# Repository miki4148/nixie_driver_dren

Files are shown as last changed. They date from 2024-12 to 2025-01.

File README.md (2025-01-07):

# Modular nixie tube clock system
Project overview

A versatile and customizable driver for Nixie tube clocks. This project focuses on developing hardware and firmware to drive Nixie tubes, allowing you to create various retro-style displays with ease.

---

## Features

- **Modular design**: Interchangeable pieces with efficient management of high voltages required by nixie tubes.
- **Customizable Firmware**: Adjust timing  of various displayed things at will.
- **Support for Various Tubes**: Compatible with [IN-12A](https://www.tube-tester.com/sites/nixie/dat_arch/IN-12A_IN-12B_03.pdf), [IN-12B](https://www.tube-tester.com/sites/nixie/dat_arch/IN-12A_IN-12B_03.pdf) and more.
- **Easy Assembly**: Simple PCB design with detailed instructions.
- **Real-Time Clock Integration**: In the future, RTC modules may be integrated into the project.

---

## Hardware

### Components

1. Nixie Tubes (e.g. [IN-12A](https://www.tube-tester.com/sites/nixie/dat_arch/IN-12A_IN-12B_03.pdf) or [IN-12B](https://www.tube-tester.com/sites/nixie/dat_arch/IN-12A_IN-12B_03.pdf))
2. Regulated Power Supply (12V DC output)
3. Microcontroller (e.g. STM32 family)
4. Maybe RTC Module? (e.g. DS3231)
5. Darlington Arrays (e.g. SN75468)
6. Demultiplexers (e.g. CD4028B)
7. Boost controller ([UCC380x](https://www.ti.com/lit/ds/symlink/ucc3800.pdf) family)
8. Resistors, Capacitors, Connectors etc.
9. PCB (Custom-designed for this project)

## Driver + PSU

The circuit consists of a boost converter which steps up the supply voltage to 170VDC. Such voltage is sufficient for ionization of the low-pressure gas mixture inside the tube at room temperature (without the need of white-hot cathode).

After long battle against procrastination, layout for the driver board emerged (see [driver schematic](/files/NixieDriverEvenSmallerNoDot/NixieDriverEvenSmallerNoDot.pdf)). Detailed description will follow in subsequent sections.

<p align="center">
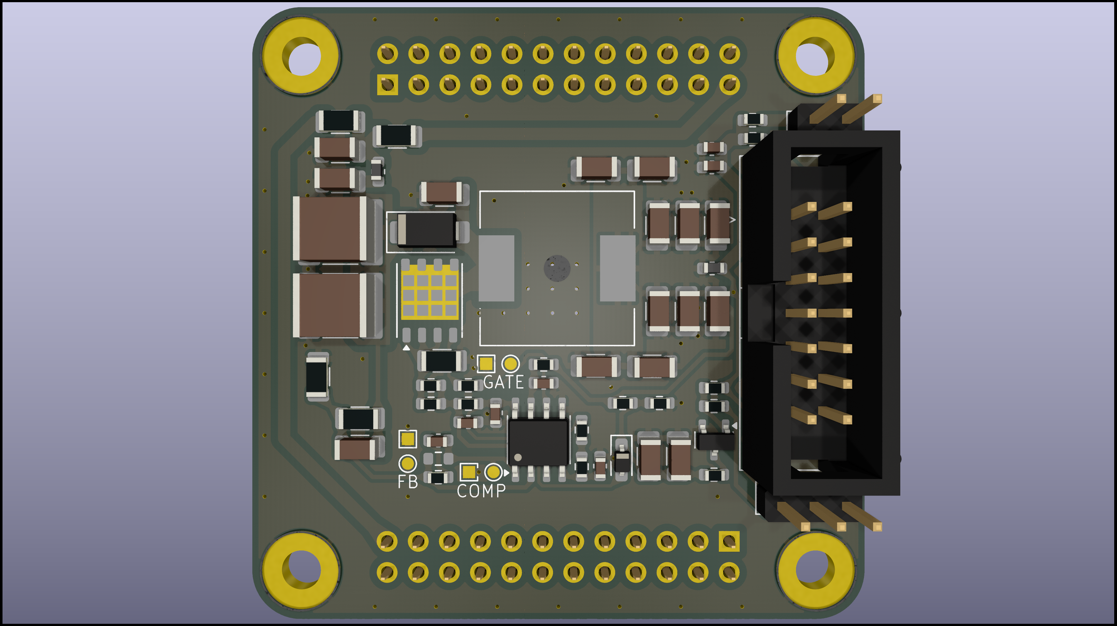
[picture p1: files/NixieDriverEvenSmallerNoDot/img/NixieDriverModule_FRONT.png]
  
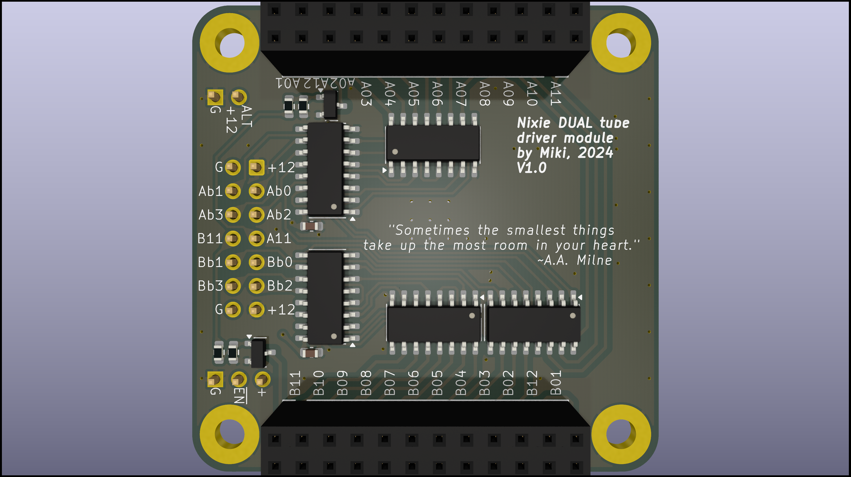
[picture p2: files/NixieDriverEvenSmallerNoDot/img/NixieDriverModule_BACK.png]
  
</p>

<p align="center">
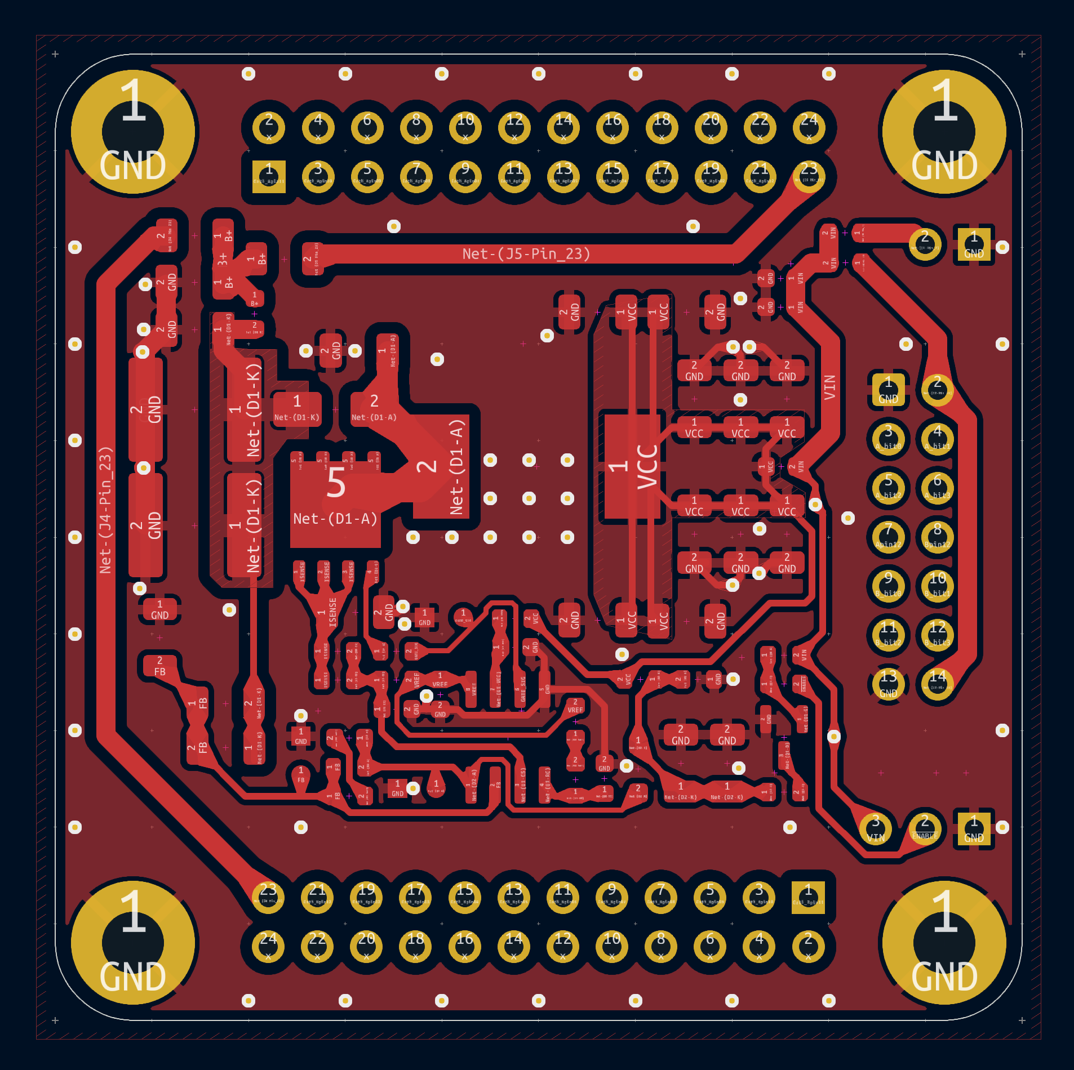
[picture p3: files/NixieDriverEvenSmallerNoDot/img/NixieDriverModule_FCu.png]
FCu
  
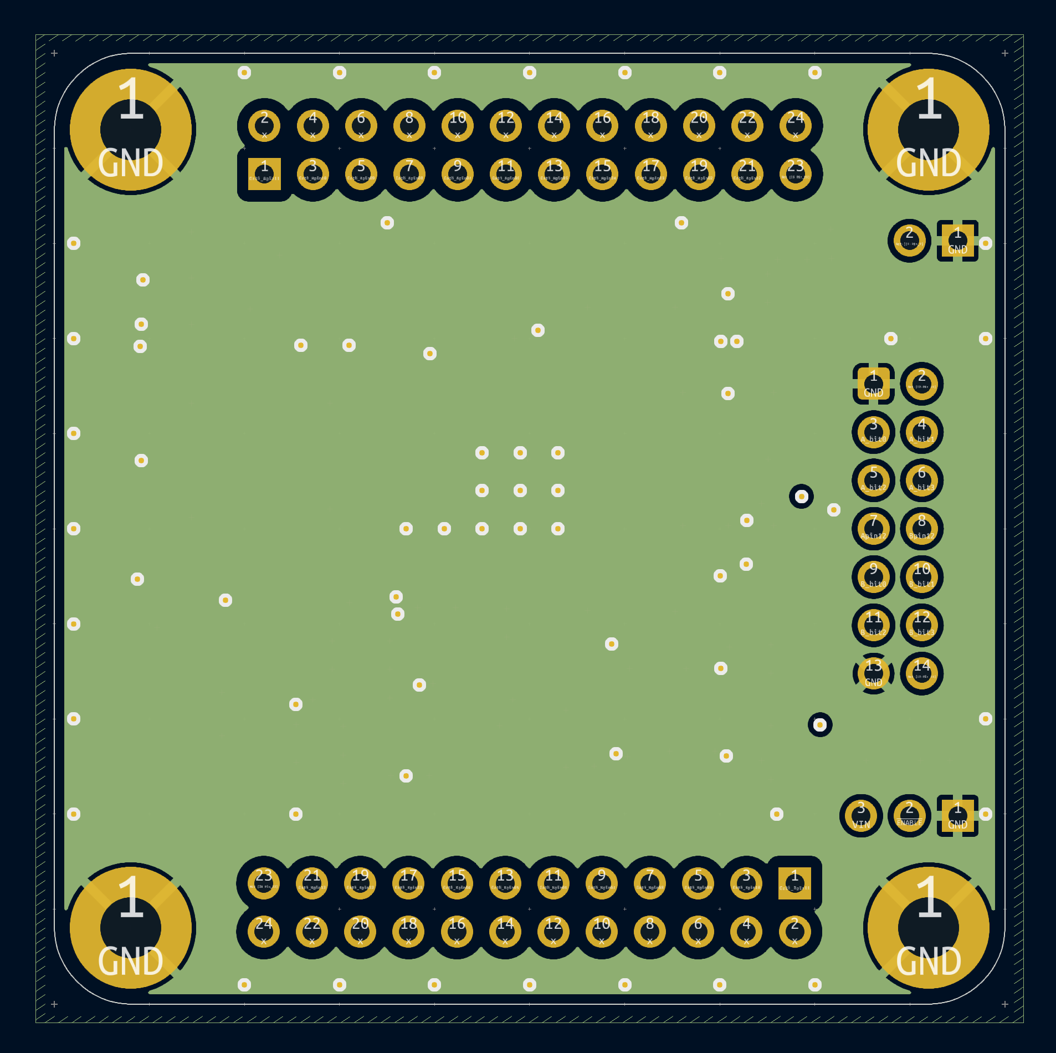
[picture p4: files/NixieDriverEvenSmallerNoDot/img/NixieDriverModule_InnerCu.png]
InnerCu
  
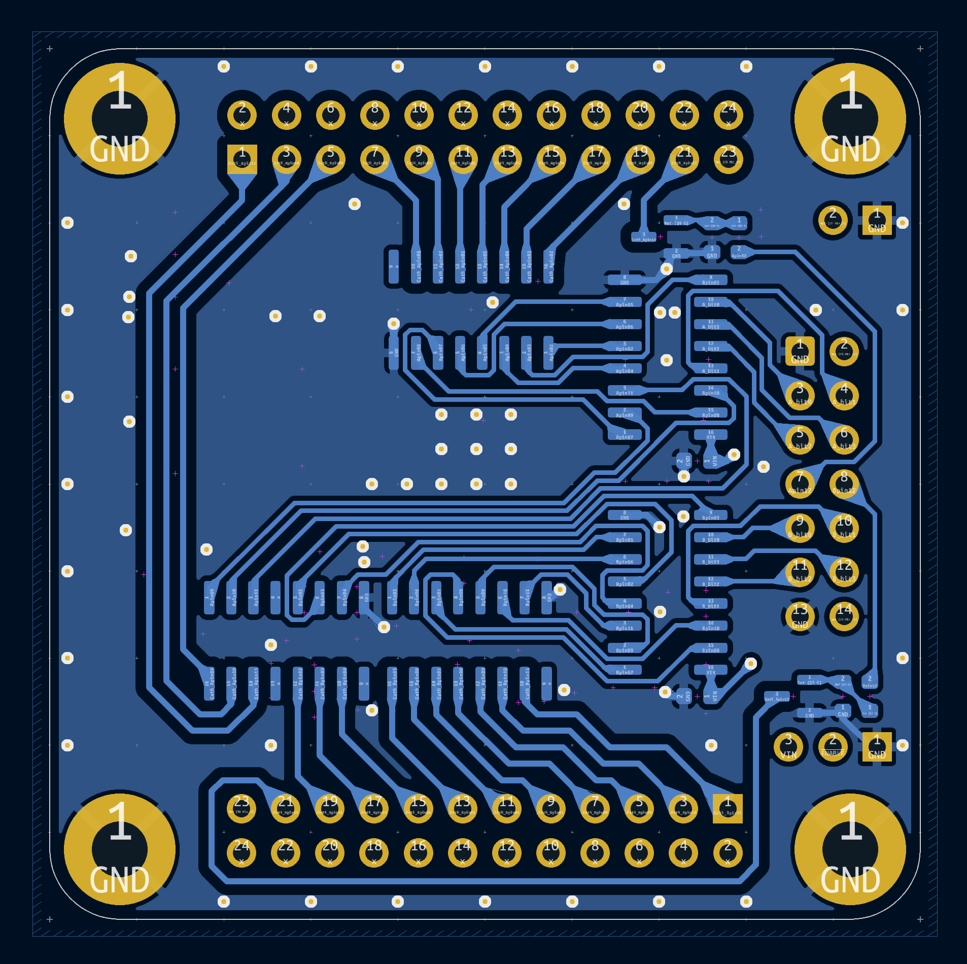
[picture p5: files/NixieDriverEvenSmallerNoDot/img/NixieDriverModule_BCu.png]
BCu
  
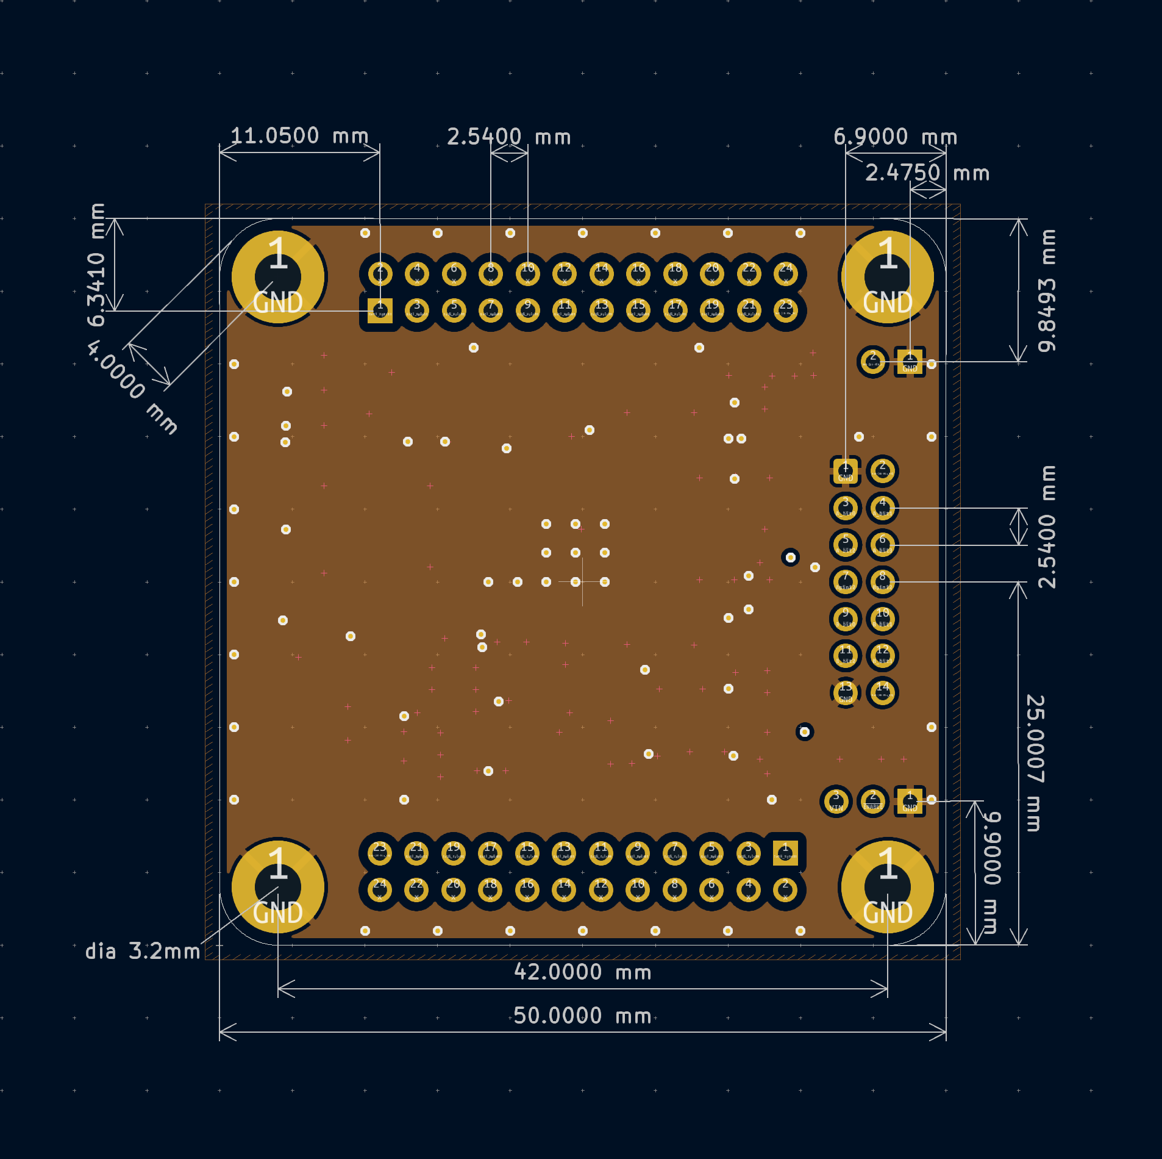
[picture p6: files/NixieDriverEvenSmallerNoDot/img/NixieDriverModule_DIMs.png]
Dimensions
  
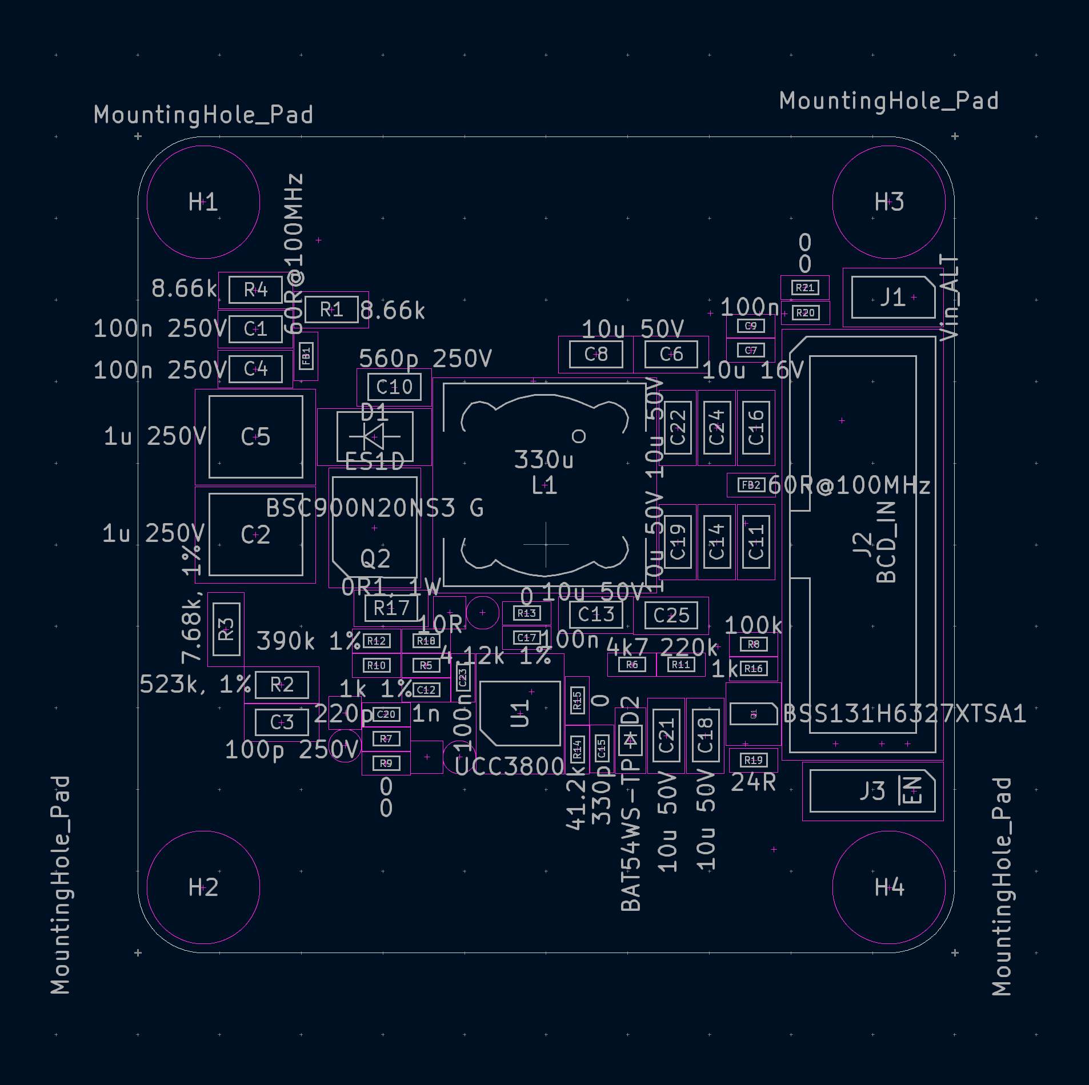
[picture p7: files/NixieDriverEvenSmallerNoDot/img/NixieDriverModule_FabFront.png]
FFab
  
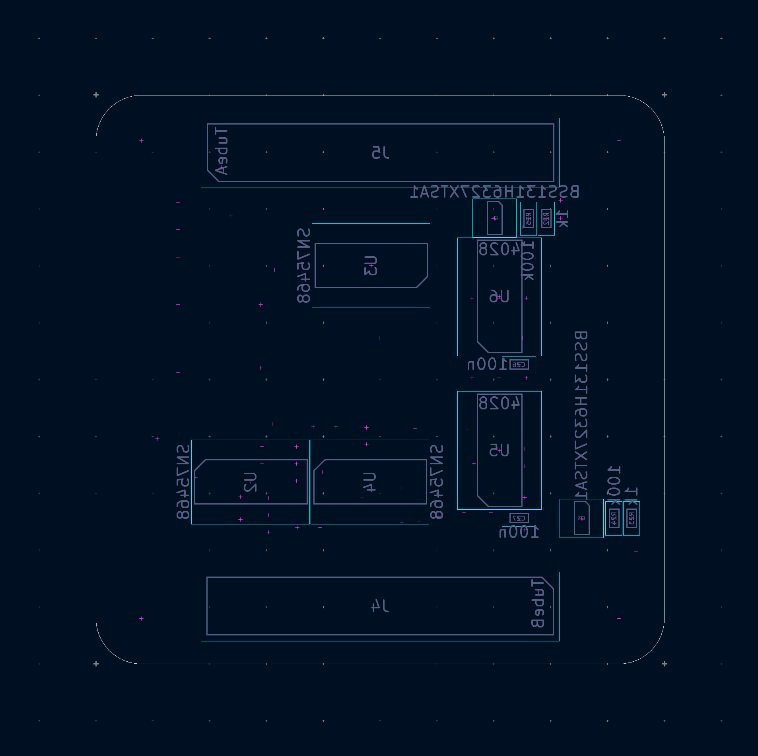
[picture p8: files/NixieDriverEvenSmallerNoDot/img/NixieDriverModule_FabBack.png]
BFab
  
</p>

Insulation Displacement Cable connector was chosen as the main medium of communication w/ the micro. This was a direct result of author's recent traumatic experiances and many hours of fruitless work trying to wire previous device using old solid-copper wires which were nearly unsolderable and brittle beyond comprehension. So ribbon cable it is.
Alternative and secondary I/Os were banished to ordinary pin headers for simplicity.

The other half of the circuit is basically massive demultiplexing and buffering array. The good news is that not every cathode needs to be operated idependently but rather only one (two maybe) digit per tube lights up at one time. This points to BCD (binary-coded decimal) converters (4028 IC used) and a simple buffering for commas as they may have to be used independently.

Note author's love for hardcore poetry insertion.

## Dual tube adapter

Someone must hold the tubes in place so here it is: (see [adapter schematic](/files/NixieDriverTwoTubesSockets/NixieDriverTwoTubesSockets_Schematic.pdf))

<p align="center">
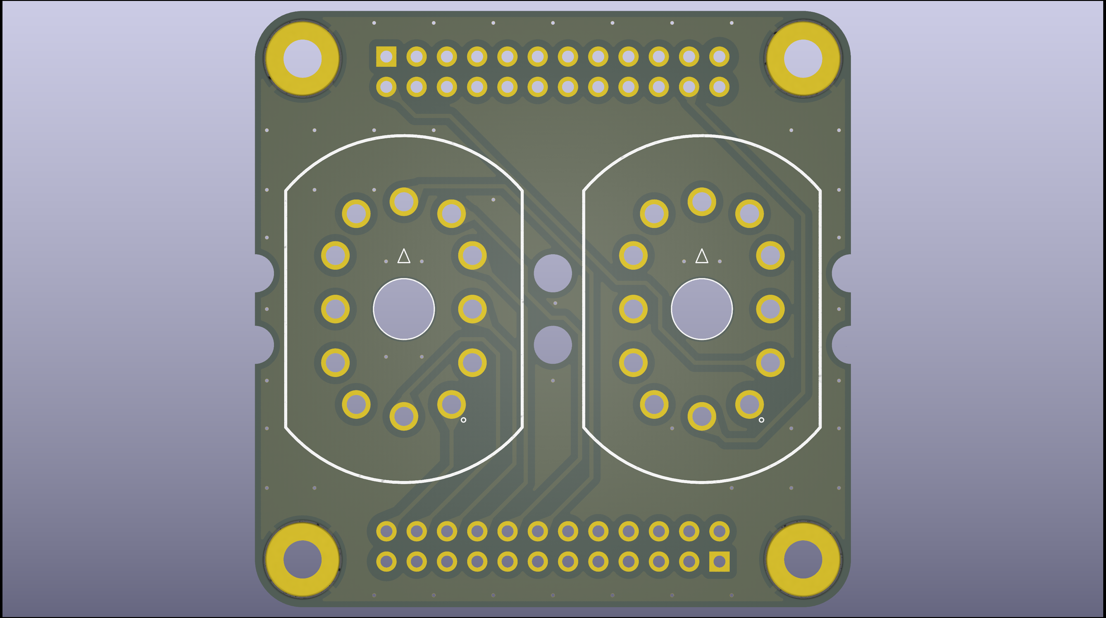
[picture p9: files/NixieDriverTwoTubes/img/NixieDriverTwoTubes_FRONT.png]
Tube holder front
  
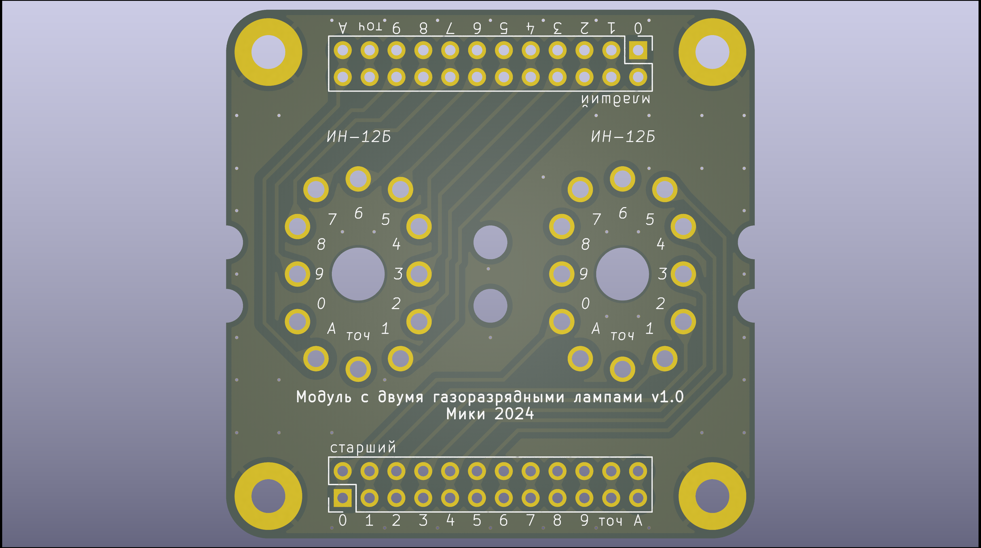
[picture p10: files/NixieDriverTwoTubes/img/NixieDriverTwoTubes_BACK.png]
Tube holder back
  
</p>
Holes in pcb in the middle of the tubes' footprints are an answer to the glass short feature at the base, a remainder after sealing process.
Other holes increase versatility in case someone wished to insert leds in them to achieve obligatory flashing in the space between glowing numerals.
Note the attempt to match writing on the pcb to native Muttersprache of the late glassblowers responsible for birthing of IN-12s.

### Dual tube adapter w/ sockets

Socket adaptation requires different footprint and much denser layout.

<p align="center">
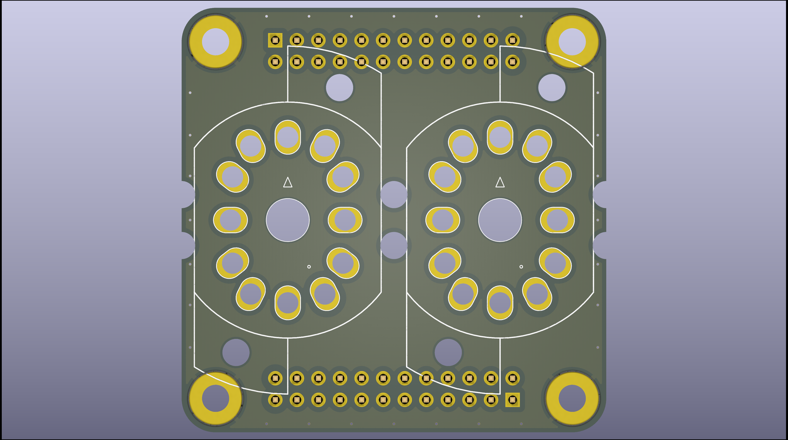
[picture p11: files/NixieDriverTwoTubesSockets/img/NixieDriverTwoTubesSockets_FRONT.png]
NixieDriverTwoTubesSockets_FRONT
  
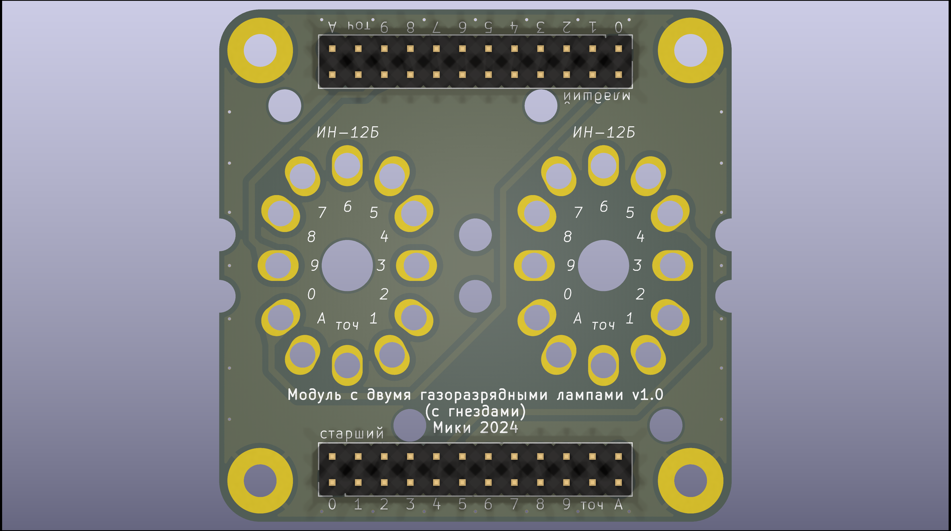
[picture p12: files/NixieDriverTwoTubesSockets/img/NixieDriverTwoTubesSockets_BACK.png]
NixieDriverTwoTubesSockets_BACK
  
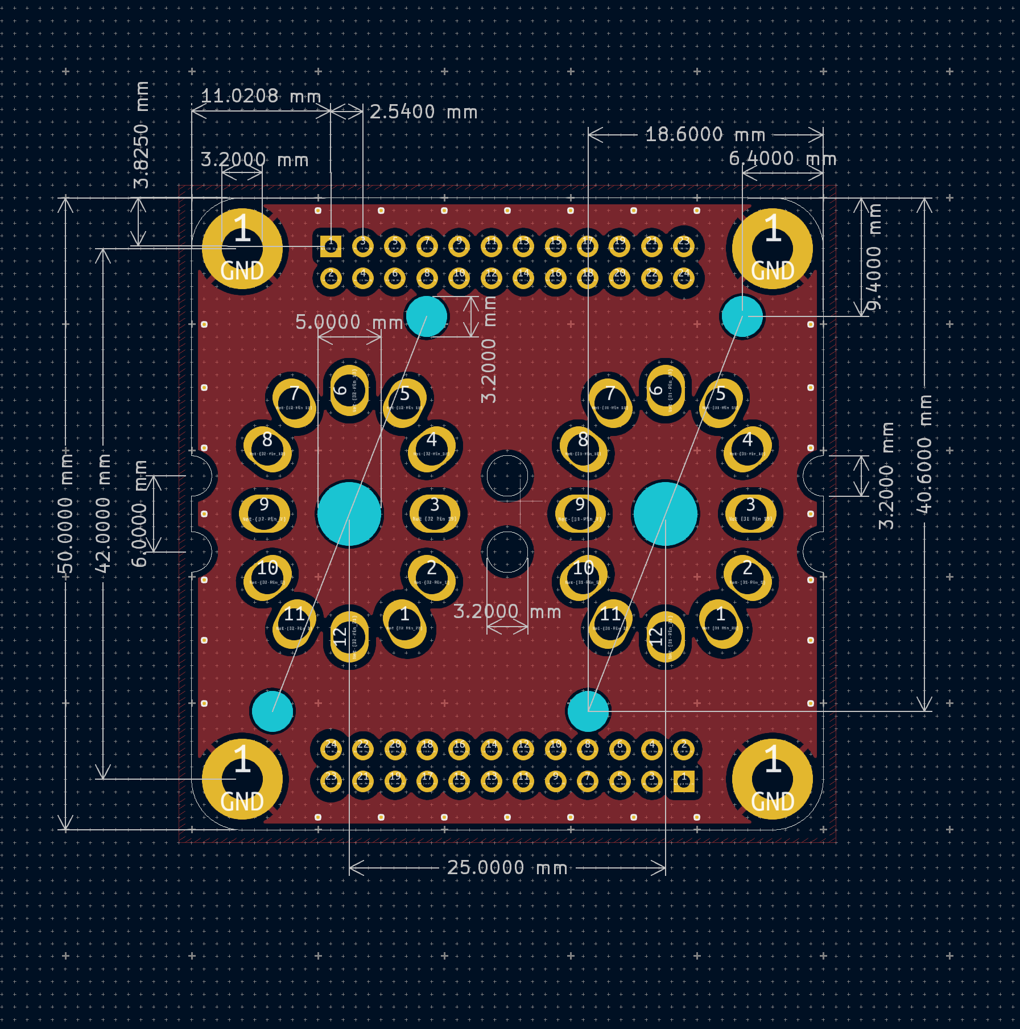
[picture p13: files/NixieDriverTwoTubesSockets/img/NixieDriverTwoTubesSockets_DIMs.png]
NixieDriverTwoTubesSockets_DIMs
  
</p>
6 layers, yes:
<p align="center">
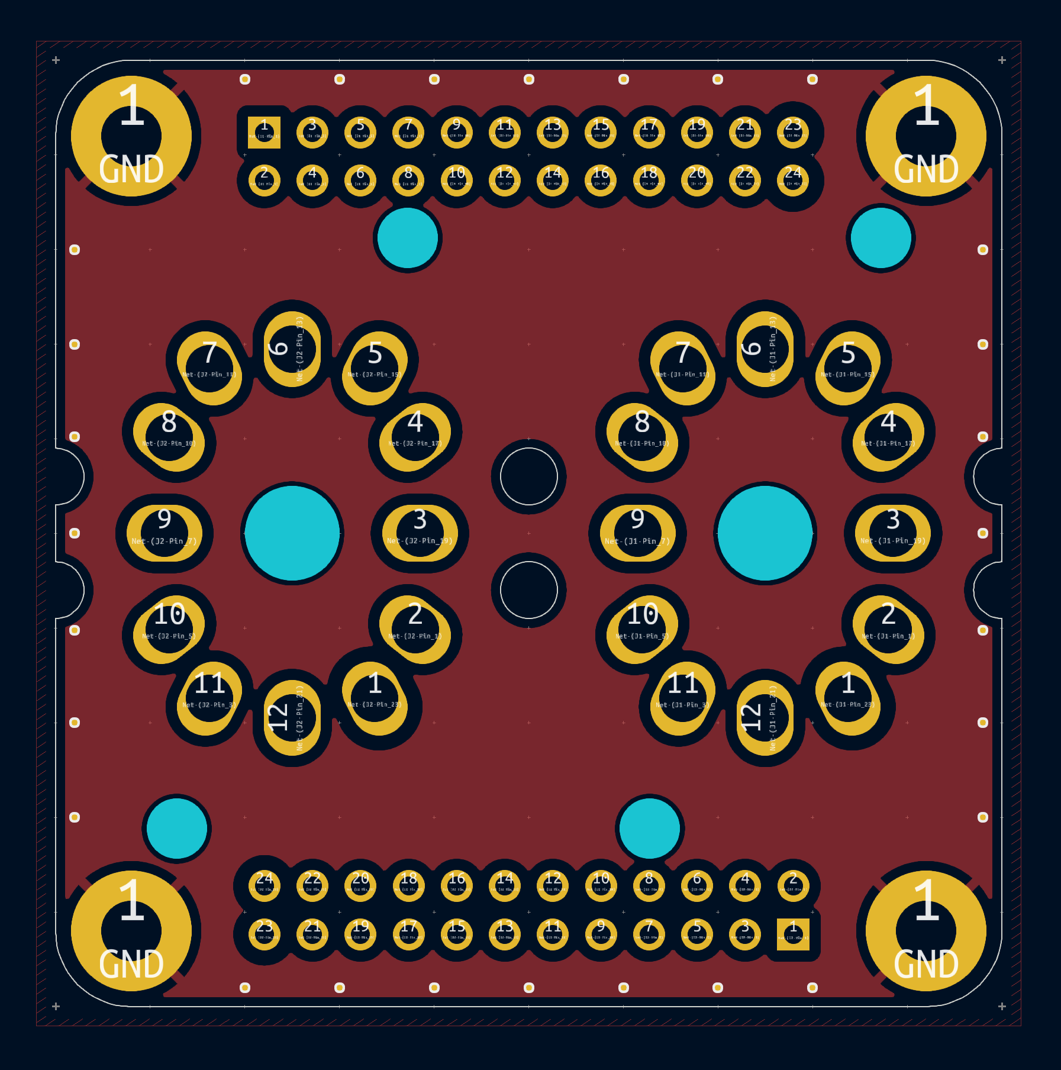
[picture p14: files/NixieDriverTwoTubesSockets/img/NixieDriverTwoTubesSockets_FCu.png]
  
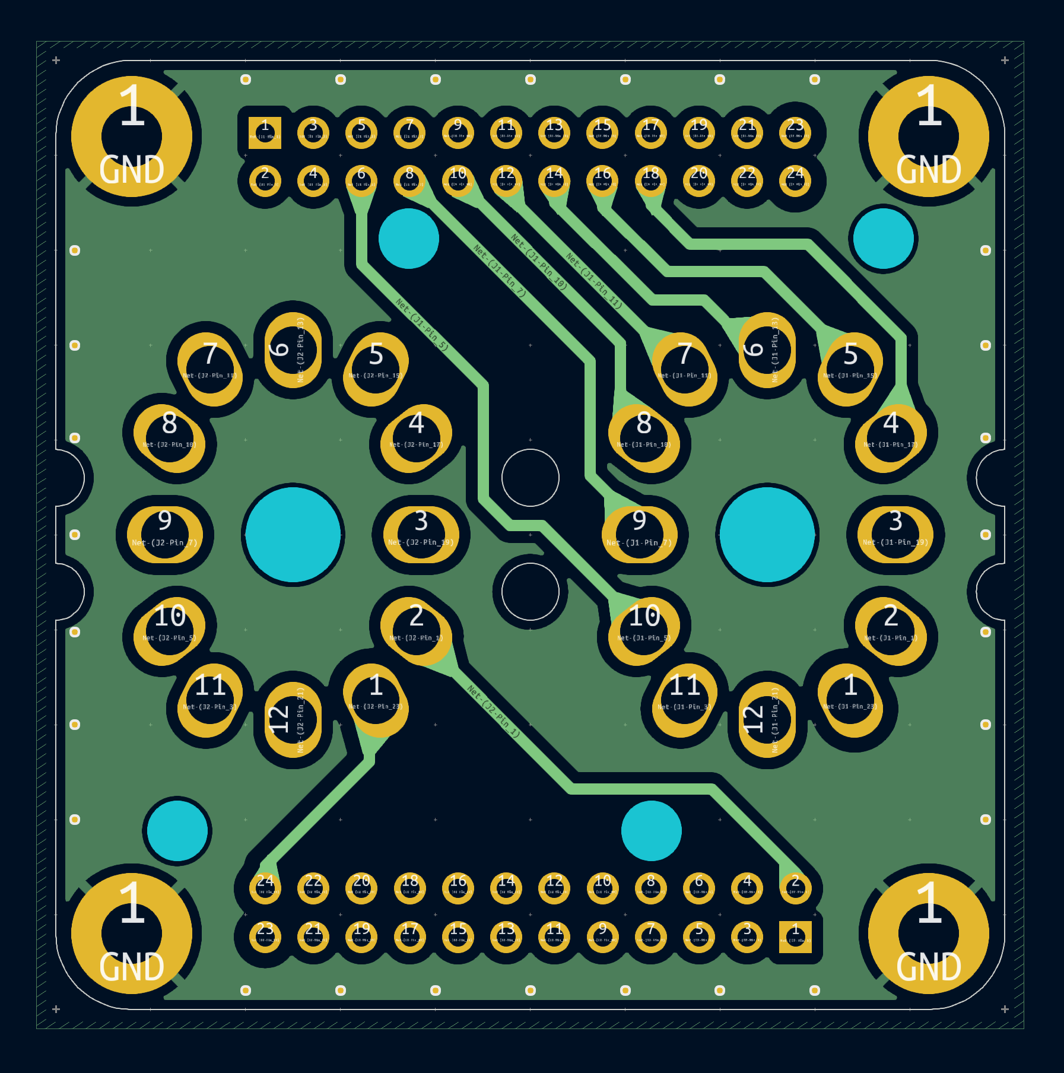
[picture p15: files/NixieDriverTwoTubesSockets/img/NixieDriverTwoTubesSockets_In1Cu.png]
  
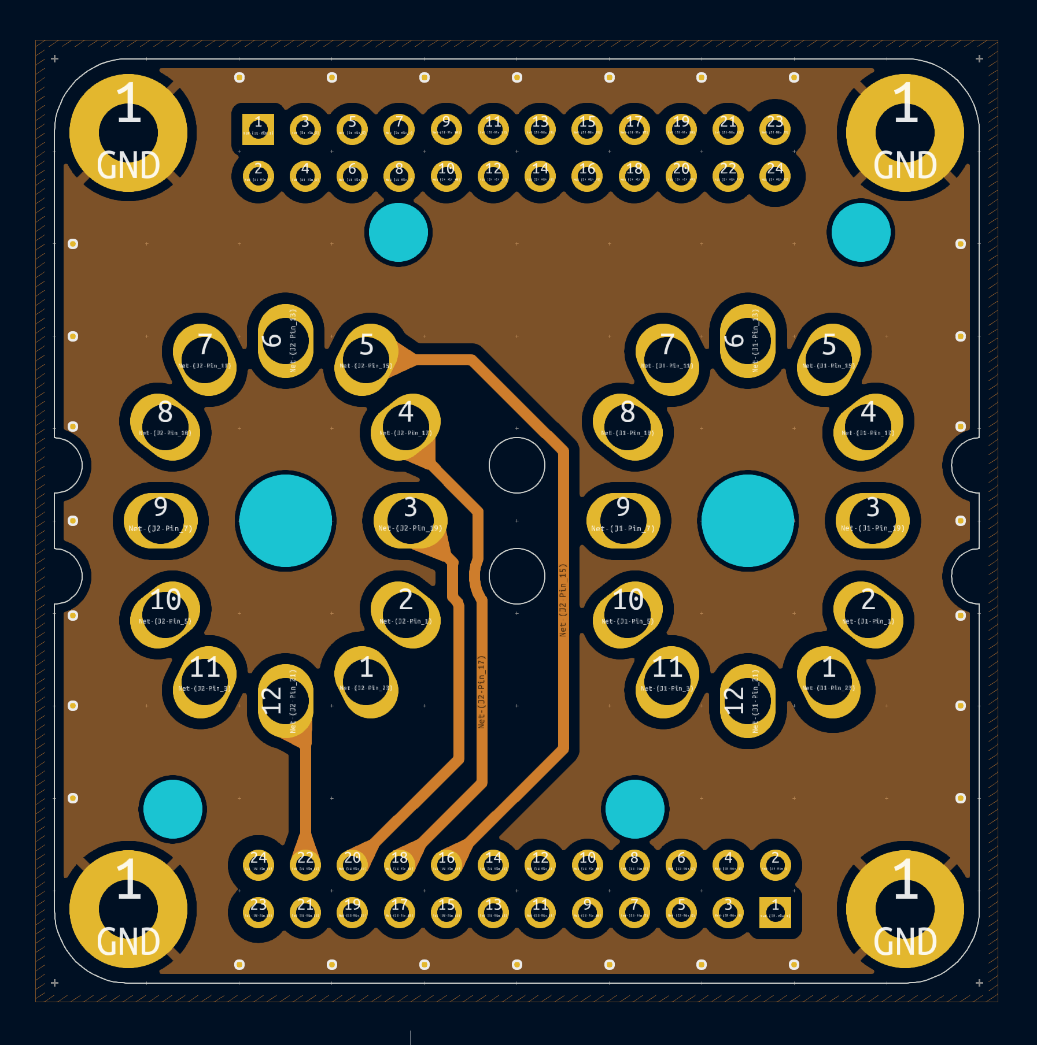
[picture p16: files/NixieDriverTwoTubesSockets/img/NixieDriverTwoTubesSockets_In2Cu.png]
  
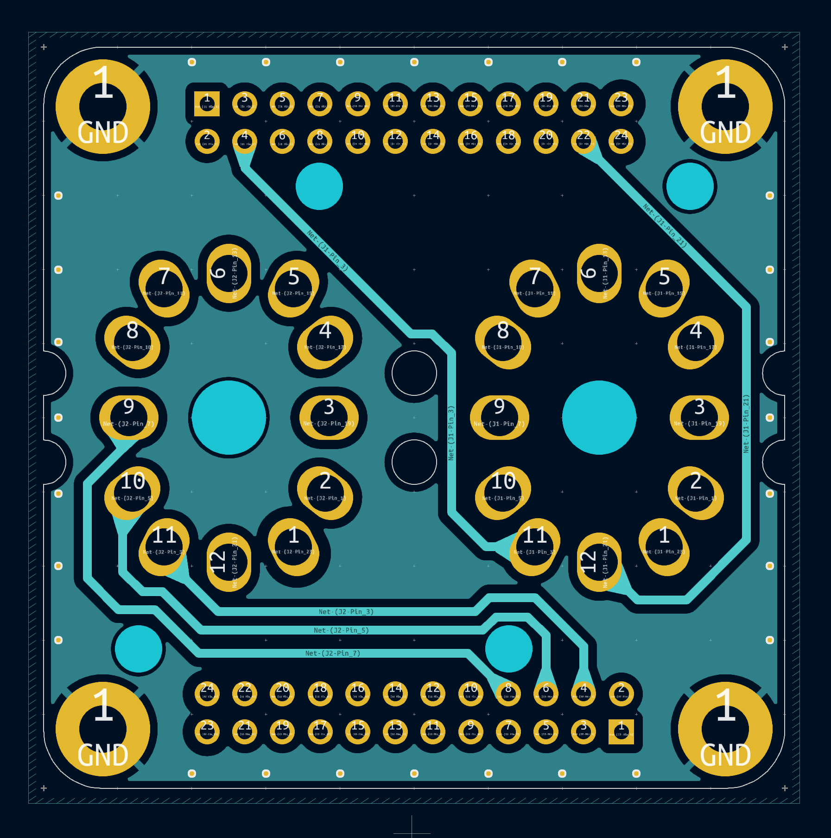
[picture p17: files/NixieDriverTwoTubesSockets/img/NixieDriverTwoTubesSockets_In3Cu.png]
  
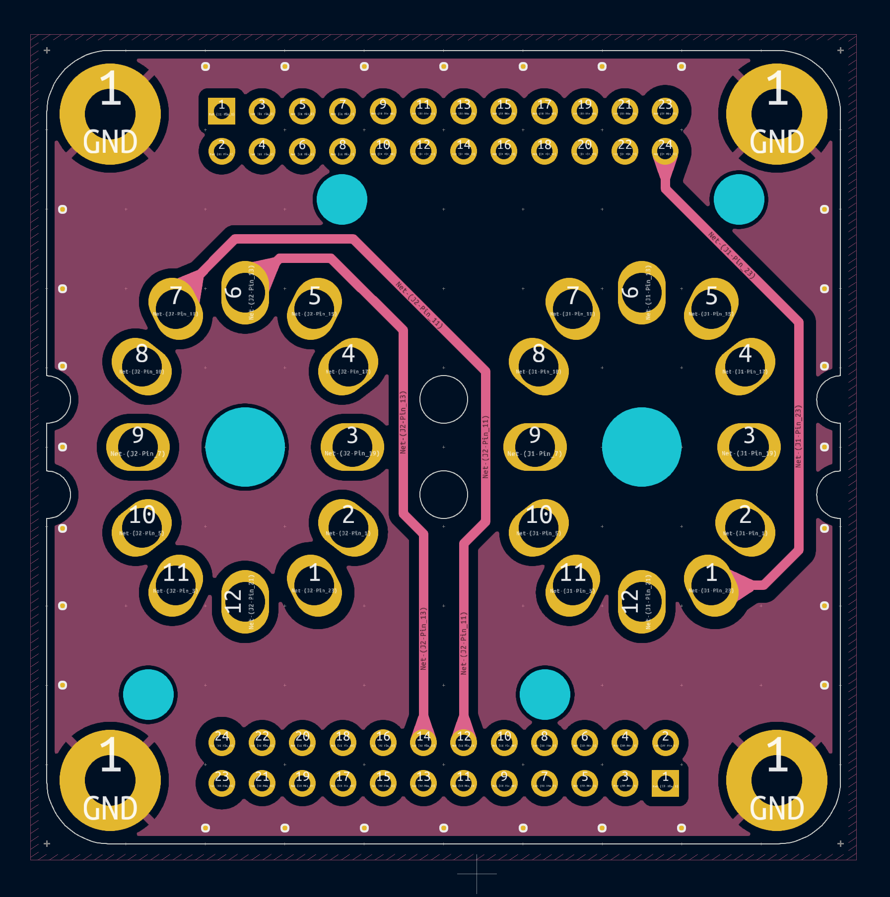
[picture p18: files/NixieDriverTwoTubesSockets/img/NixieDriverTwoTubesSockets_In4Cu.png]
  
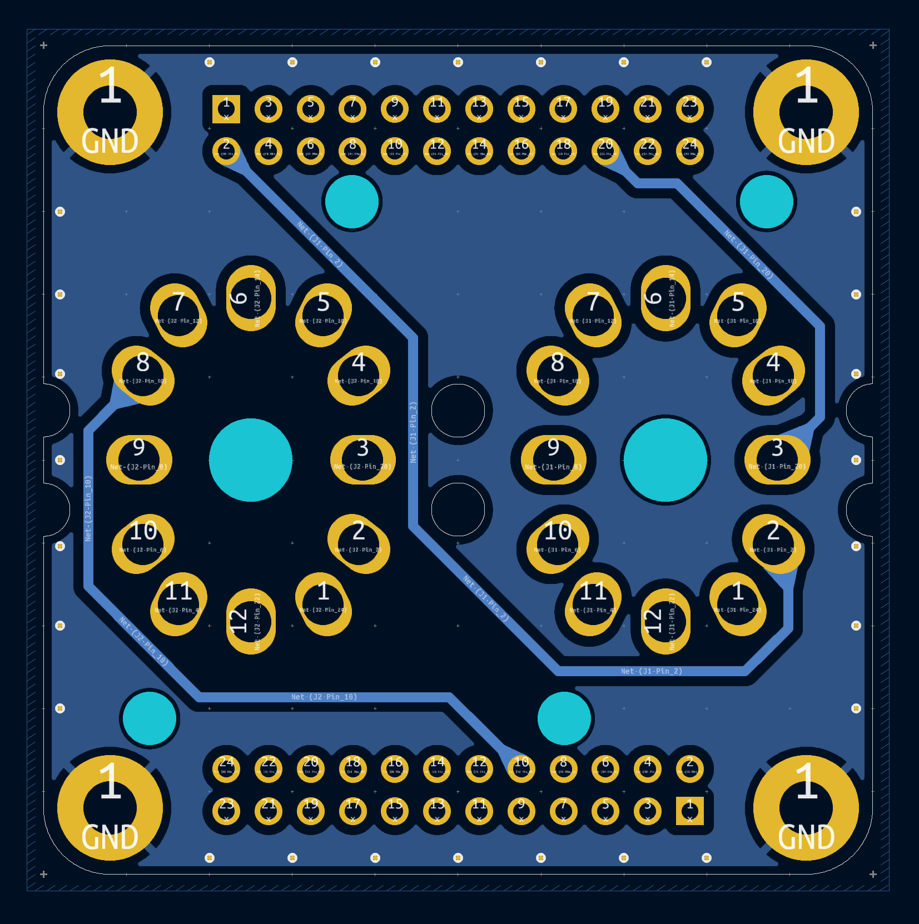
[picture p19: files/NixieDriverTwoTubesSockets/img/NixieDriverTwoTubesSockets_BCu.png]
  
</p>

---
<!-- 
## Software Setup

### Prerequisites
- TBA

## Usage
Assemble the hardware as per the provided schematics.
Power the circuit using the recommended voltage specifications.

At vero eos et accusamus et iusto odio dignissimos ducimus qui blanditiis praesentium voluptatum deleniti atque corrupti quos dolores et quas molestias excepturi sint occaecati cupiditate non provident, similique sunt in culpa qui officia deserunt mollitia animi, id est laborum et dolorum fuga. Et harum quidem rerum facilis est et expedita distinctio. Nam libero tempore, cum soluta nobis est eligendi optio cumque nihil impedit quo minus id quod maxime placeat facere possimus, omnis voluptas assumenda est, omnis dolor repellendus. Temporibus autem quibusdam et aut officiis debitis aut rerum necessitatibus saepe eveniet ut et voluptates repudiandae sint et molestiae non recusandae. Itaque earum rerum hic tenetur a sapiente delectus, ut aut reiciendis voluptatibus maiores alias consequatur aut perferendis doloribus asperiores repellat. 

---
-->

## Design process

Initially, the goal was to power and control 6-8 tubes (up to 88 cathodes) which very quickly became a routing nightmare. Also the lebensraum cost accumulated very quickly so small pcbs became a necessity. 
But first things first.

## Assumptions

For dual tube version

1. step-up converter from regulated **12VDC** in to **170VDC** out;
2. Switching frequency: sth like **110kHz**
3. Output regulation method: **PWM**
4. Power delivered to the load: **2.04mW** (4 symbols, up to 3mA per cathode at 170V);
5. Small size: 50mm x 50mm boards (cheap, easy to throw away)
6. 22 cathodes, 2 out of which will stay on and **2 commas w/ independent control**

## First try

Ok. so let's try single phase boost topology in Constant Current Mode. 

In that case helpful can be ic dedicated to boost converter control such as [UCC380x](https://www.ti.com/lit/ds/symlink/ucc3800.pdf) family from TI:

<p align="center">
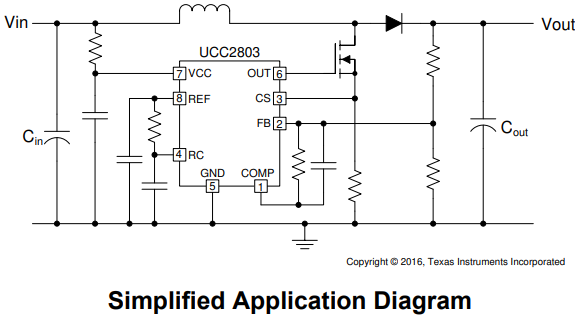
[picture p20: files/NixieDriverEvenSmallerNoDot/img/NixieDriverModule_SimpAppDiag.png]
UCC380X Simplified Application Diagram
  
</p>

<p align="center">
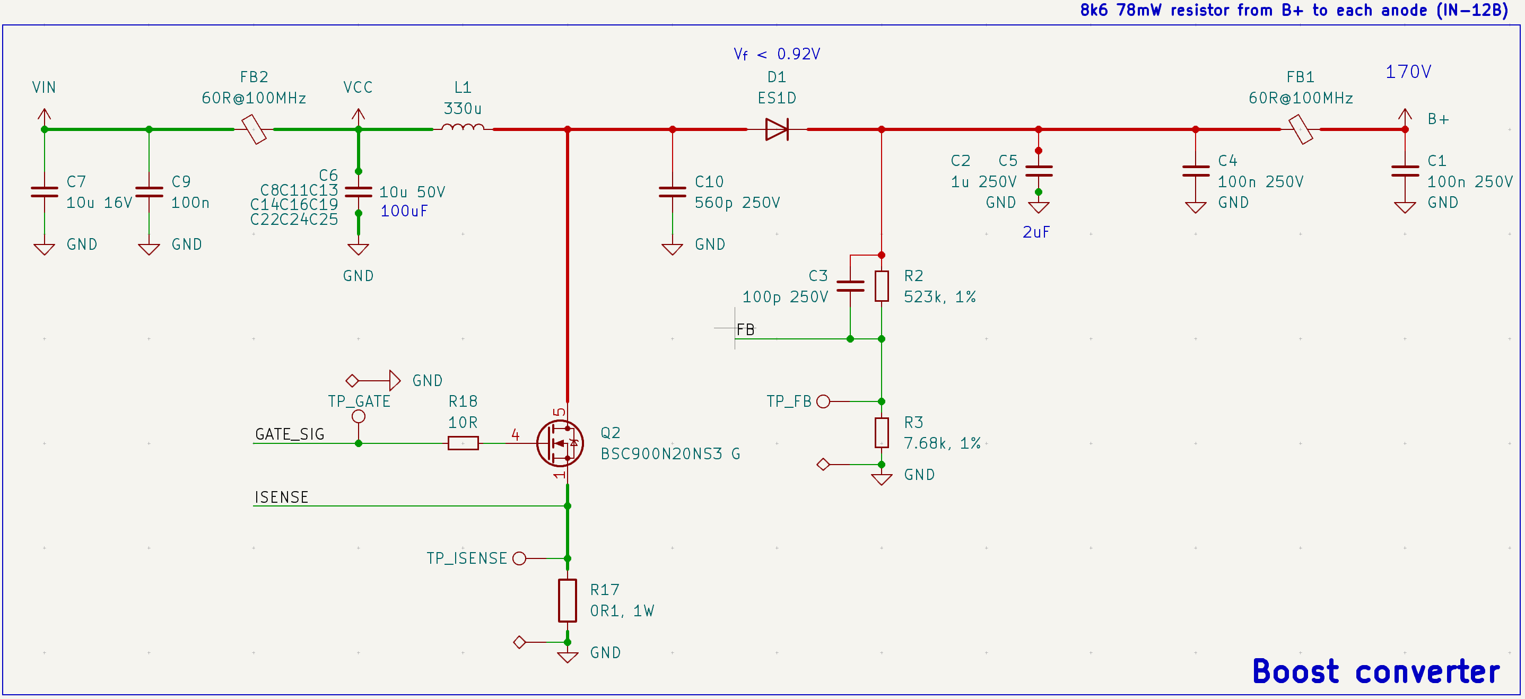
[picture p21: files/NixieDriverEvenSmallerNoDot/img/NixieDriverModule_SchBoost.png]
Boost converter schematic
  
</p>

<p align="center">
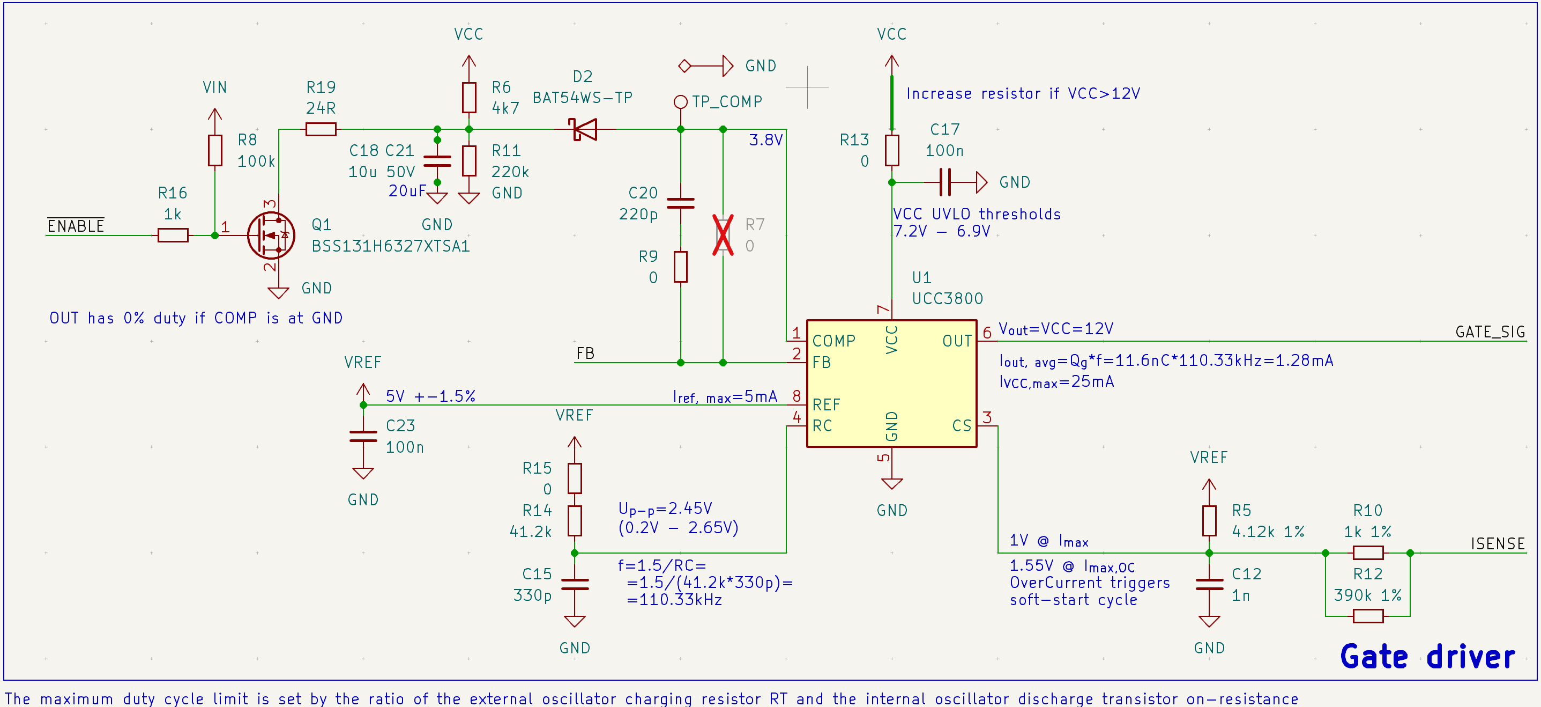
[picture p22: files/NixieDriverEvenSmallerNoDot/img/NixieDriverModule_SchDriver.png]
Driver schematic
  
</p>

---

### Duty cycle and PWM Controller

Assuming 80% efficiency, DC needed is given by 

```math
U_{out} = \frac{U_{in} \cdot \eta}{1-D}  \implies  D = 1 - \frac{12V \cdot 0.8}{170V} \approx \mathbf{0.944}
```

so half of the [UCC380x](https://www.ti.com/lit/ds/symlink/ucc3800.pdf) family is already out.

Let's see:
<!-- <img src="NixieDriverModule_UCC38xxComp.png" alt="UCC38xx family comparison" > -->
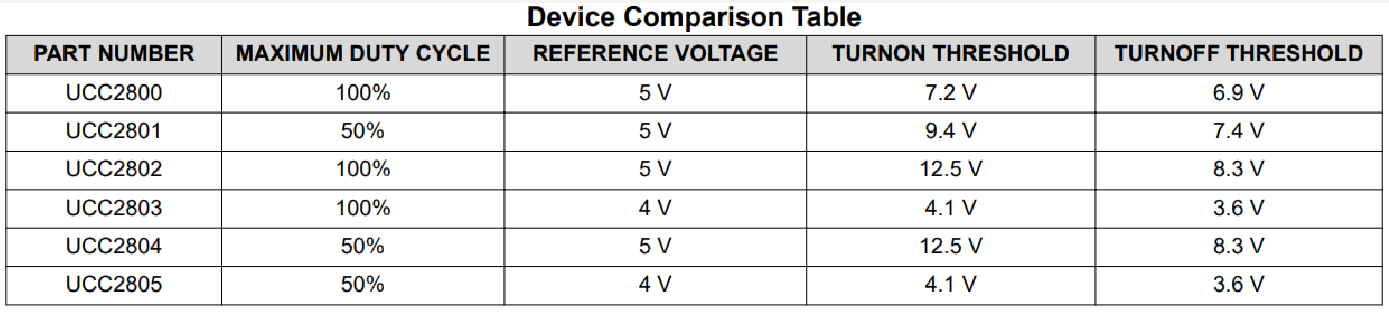
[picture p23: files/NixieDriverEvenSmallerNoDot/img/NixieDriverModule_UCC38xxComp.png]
UCC380X family

After DC calculation, only '0, '2 and '3 are left. As input voltage is 12V, let's look at histeretic UnderVoltage LockOut thresholds. '2 version will never even turn on and '3's UVLO range is far too low to provide any protection.

> That leaves [UCC3800](https://www.ti.com/lit/ds/symlink/ucc3800.pdf) as the last chip standing.

---

### Oscillator

As described in [UCC3800](https://www.ti.com/lit/ds/symlink/ucc3800.pdf)'s datasheet, the frequency of operation is set by RC constant, so to achieve 110kHz we need

```math
f = \frac{1.5}{RC} = \frac{1.5}{\mathbf{41.2k \Omega} \cdot \mathbf{330pF}} \approx 110.33kHz
```

> C15 = **330 pF** C0G
> R14 = **41.2 kΩ** ±1%
> R15 = 0 Ω

---

### Inductor

Mean output current:

```math
I_{out} = \frac{1}{T} \int_{0}^{T} i_{out} \, dt = \frac{1}{T} (\frac{1}{2} \Delta i_{out} (1-D)T + i_{min}T) = \frac{1}{2} \Delta i_{out} (1-D) + i_{min}
```

As voltage across the inductor $` U_{L} = L \cdot \frac{\Delta i_{L}}{t_{on}} `$ and duty cycle $` D = \frac{t_{on}}{T} = t_{on} \cdot f `$, ripple current through the inductor is:

```math
\Delta i_{L} = \frac{U_{L} D}{f \cdot L}
```

so the mean output current:

```math
I_{out} = \frac{U_{in} D (1-D)}{2 f L}  + i_{min}
```

For continuous inductor current, **minimum current must be positive** ( $`i_{min} > 0`$ ). The lower bound on inductance is then given by:

```math
L \gt \frac{D \cdot U_{in} \cdot (1-D) }{ 2 \cdot f \cdot I_{out}} \approx 239.6 \mu H \implies \mathbf{L = 330 \mu H}
```

Inductor's ripple current:

```math
\Delta i_{L} = \frac{U_{L} D}{f \cdot L} = \frac{12V \cdot 0.944}{110.33kHz \cdot 330 \mu H} \approx 311.1 mA
```

Maximum current through the inductor:

```math
\mathbf{i_{L, max}} = i_{min} + \Delta i_{L} = I_{out} - \frac{1}{2} \Delta i_{L}(1 - D) + \Delta i_{L} \approx \mathbf{314.39 mA}
```
is also the maximum current through the switch.

> [DE1207-330](https://www.tme.eu/Document/d1f8b47d020ebf11f3b92c6891638dfa/de.pdf) shielded inductor from FERROCORE's "SMD Power Coil" family was chosen
- **330 μH**
- **471 mΩ** DC resistance
- 1207 package (12mm x 12mm x 8mm)

---

### Diode

> [ES1D](https://www.onsemi.com/pdf/datasheet/es1d-d.pdf) (SMA) was chosen as a cheap yet fast and powerful diode for its

- **200 V** Maximum Repetitive Reverse Voltage and
- **1 A** Average Rectified Forward Current with
- **30 A** pulse capability.

Note the **0.92 V** Forward Voltage @ 1 A

`This is the moment to point out the annoyingly circular character of such design methods. 
To choose the diode, it is necessary to know the max current it will have to handle but the value of its forward voltage drop is needed much earlier in duty cycle calculation. Expect further complaining about this in the upcoming sections.`

---

### Switch

> [BSC900N20NS3 G](https://www.infineon.com/dgdl/Infineon-BSC900N20NS3-DS-v02_02-en.pdf?fileId=db3a30432ad629a6012b144f6b0619db) (PG-TDSON-8) was deemed worthy:

- **200 V** $`V_{DS}`$
- **90 mΩ** max $`R_{DS(on)}`$
- **15.2 A** $`I_{D}`$
- 2.2 Ω typ $`R_{G}`$
- **11.6 nC** max $`Q_{g}`$

---

### Output capacitor

To filter the output signal, let's use capacitance of:

```math
\Delta U_{out} = \frac{I_{out}}{C_{out} \cdot f} \implies \mathbf{C_{out}} \gt \frac{12 mA}{0.1 V \cdot 110.33 kHz} \approx \mathbf{1.09 \mu F}
```

> [C5750X7R2E105K230KA](https://www.tme.eu/Document/3927045cdc4027c1c18ebf074683adec/c-series.pdf) (2220) from TDK's "C series"
- **2 μF** ± 10%
- **250 V** rated DC voltage
- **X7R** dielectric material

Note the ±15% temperature coefficient (capacitance change) over the whole temp. range ( –55 to +125 °C )

In the design, two 2220 footprints were used to accomodate various capacitor configurations.

---

### Current sensing network

<p align="center">
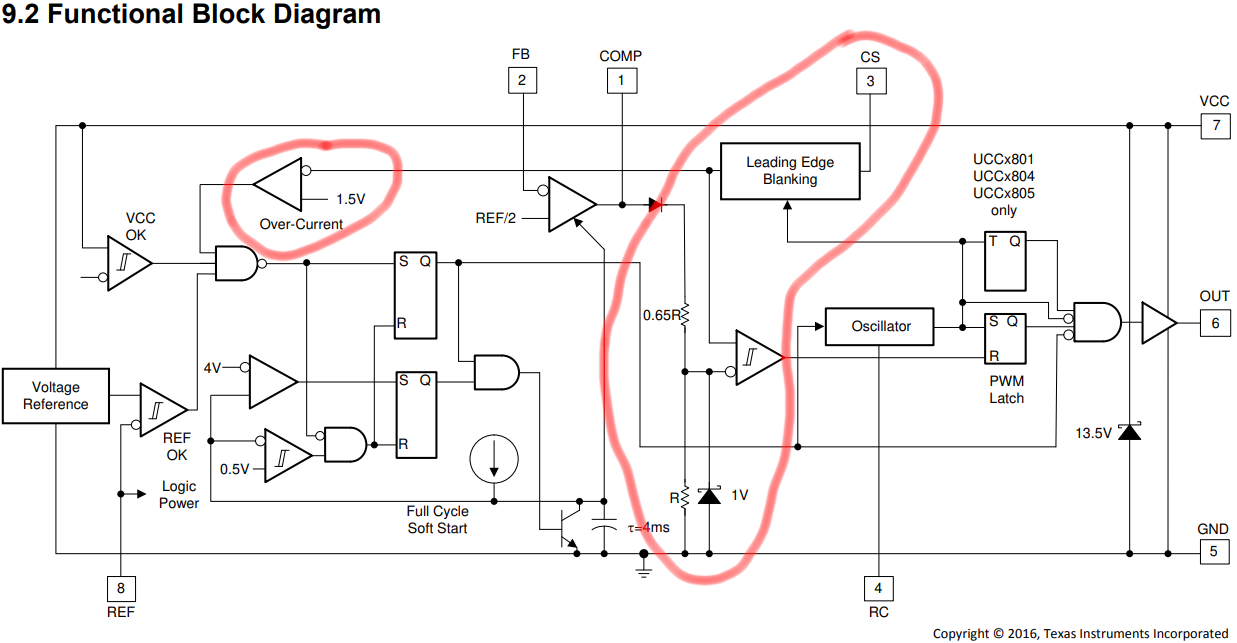
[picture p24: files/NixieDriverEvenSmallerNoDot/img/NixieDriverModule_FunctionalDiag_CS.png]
Current Sensing
  
</p>

A 1-V (typical) cycle-by-cycle current limit threshold is incorporated into the [UCC380x](https://www.ti.com/lit/ds/symlink/ucc3800.pdf) family. Resistors R9
and R11 bias the actual current sense resistor voltage up, allowing a small current sense amplitude to be used.

> [ERJ-8BWFR100V](https://industrial.panasonic.com/cdbs/www-data/pdf/RDN0000/AOA0000C313.pdf) (1206) thick film chip resistor from PANASONIC

- **0.1 Ω** ±1%
- 100ppm/°C

max 314.39 mA over 0.1R is 31.439mV so 968.561 mV offset is needed

```math
U_{offset} = \frac{R9}{R11 + R9} \cdot U_{ref} \implies \mathbf{\frac{R11}{R9}} = \frac{5 V}{0.968561 V} - 1 = 4.1623
```

> R5 = **4.12 kΩ** ±1%
> R10 = **1 kΩ** ±1%
> R12 = **390 kΩ** ±1%

TODO:

---

### Voltage feedback loop

<p align="center">
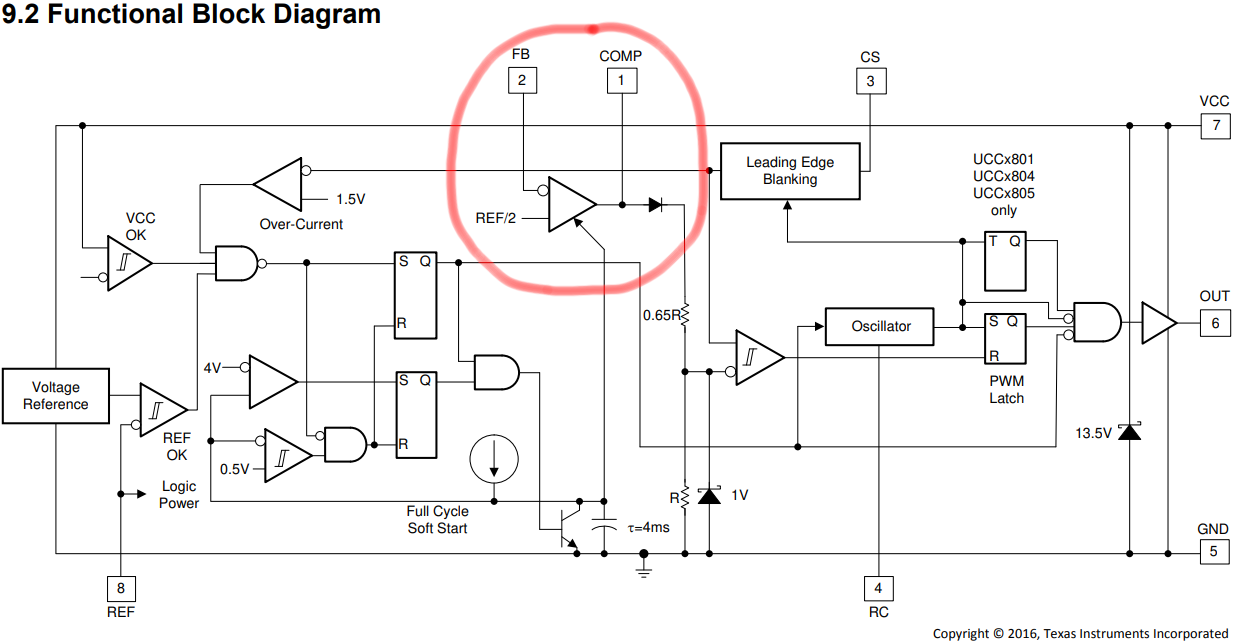
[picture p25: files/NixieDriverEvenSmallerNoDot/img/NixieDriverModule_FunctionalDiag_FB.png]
Voltage FeedBack
  
</p>

Voltage at FB pin is compared to **reference halved** so a voltage divider of:

```math
\frac{U_{ref}}{2} = \frac{U_{out} \cdot R3}{R3 + R2} \implies \mathbf{\frac{R2}{R3}} = \frac{170 V}{2.5 V} - 1 = 67 = \mathbf{\frac{514.56 k\Omega}{7.68 k\Omega}}
```

is needed. In practice, choosing from ±1% E96 series:

> **R2 = 523 kΩ** ±1%
> **R3 = 7.68 kΩ** ±1%

This tolerance implies output voltage range of [169.3 V; 176.2 V] and about 300-μA leakage current.

---

## Simulation

Quick and idealized circuit, using values calculated above, was simulated in [PLECS](https://www.plexim.com/products/plecs) - simulation platform for power electronic systems. 

After some time, our system reached steady state which is demonstrated below:

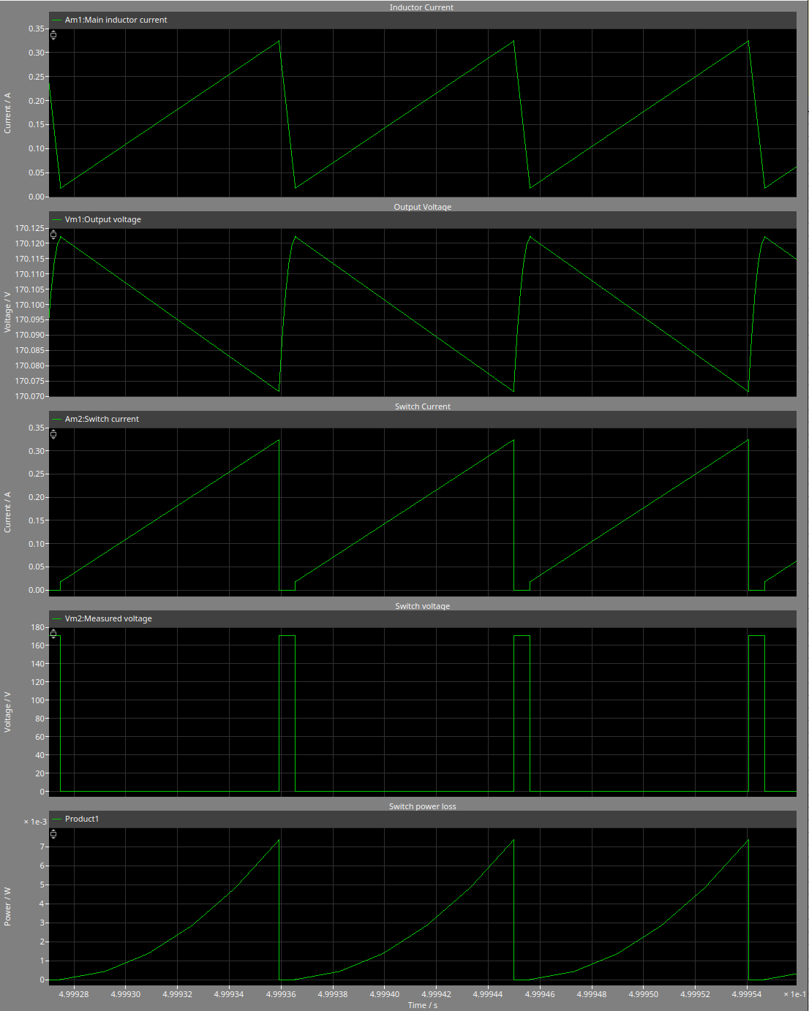
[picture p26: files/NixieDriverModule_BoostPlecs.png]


As we can see, all noise from FET turning on/off was omitted as well as parasitic capacitances all across the system. This simulation is only a means of reassurance that calculations weren't too far off and so the project can advance into 'spending money' stage.

---

## Miscellaneous

TODO:  y LaTeX does not work in md on mobile?!

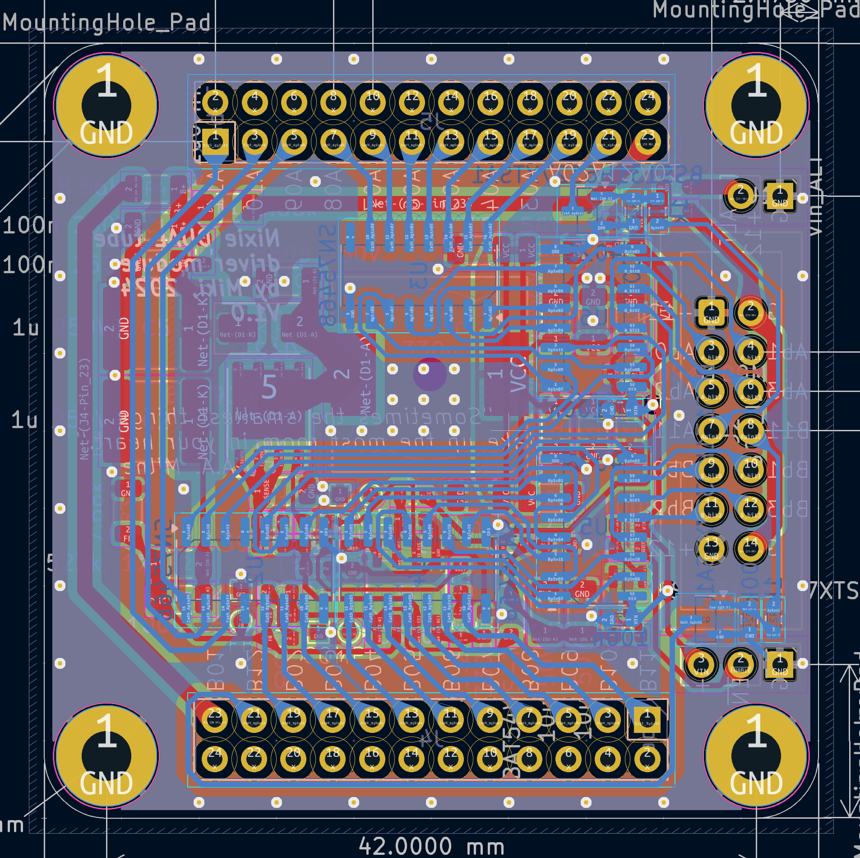
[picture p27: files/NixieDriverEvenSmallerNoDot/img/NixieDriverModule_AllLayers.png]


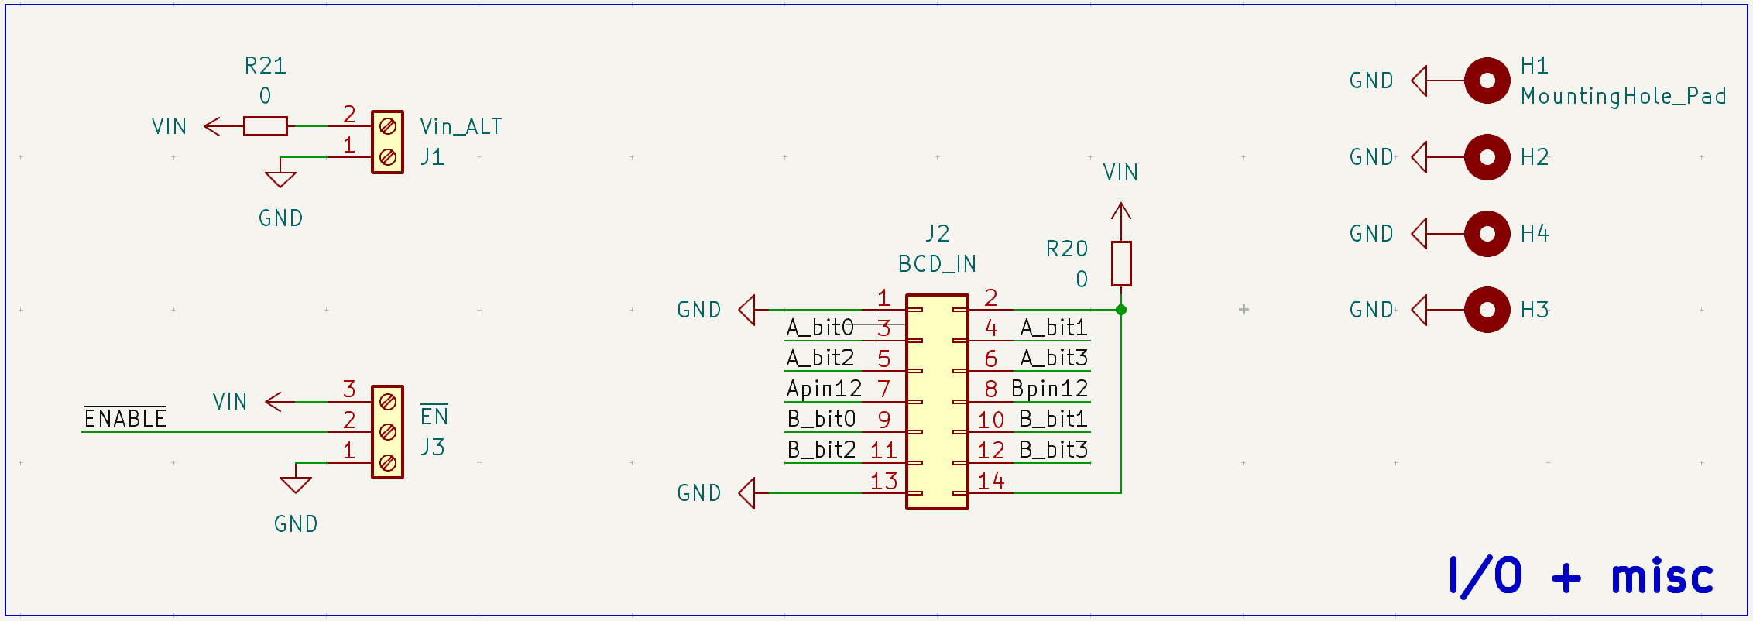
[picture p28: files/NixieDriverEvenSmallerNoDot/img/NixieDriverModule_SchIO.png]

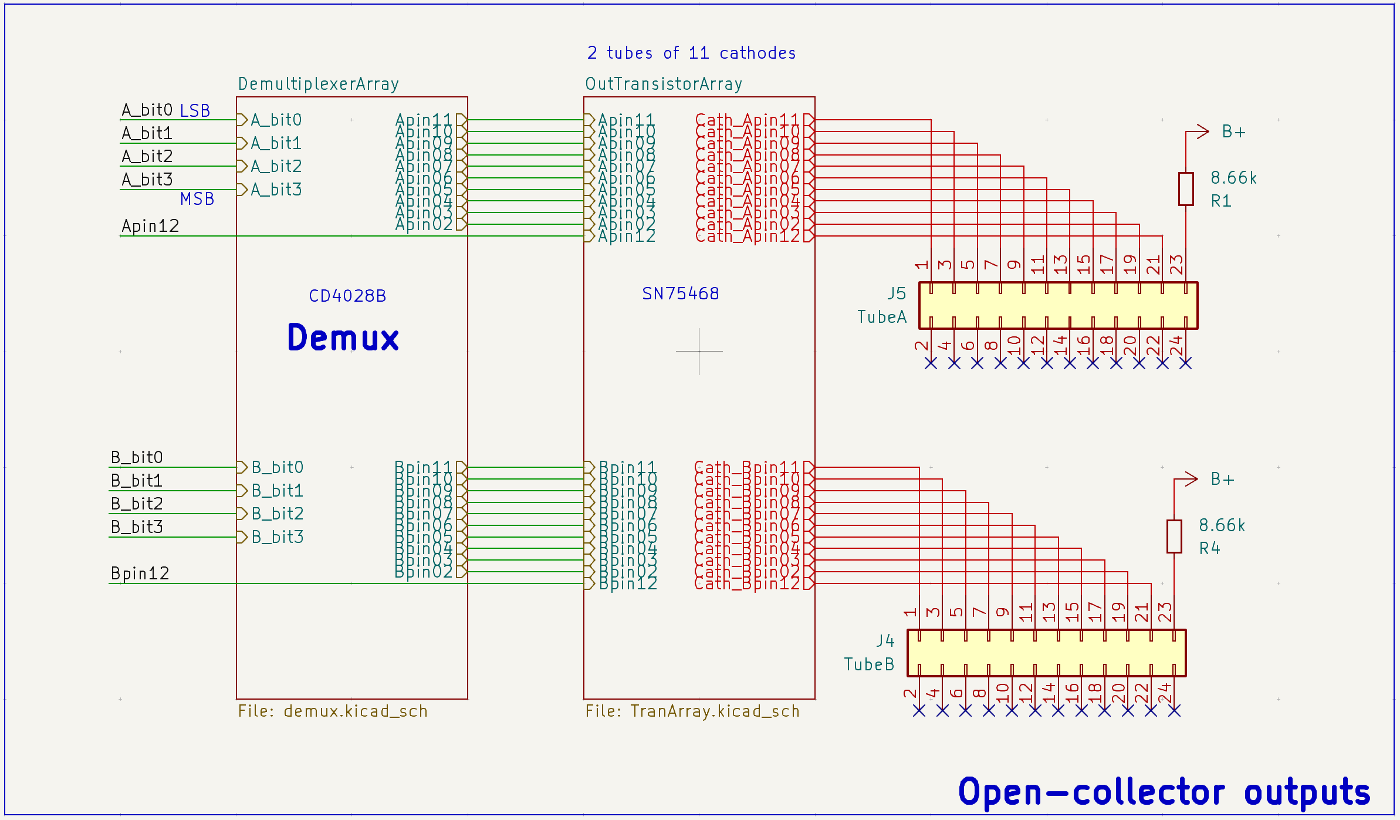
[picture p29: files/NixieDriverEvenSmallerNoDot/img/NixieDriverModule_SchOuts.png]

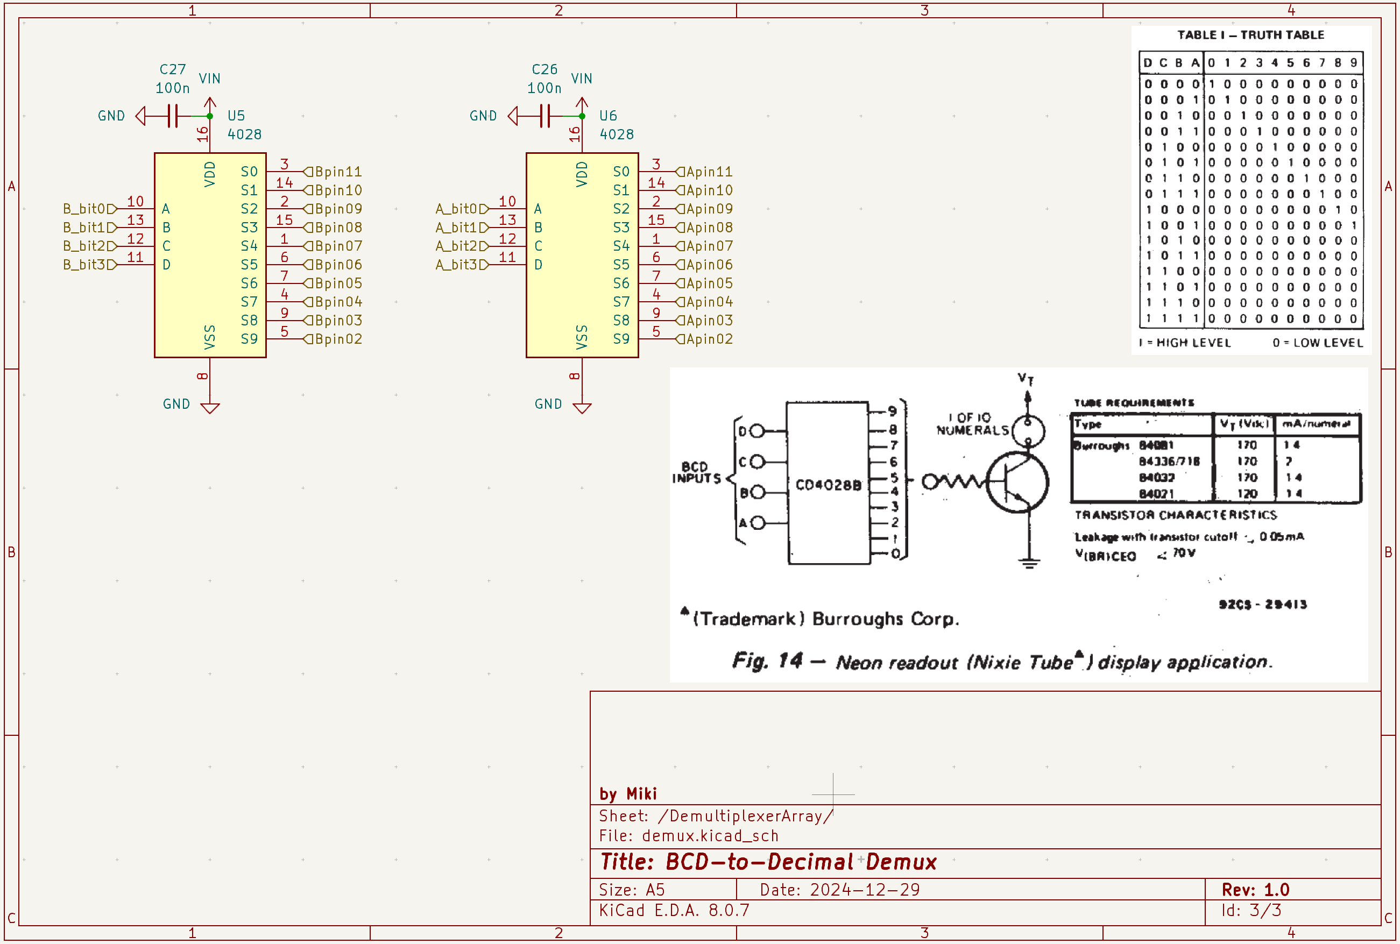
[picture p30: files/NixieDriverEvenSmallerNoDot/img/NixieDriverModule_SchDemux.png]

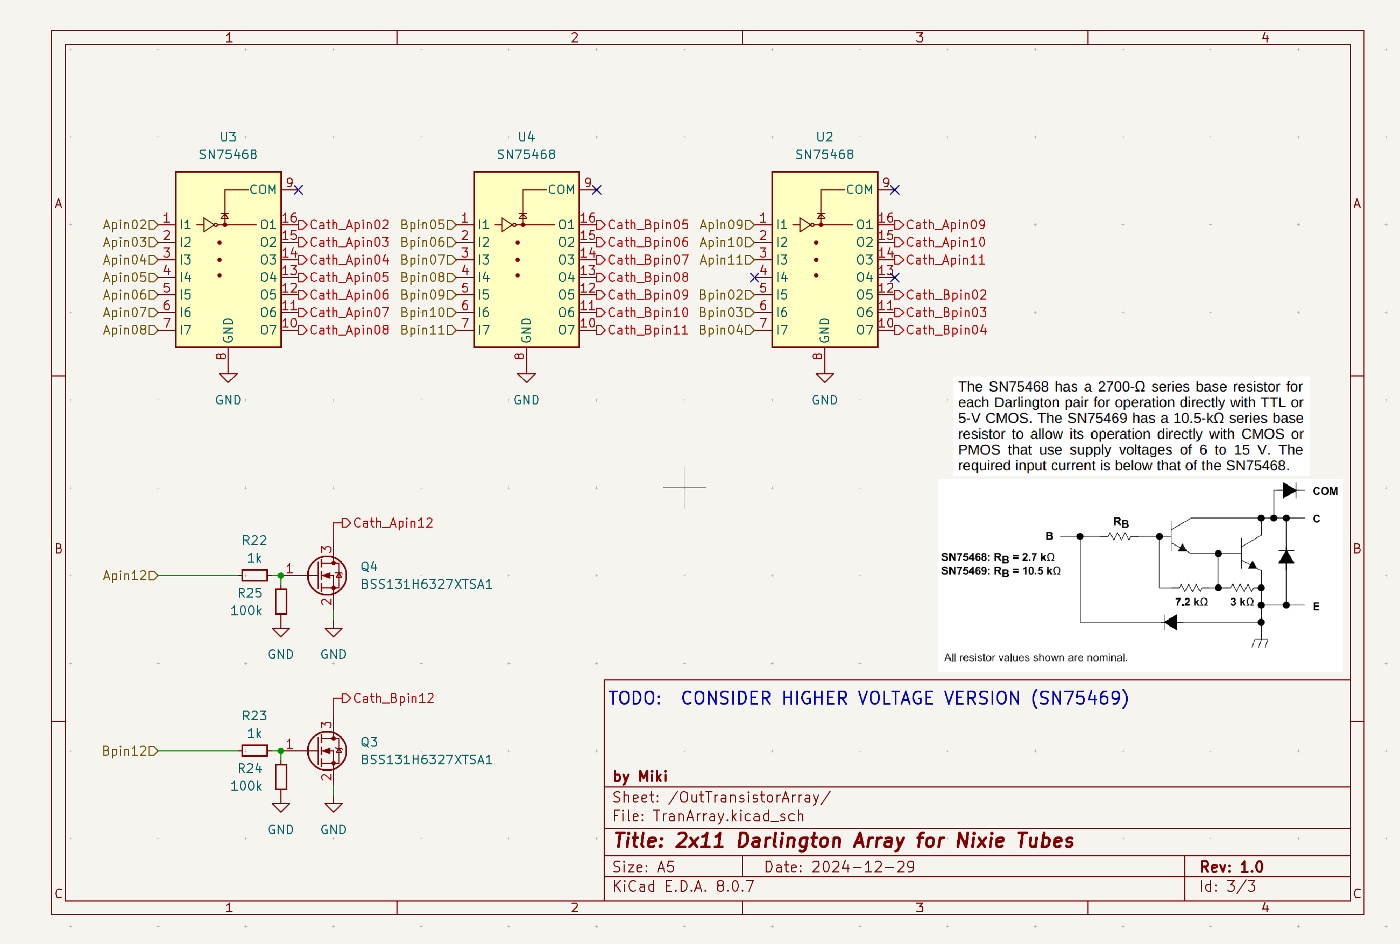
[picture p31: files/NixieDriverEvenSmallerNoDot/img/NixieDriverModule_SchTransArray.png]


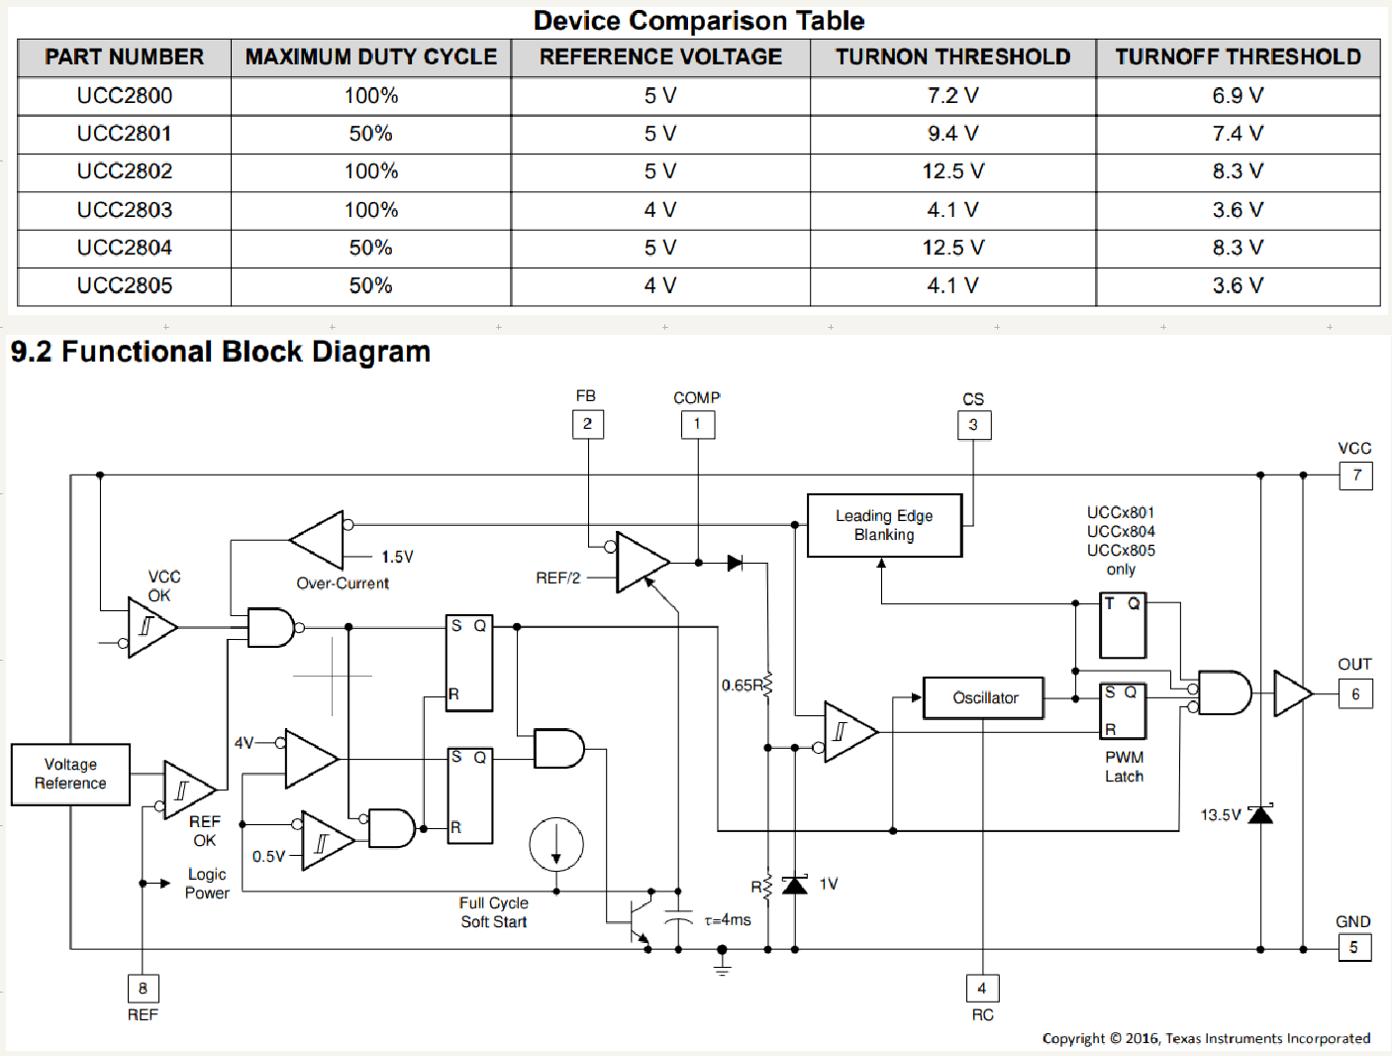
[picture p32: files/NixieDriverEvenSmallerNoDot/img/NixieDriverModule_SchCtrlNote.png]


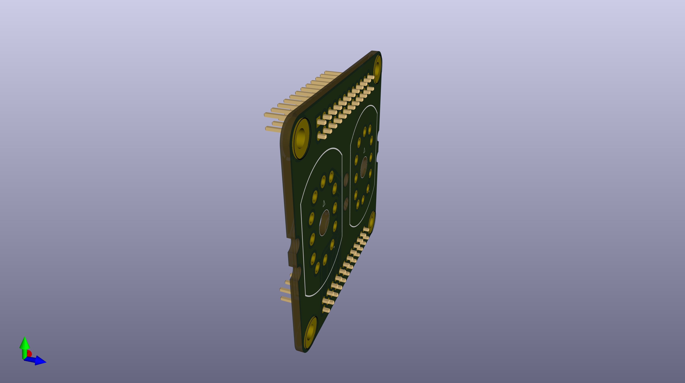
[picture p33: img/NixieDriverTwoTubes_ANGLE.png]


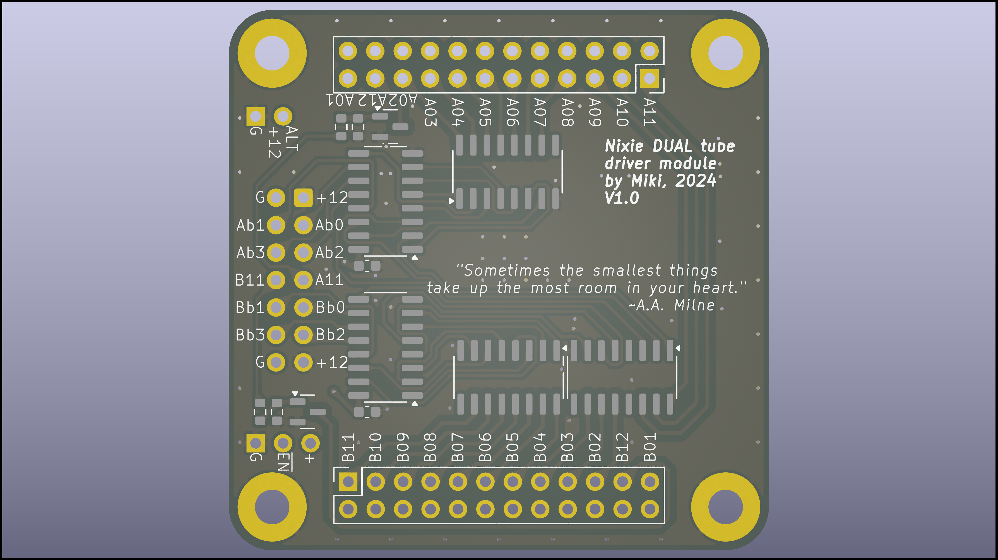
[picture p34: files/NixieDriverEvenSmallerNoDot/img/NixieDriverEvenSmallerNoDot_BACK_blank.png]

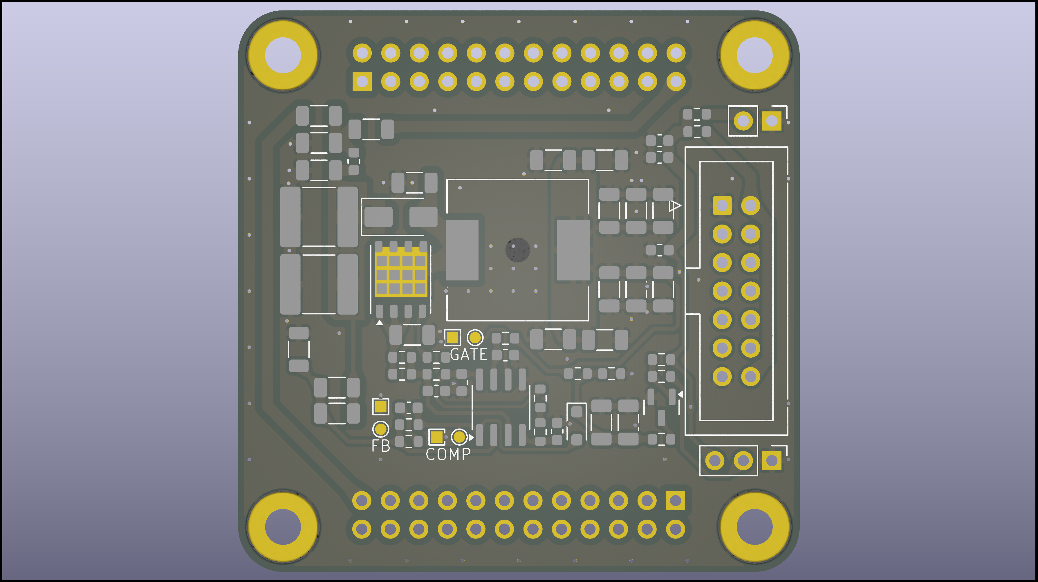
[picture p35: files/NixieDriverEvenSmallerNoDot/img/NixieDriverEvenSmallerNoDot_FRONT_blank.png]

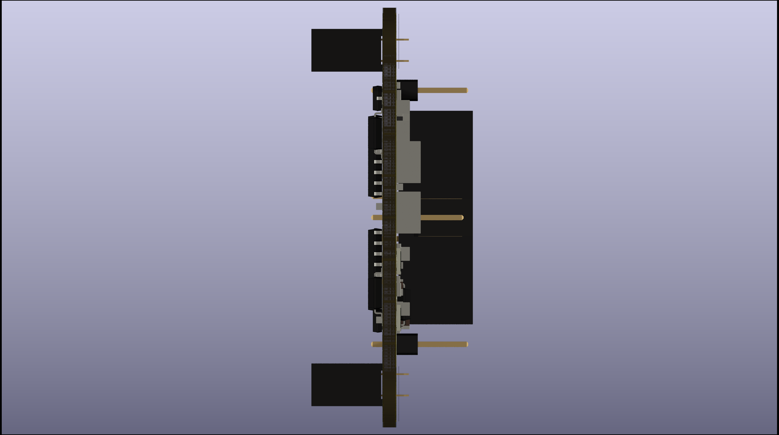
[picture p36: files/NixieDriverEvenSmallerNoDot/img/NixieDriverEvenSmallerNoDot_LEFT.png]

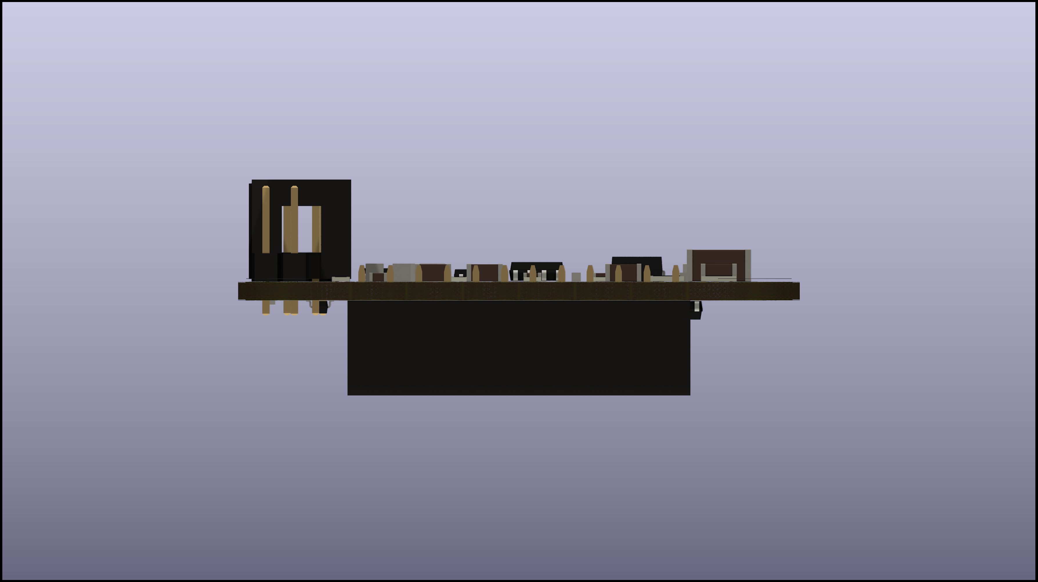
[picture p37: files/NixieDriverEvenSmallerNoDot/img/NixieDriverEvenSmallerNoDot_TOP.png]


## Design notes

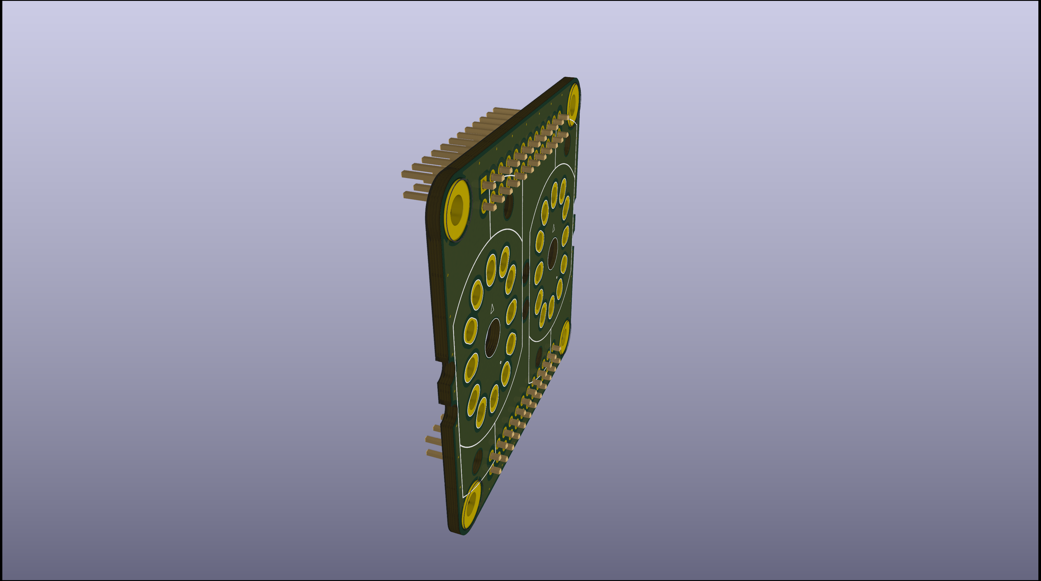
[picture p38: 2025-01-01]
files/NixieDriverTwoTubesSockets/img/NixieDriverTwoTubesSockets_ANGLE.png

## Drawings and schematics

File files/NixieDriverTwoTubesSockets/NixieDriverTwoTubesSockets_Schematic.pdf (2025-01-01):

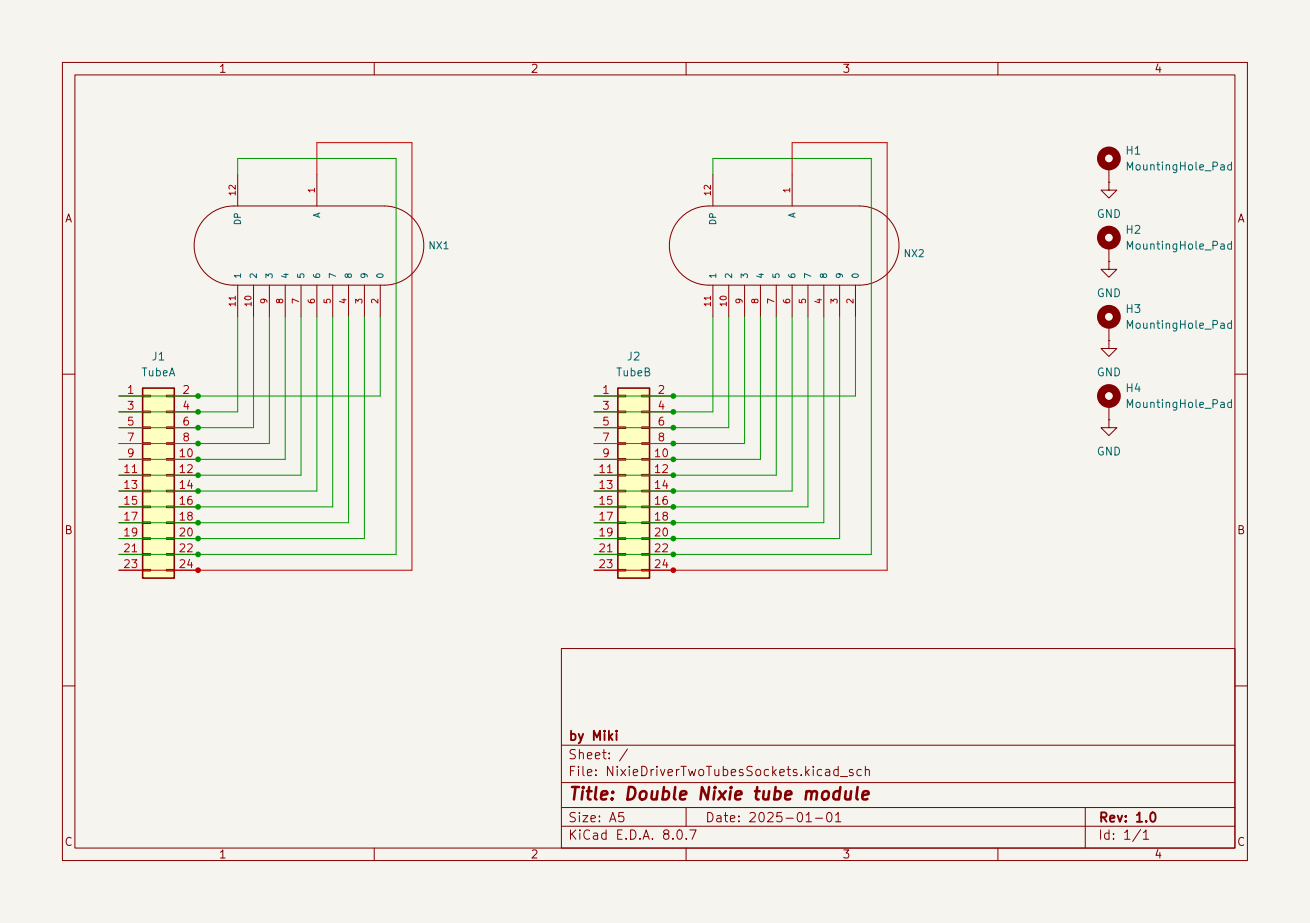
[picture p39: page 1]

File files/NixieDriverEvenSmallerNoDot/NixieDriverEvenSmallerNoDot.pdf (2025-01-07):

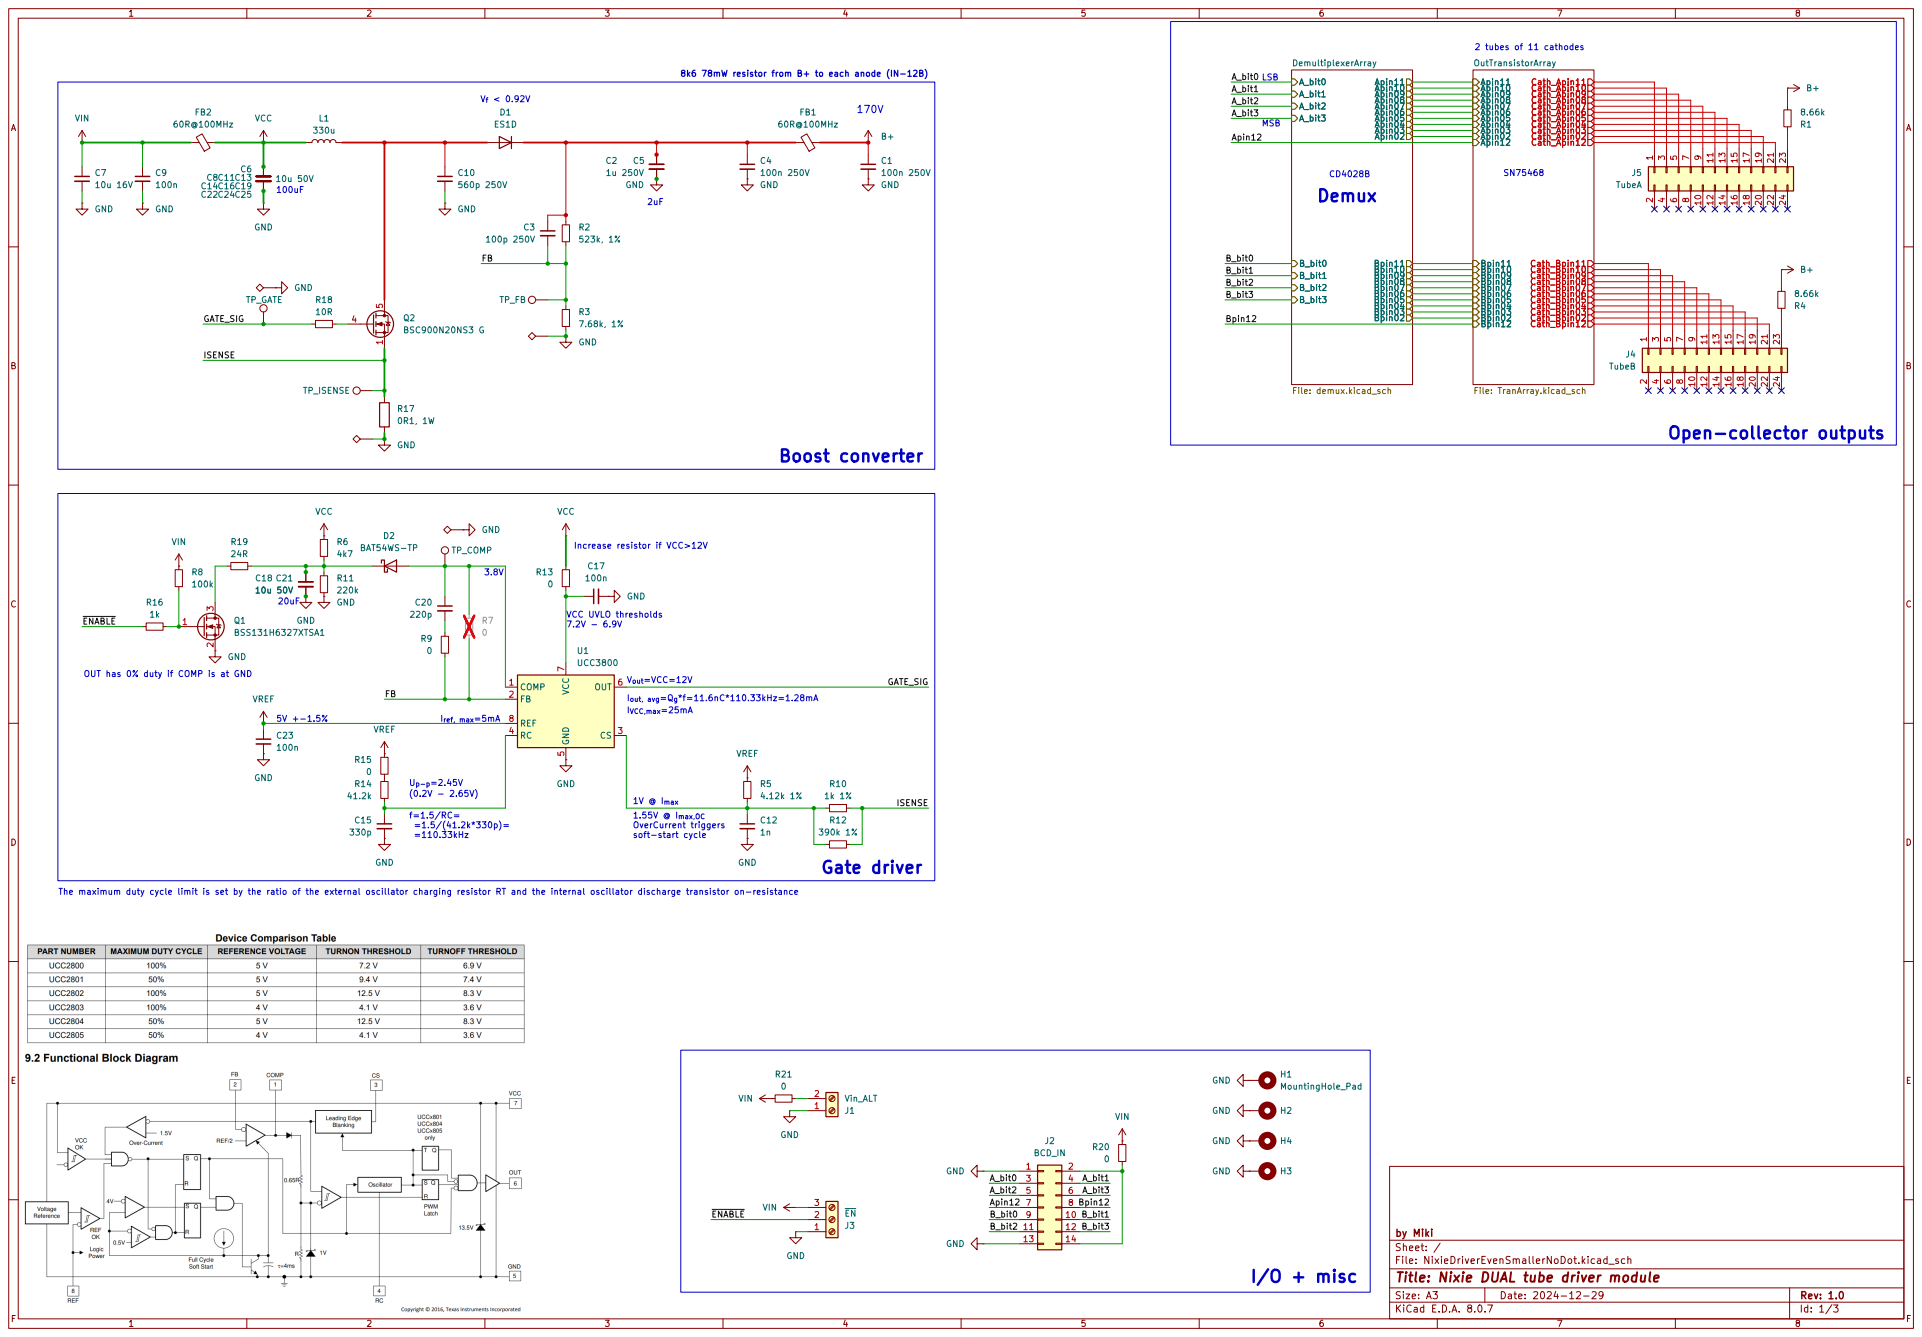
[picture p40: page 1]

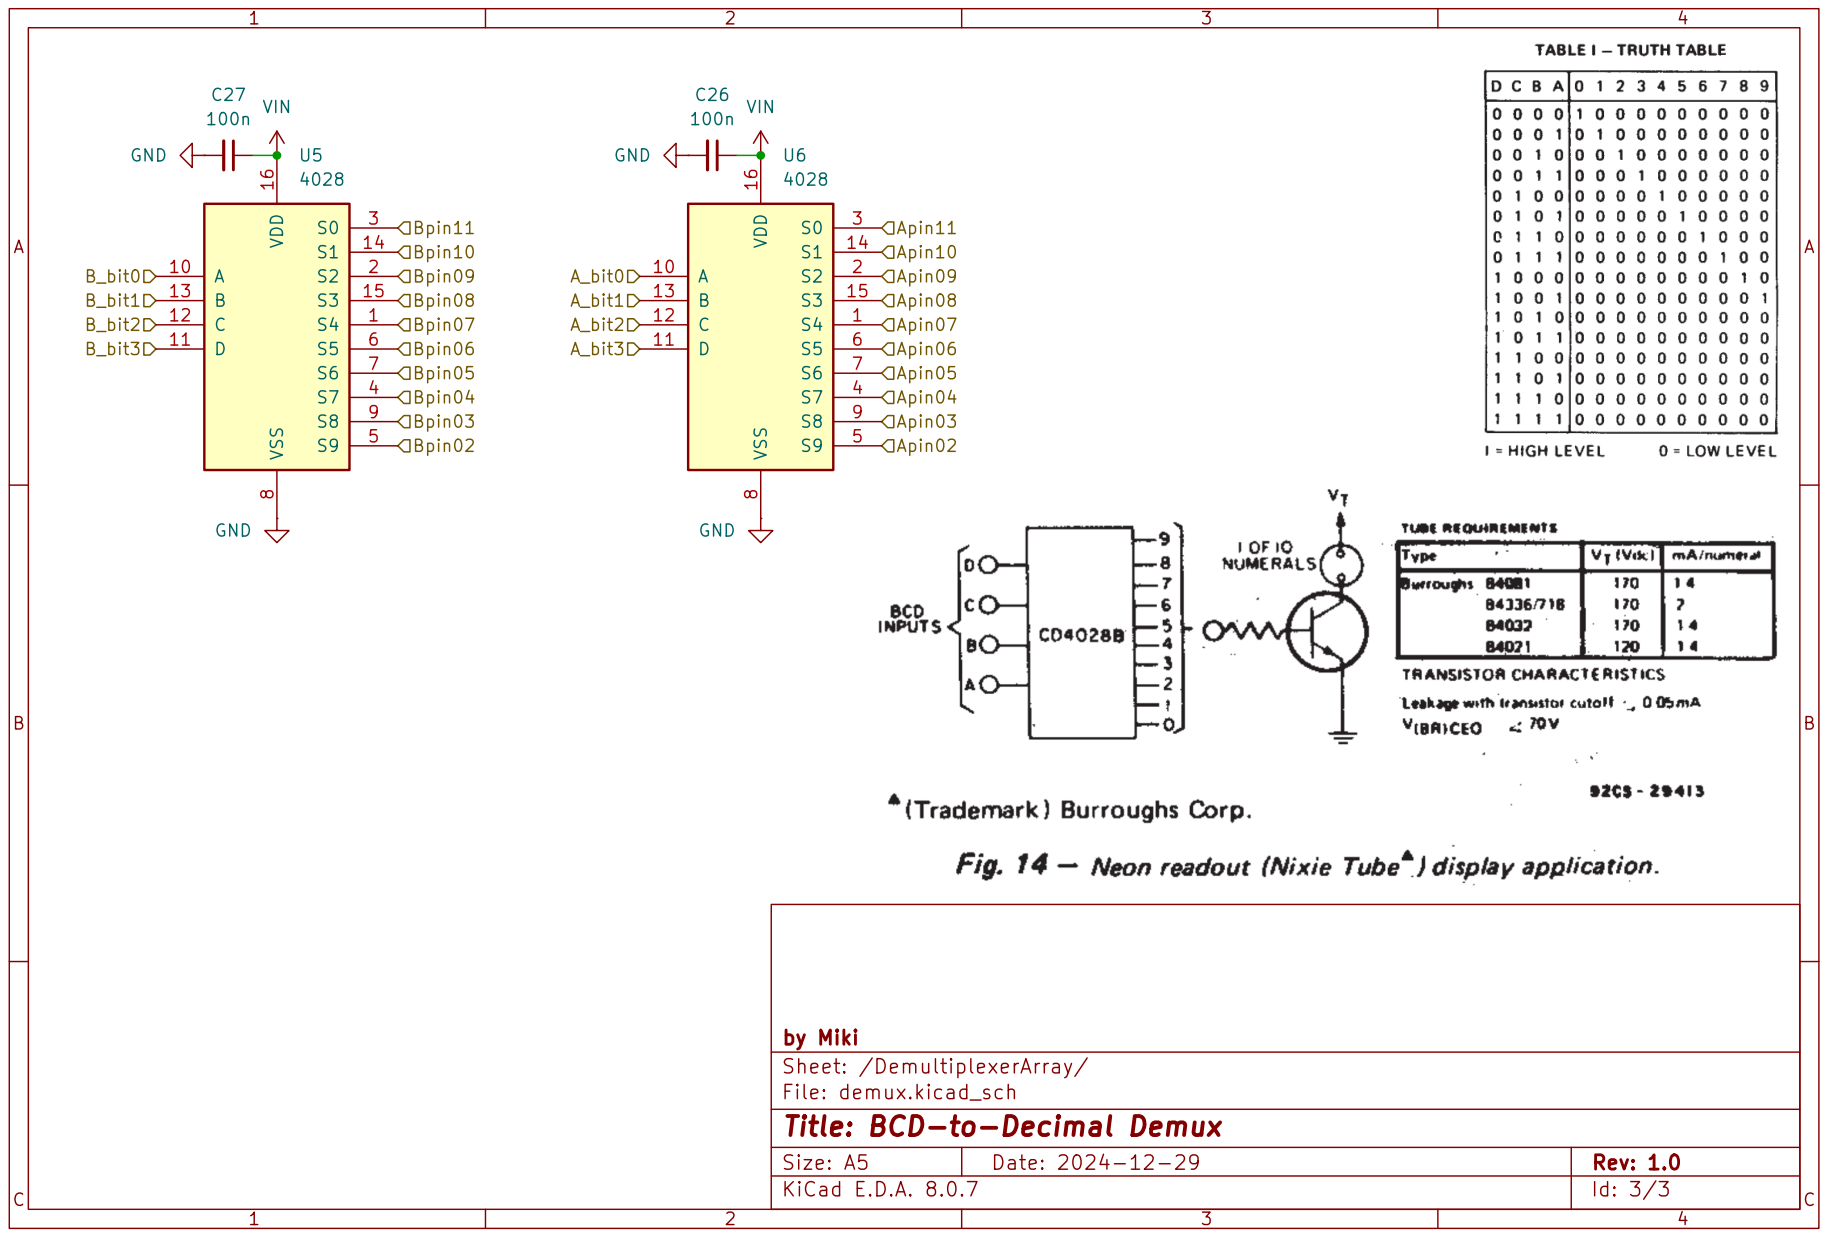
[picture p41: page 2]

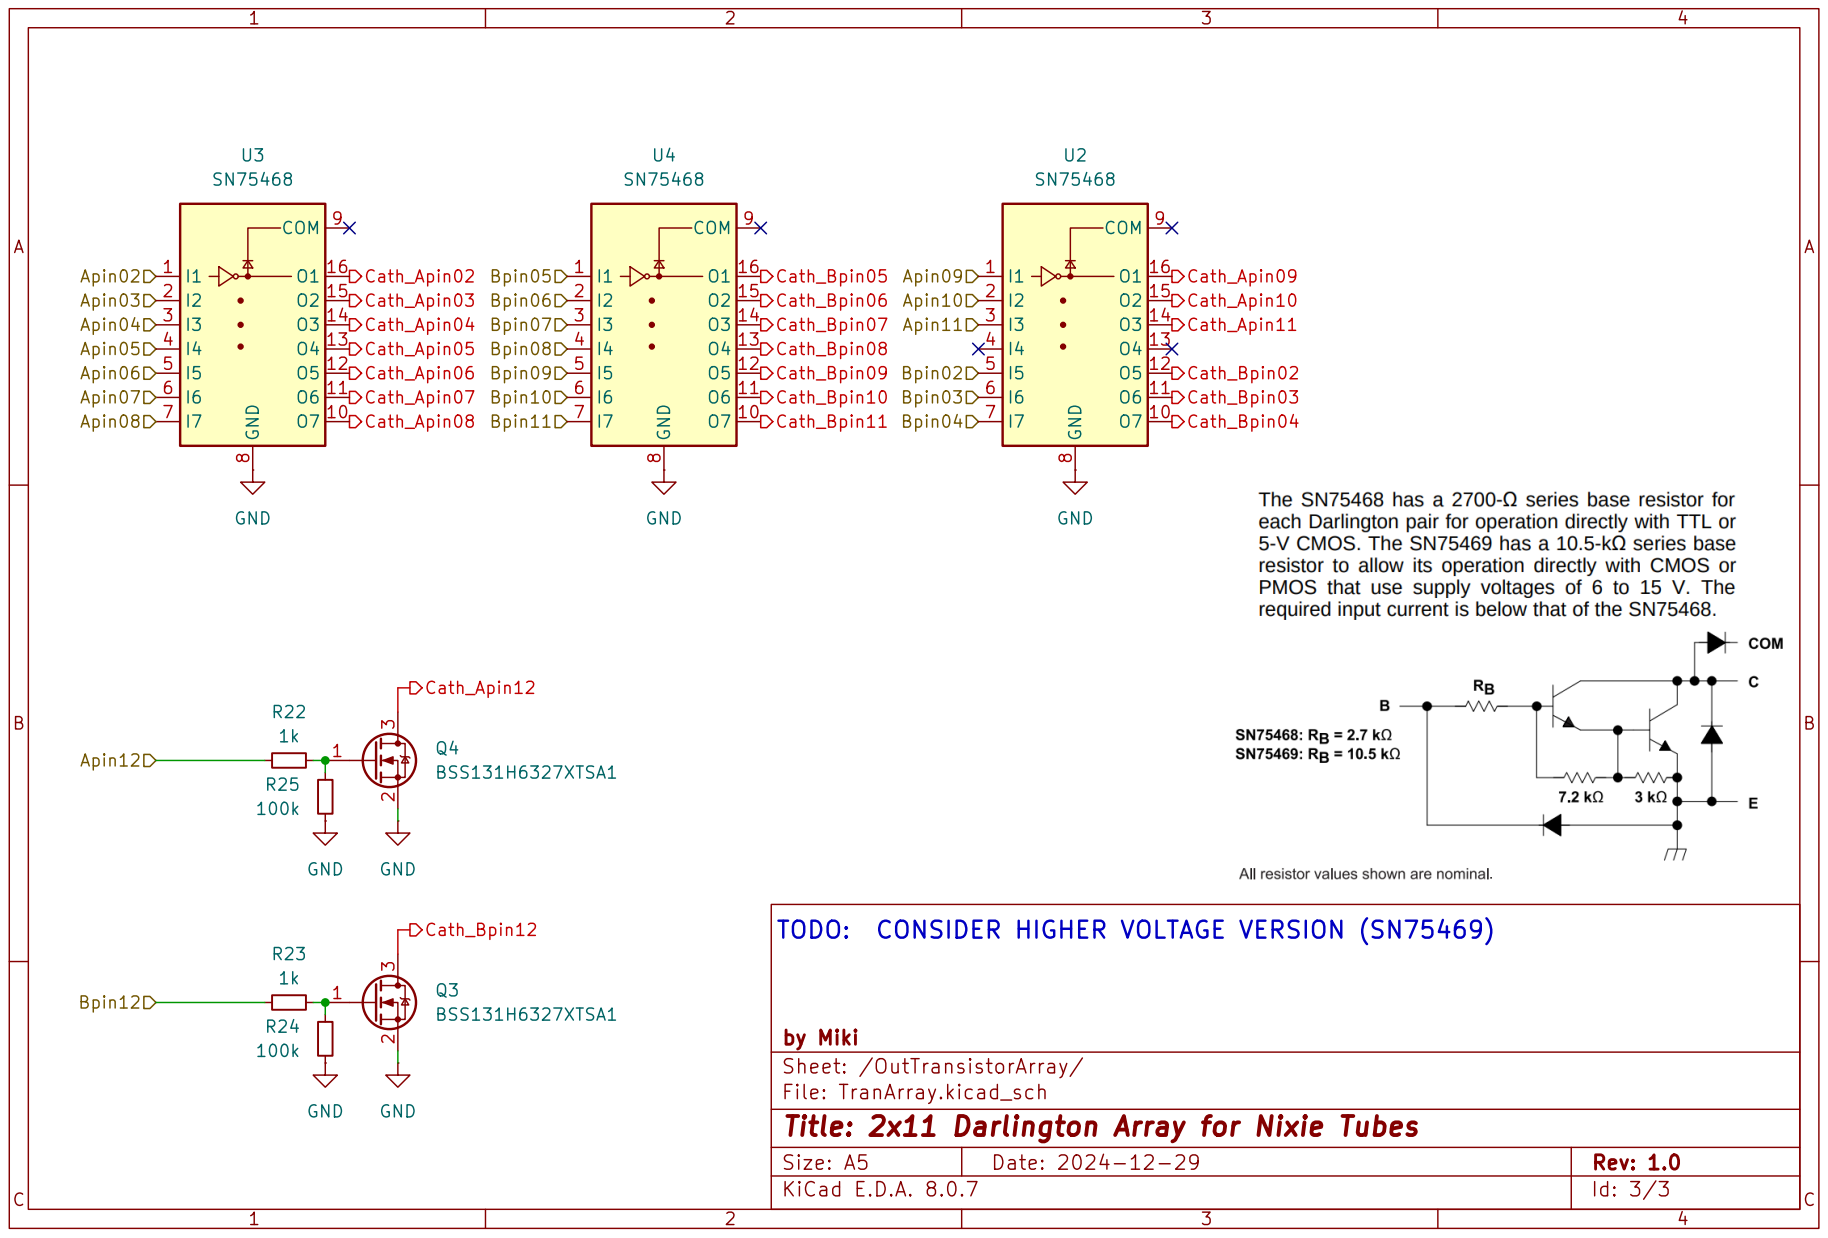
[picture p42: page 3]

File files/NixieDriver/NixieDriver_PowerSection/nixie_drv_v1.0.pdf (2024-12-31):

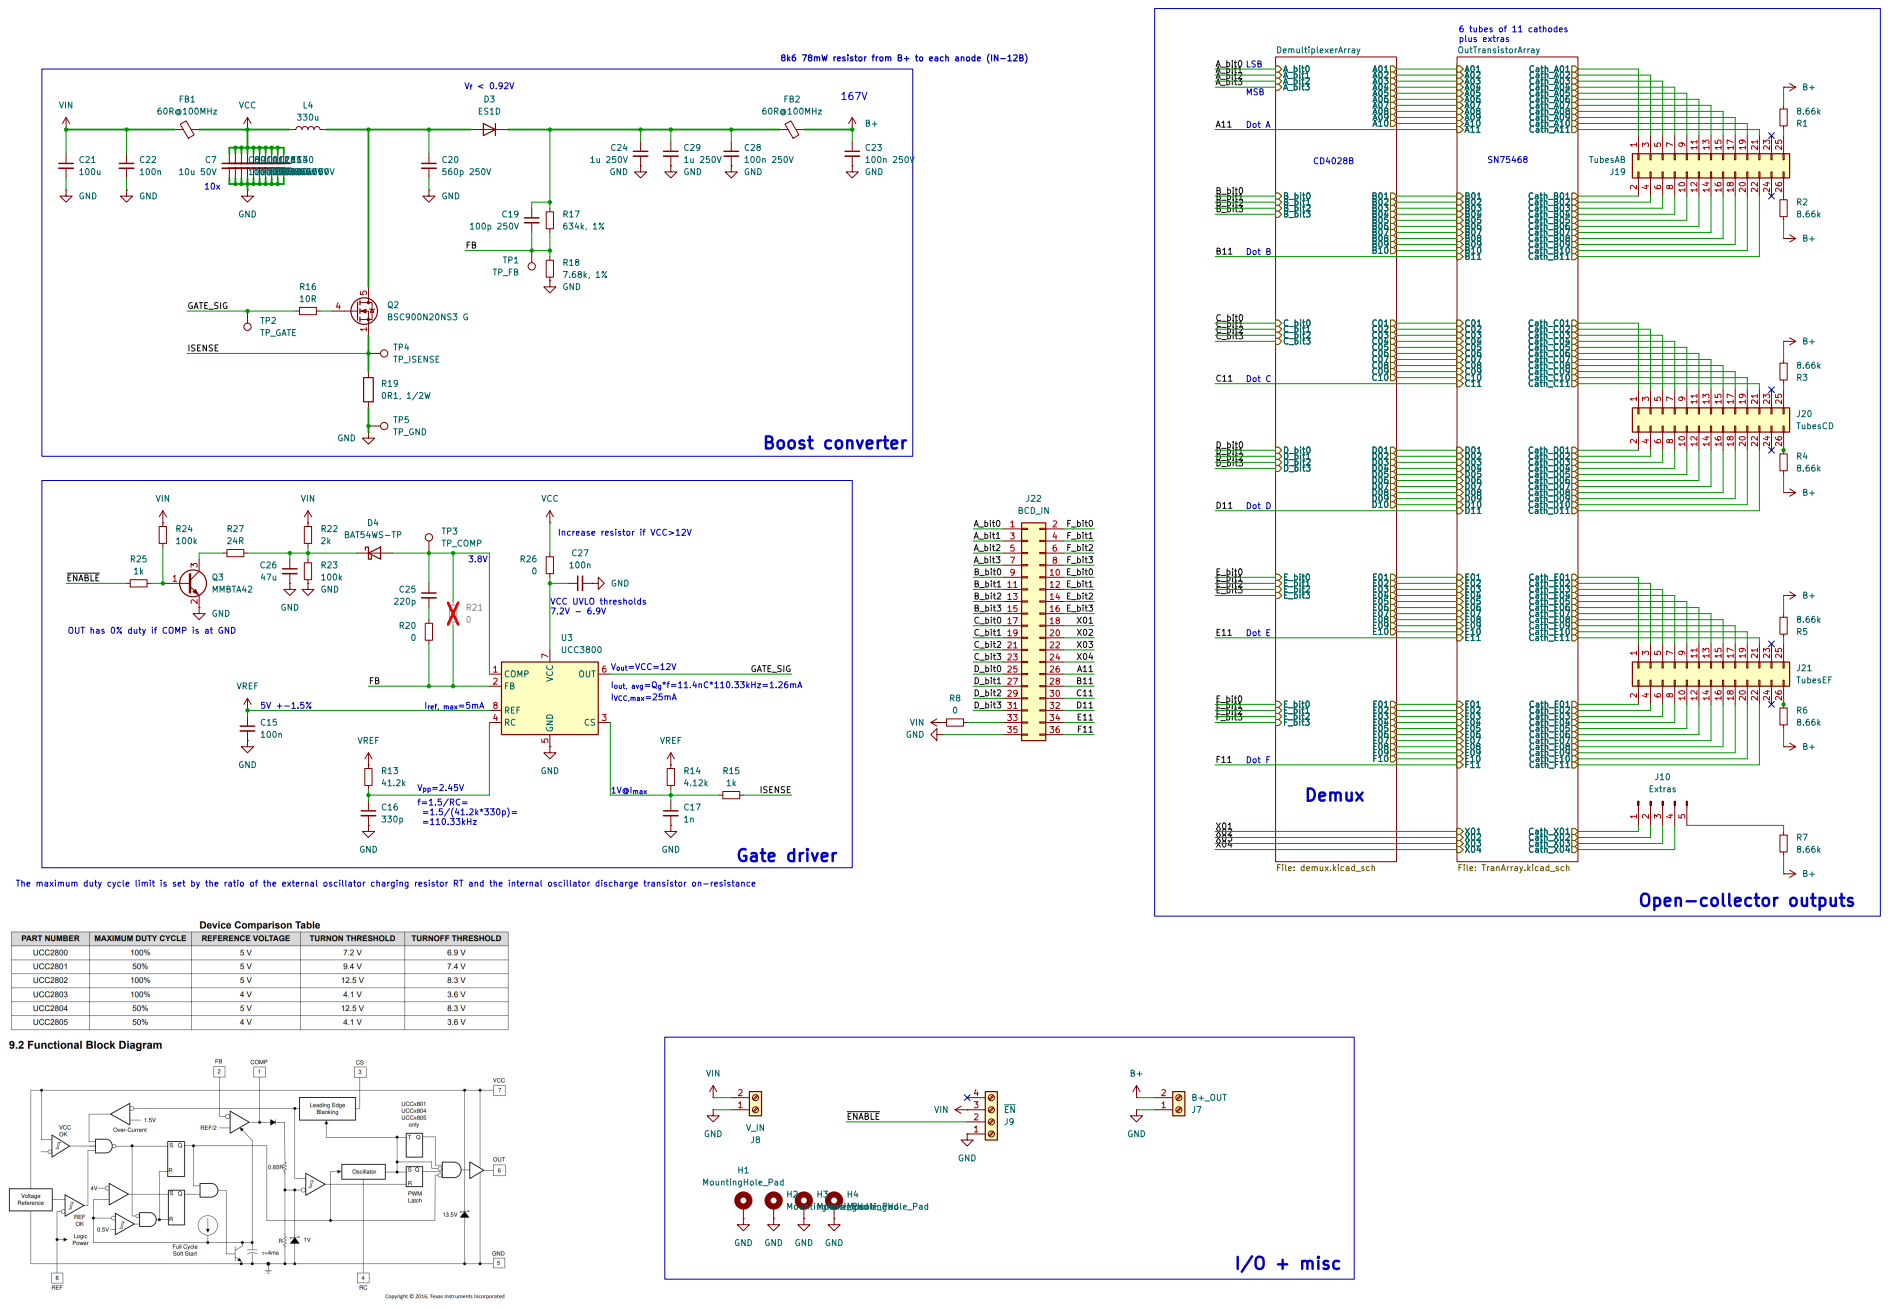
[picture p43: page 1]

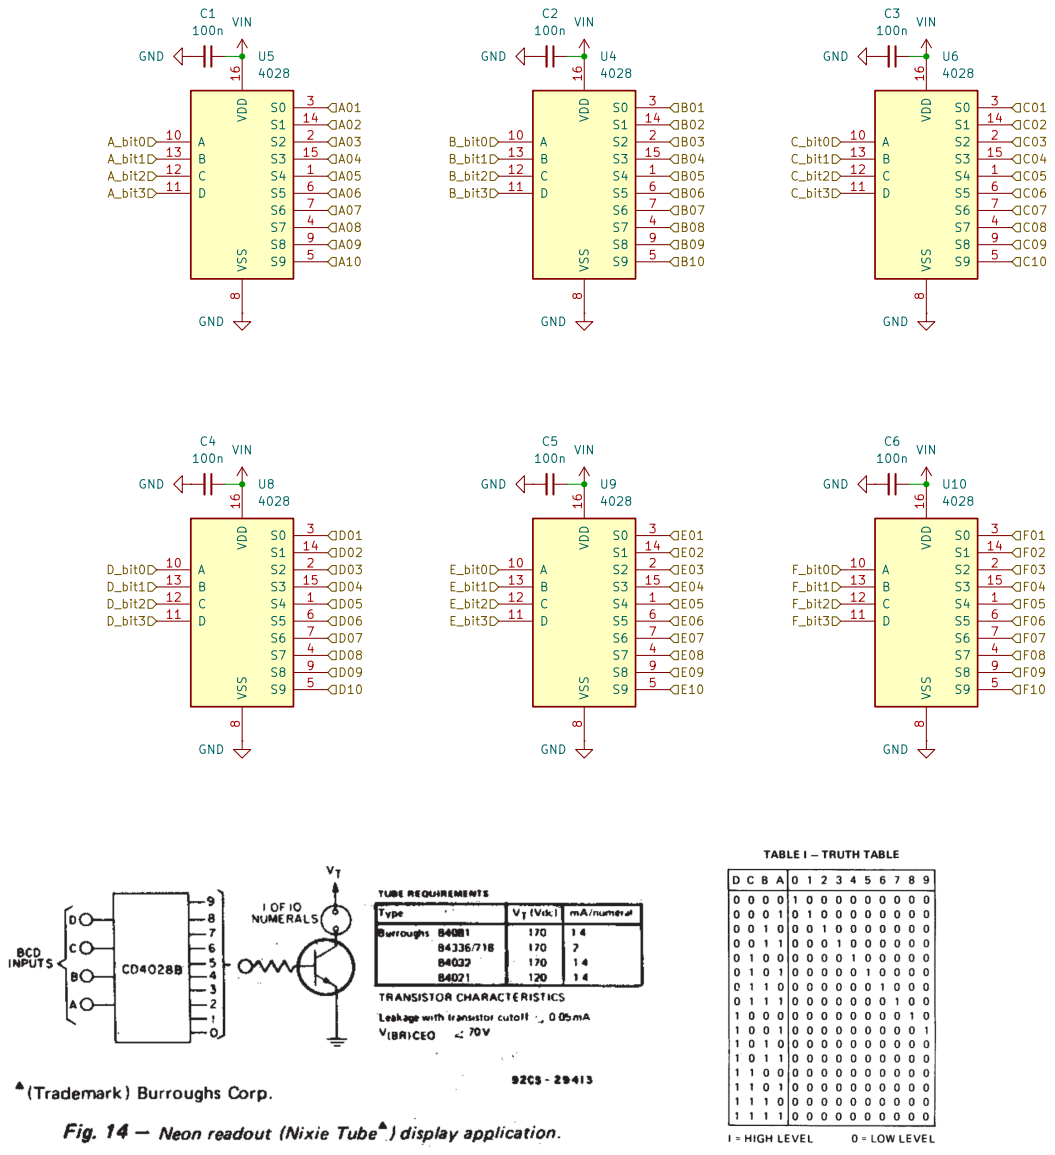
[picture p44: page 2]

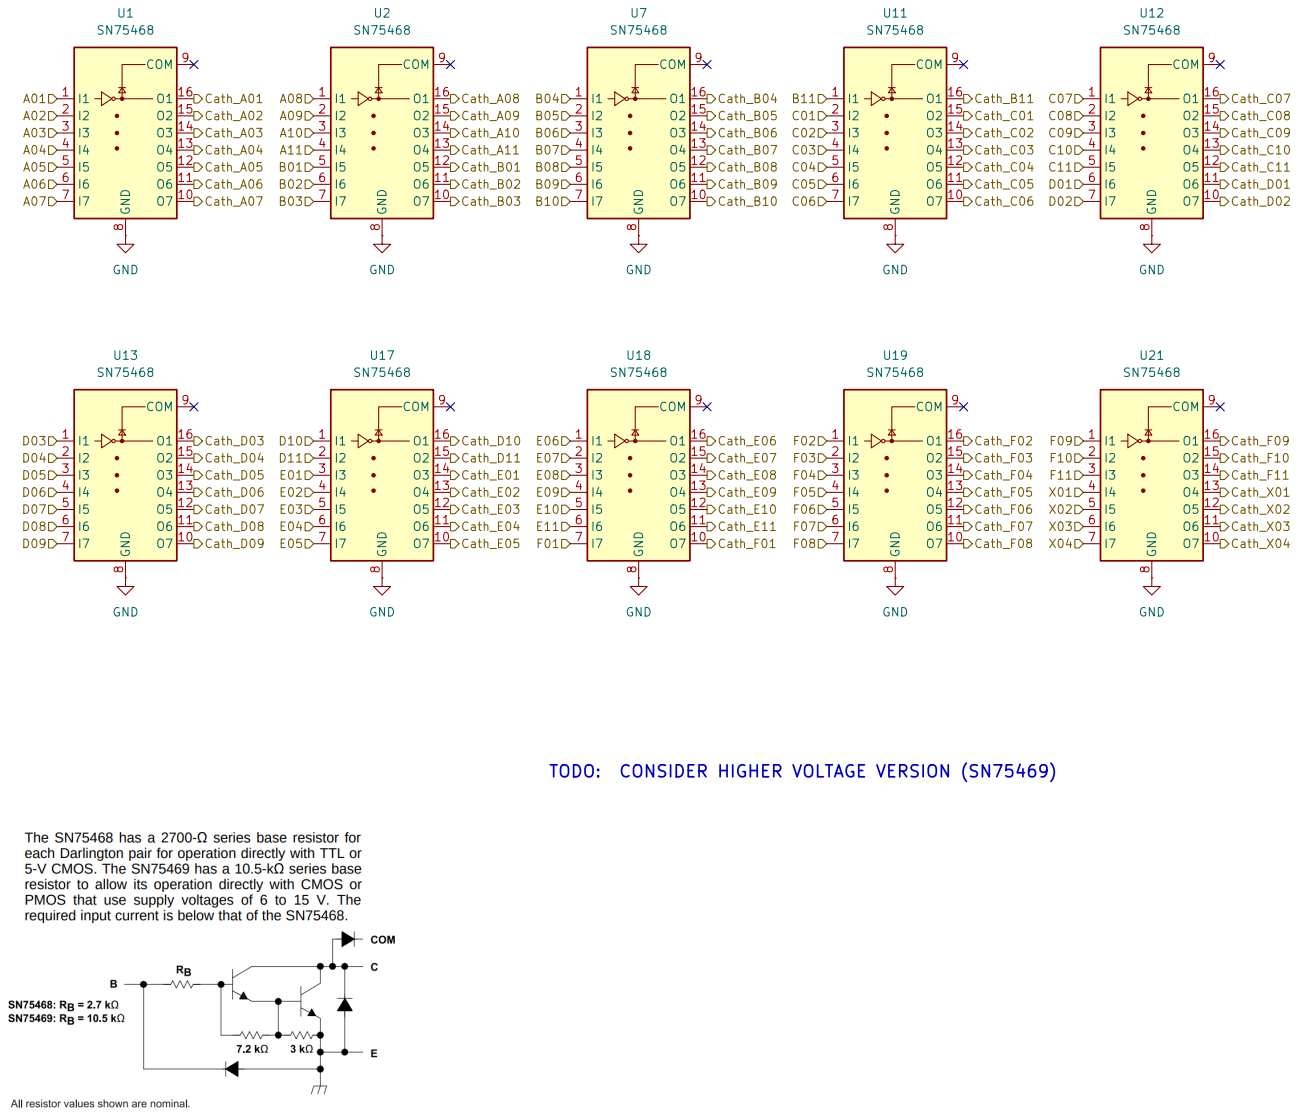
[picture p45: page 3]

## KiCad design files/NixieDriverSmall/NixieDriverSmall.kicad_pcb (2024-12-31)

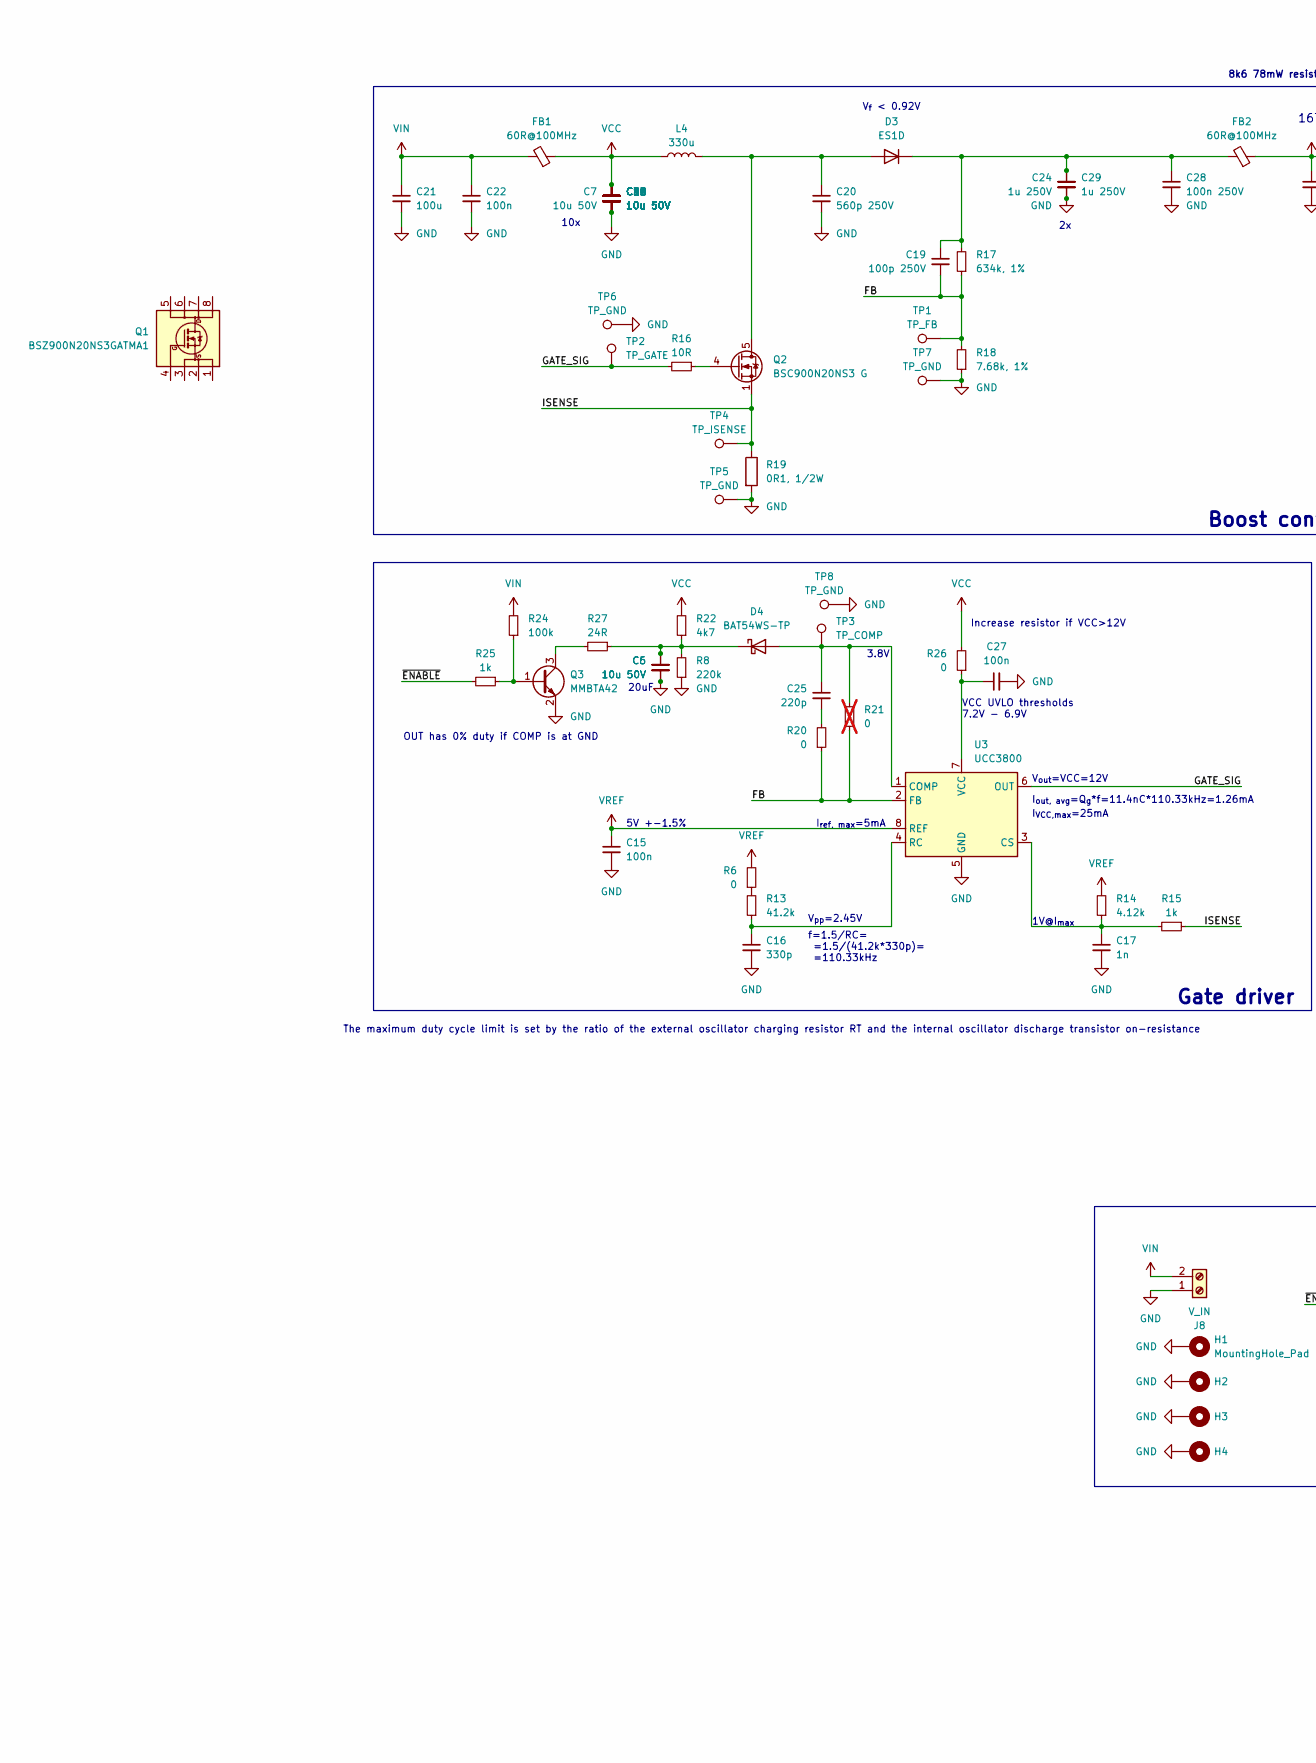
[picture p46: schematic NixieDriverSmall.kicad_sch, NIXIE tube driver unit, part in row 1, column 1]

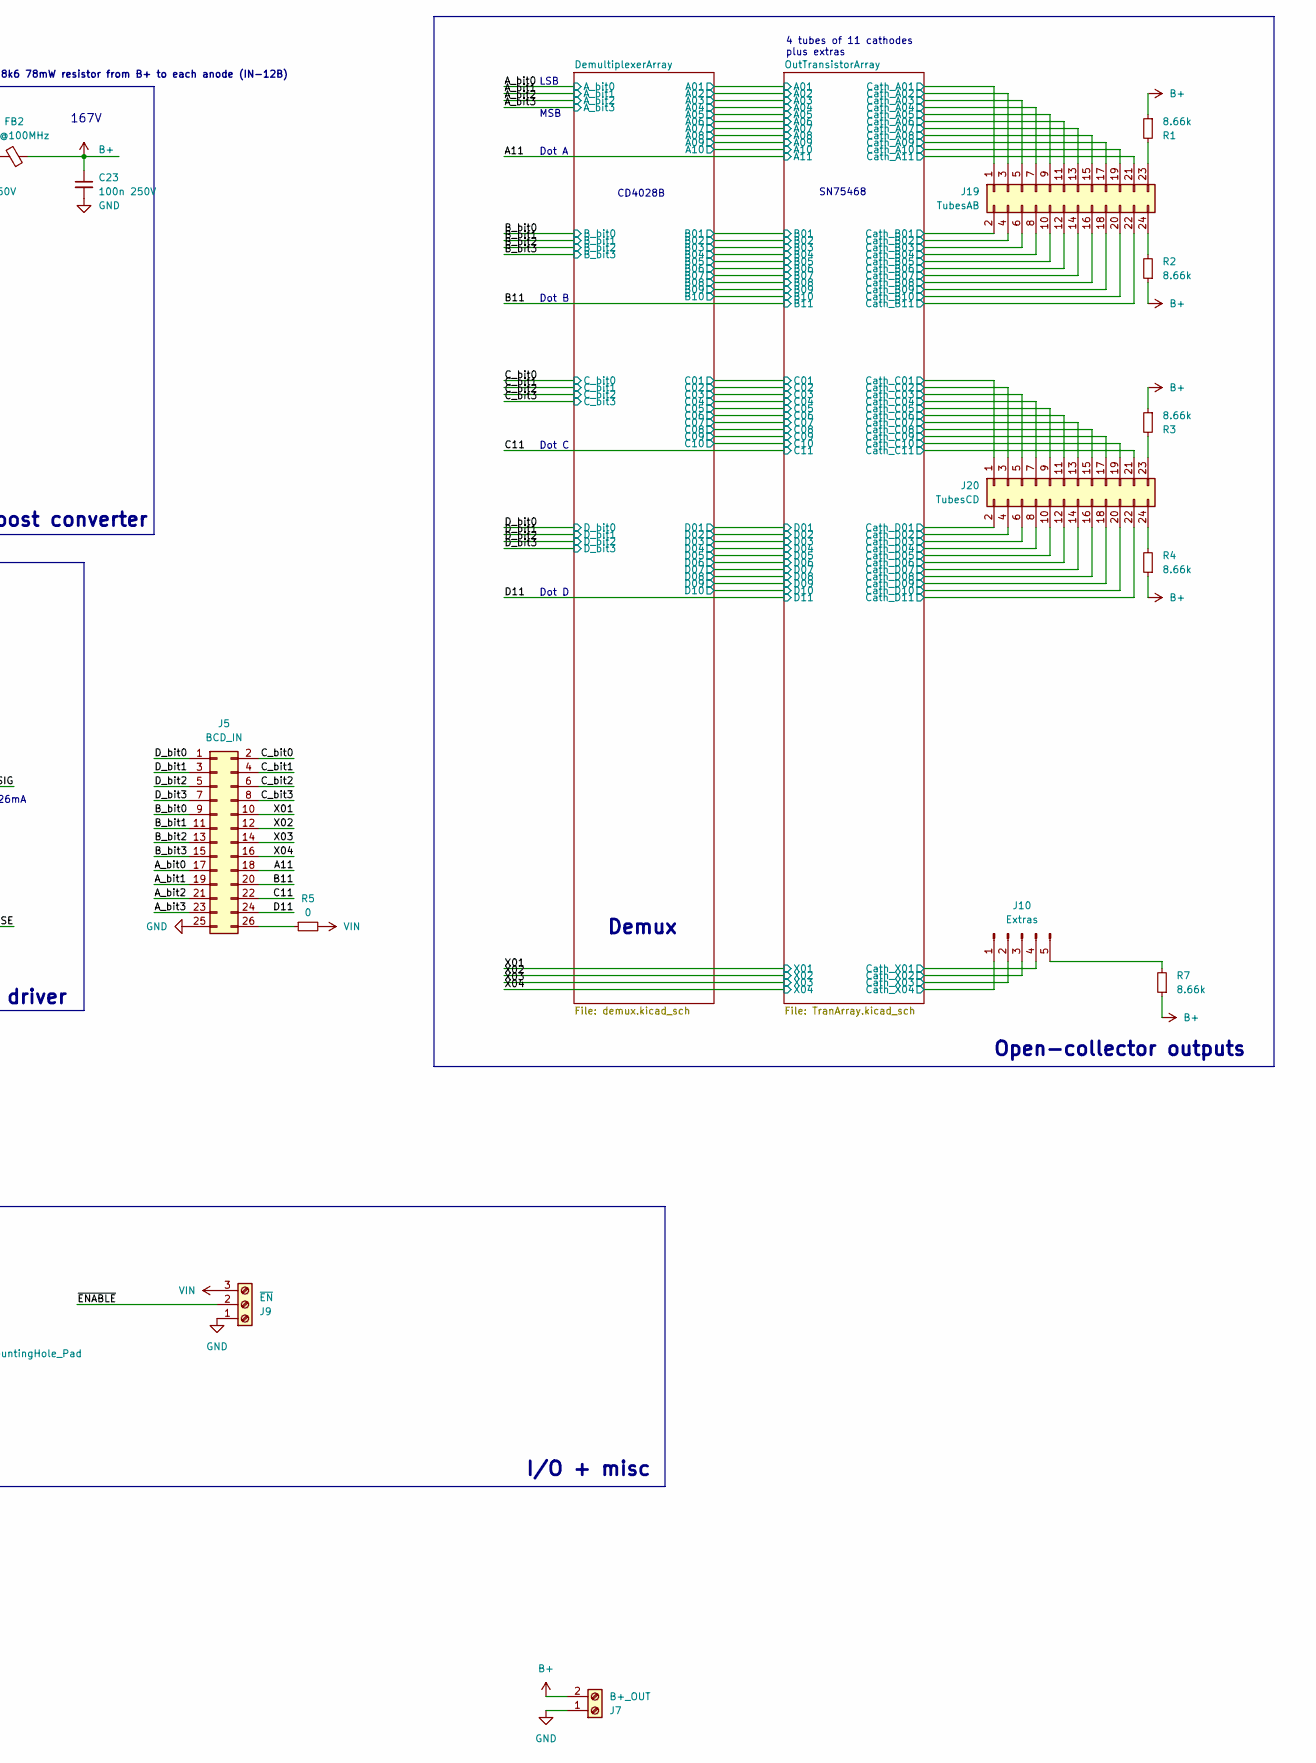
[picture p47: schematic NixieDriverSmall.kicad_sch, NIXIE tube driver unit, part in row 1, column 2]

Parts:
C5, C6, C7, C8, C9, C10, C11, C12, C13, C14, C18, C30: 10u 50V; C_1206_3216Metric
C15, C22, C27: 100n; C_0603_1608Metric
C16: 330p; C_0603_1608Metric
C17: 1n; C_0603_1608Metric
C19: 100p 250V; C_1206_3216Metric
C20: 560p 250V; C_1206_3216Metric
C21: 100u; C_0603_1608Metric
C23, C28: 100n 250V; C_1206_3216Metric
C24, C29: 1u 250V; C_2220_5750Metric
C25: 220p; C_0603_1608Metric
D3: ES1D; D_SMA
D4: BAT54WS-TP; D_SOD-323_HandSoldering; MPN BAT54WS-7-F
FB1, FB2: 60R@100MHz; L_0603_1608Metric
H1, H2, H3, H4: MountingHole_Pad; MountingHole_3.2mm_M3_Pad
J5: BCD_IN; PinHeader_2x13_P1.27mm_Vertical_SMD
J7: B+_OUT; PinHeader_1x02_P2.00mm_Vertical
J8: V_IN; PinHeader_1x02_P2.00mm_Vertical
J9: ~{EN}; PinHeader_1x03_P2.00mm_Vertical
J10: Extras; PinHeader_1x05_P2.00mm_Vertical
J19: TubesAB; PinHeader_2x12_P2.54mm_Vertical_SMD
J20: TubesCD; PinHeader_2x12_P2.54mm_Vertical_SMD
L4: 330u; L_12x12mm_H8mm
Q1: BSZ900N20NS3GATMA1; MPN FDS2672CT-ND
Q2: BSC900N20NS3 G; Infineon_PG-TDSON-8_6.15x5.15mm
Q3: MMBTA42; SOT-23
R1, R2, R3, R4, R7: 8.66k; R_0805_2012Metric_Pad1.20x1.40mm_HandSolder
R5, R6, R20, R26: 0; R_0603_1608Metric
R8: 220k; R_0603_1608Metric
R13: 41.2k; R_0603_1608Metric
R14: 4.12k; R_0603_1608Metric
R15, R25: 1k; R_0603_1608Metric
R16: 10R; R_0603_1608Metric
R17: 634k, 1%; R_1206_3216Metric
R18: 7.68k, 1%; R_1206_3216Metric
R19: 0R1, 1/2W; R_1206_3216Metric
R21: 0; R_0603_1608Metric; not fitted
R22: 4k7; R_0603_1608Metric
R24: 100k; R_0603_1608Metric
R27: 24R; R_0603_1608Metric
TP1: TP_FB; TestPoint_Pad_D1.0mm
TP2: TP_GATE; TestPoint_Pad_D1.0mm
TP3: TP_COMP; TestPoint_Pad_D1.0mm
TP4: TP_ISENSE; TestPoint_Pad_D1.0mm
TP5, TP6, TP7, TP8: TP_GND; TestPoint_Pad_1.0x1.0mm
U3: UCC3800; SOIC-8_3.9x4.9mm_P1.27mm

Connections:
/A11: J5.18; also elsewhere on the board
/A_bit0: J5.17; also elsewhere on the board
/A_bit1: J5.19; also elsewhere on the board
/A_bit2: J5.21; also elsewhere on the board
/A_bit3: J5.23; also elsewhere on the board
/B11: J5.20; also elsewhere on the board
/B_bit0: J5.9; also elsewhere on the board
/B_bit1: J5.11; also elsewhere on the board
/B_bit2: J5.13; also elsewhere on the board
/B_bit3: J5.15; also elsewhere on the board
/C11: J5.22; also elsewhere on the board
/C_bit0: J5.2; also elsewhere on the board
/C_bit1: J5.4; also elsewhere on the board
/C_bit2: J5.6; also elsewhere on the board
/C_bit3: J5.8; also elsewhere on the board
/D11: J5.24; also elsewhere on the board
/D_bit0: J5.1; also elsewhere on the board
/D_bit1: J5.3; also elsewhere on the board
/D_bit2: J5.5; also elsewhere on the board
/D_bit3: J5.7; also elsewhere on the board
/FB: C19.2, R17.1, R18.2, R20.1, R21.1, TP1.1, U3.2 (FB)
/GATE_SIG: R16.2, TP2.1, U3.6 (OUT)
/ISENSE: Q2.1 (S), Q2.2 (S), Q2.3 (S), R15.1, R19.1, TP4.1
/OutTransistorArray/Cath_A01: J19.1; also elsewhere on the board
/OutTransistorArray/Cath_A02: J19.3; also elsewhere on the board
/OutTransistorArray/Cath_A03: J19.5; also elsewhere on the board
/OutTransistorArray/Cath_A04: J19.7; also elsewhere on the board
/OutTransistorArray/Cath_A05: J19.9; also elsewhere on the board
/OutTransistorArray/Cath_A06: J19.11; also elsewhere on the board
/OutTransistorArray/Cath_A07: J19.13; also elsewhere on the board
/OutTransistorArray/Cath_A08: J19.15; also elsewhere on the board
/OutTransistorArray/Cath_A09: J19.17; also elsewhere on the board
/OutTransistorArray/Cath_A10: J19.19; also elsewhere on the board
/OutTransistorArray/Cath_A11: J19.21; also elsewhere on the board
/OutTransistorArray/Cath_B01: J19.2; also elsewhere on the board
/OutTransistorArray/Cath_B02: J19.4; also elsewhere on the board
/OutTransistorArray/Cath_B03: J19.6; also elsewhere on the board
/OutTransistorArray/Cath_B04: J19.8; also elsewhere on the board
/OutTransistorArray/Cath_B05: J19.10; also elsewhere on the board
/OutTransistorArray/Cath_B06: J19.12; also elsewhere on the board
/OutTransistorArray/Cath_B07: J19.14; also elsewhere on the board
/OutTransistorArray/Cath_B08: J19.16; also elsewhere on the board
/OutTransistorArray/Cath_B09: J19.18; also elsewhere on the board
/OutTransistorArray/Cath_B10: J19.20; also elsewhere on the board
/OutTransistorArray/Cath_B11: J19.22; also elsewhere on the board
/OutTransistorArray/Cath_C01: J20.1; also elsewhere on the board
/OutTransistorArray/Cath_C02: J20.3; also elsewhere on the board
/OutTransistorArray/Cath_C03: J20.5; also elsewhere on the board
/OutTransistorArray/Cath_C04: J20.7; also elsewhere on the board
/OutTransistorArray/Cath_C05: J20.9; also elsewhere on the board
/OutTransistorArray/Cath_C06: J20.11; also elsewhere on the board
/OutTransistorArray/Cath_C07: J20.13; also elsewhere on the board
/OutTransistorArray/Cath_C08: J20.15; also elsewhere on the board
/OutTransistorArray/Cath_C09: J20.17; also elsewhere on the board
/OutTransistorArray/Cath_C10: J20.19; also elsewhere on the board
/OutTransistorArray/Cath_C11: J20.21; also elsewhere on the board
/OutTransistorArray/Cath_D01: J20.2; also elsewhere on the board
/OutTransistorArray/Cath_D02: J20.4; also elsewhere on the board
/OutTransistorArray/Cath_D03: J20.6; also elsewhere on the board
/OutTransistorArray/Cath_D04: J20.8; also elsewhere on the board
/OutTransistorArray/Cath_D05: J20.10; also elsewhere on the board
/OutTransistorArray/Cath_D06: J20.12; also elsewhere on the board
/OutTransistorArray/Cath_D07: J20.14; also elsewhere on the board
/OutTransistorArray/Cath_D08: J20.16; also elsewhere on the board
/OutTransistorArray/Cath_D09: J20.18; also elsewhere on the board
/OutTransistorArray/Cath_D10: J20.20; also elsewhere on the board
/OutTransistorArray/Cath_D11: J20.22; also elsewhere on the board
/OutTransistorArray/Cath_X01: J10.4; also elsewhere on the board
/OutTransistorArray/Cath_X02: J10.3; also elsewhere on the board
/OutTransistorArray/Cath_X03: J10.2; also elsewhere on the board
/OutTransistorArray/Cath_X04: J10.1; also elsewhere on the board
/X01: J5.10; also elsewhere on the board
/X02: J5.12; also elsewhere on the board
/X03: J5.14; also elsewhere on the board
/X04: J5.16; also elsewhere on the board
/~ENABLE: J9.2, R25.2
B+: C23.1, FB2.1, J7.2, R1.1, R2.1, R3.1, R4.1, R7.1
GND: C5.2, C6.2, C7.2, C8.2, C9.2, C10.2, C11.2, C12.2, C13.2, C14.2, C15.2, C16.2, C17.2, C18.2, C20.2, C21.2, C22.2, C23.2, C24.2, C27.2, C28.2, C29.2, C30.2, H1.1, H2.1, H3.1, H4.1, J5.25, J7.1, J8.1, J9.1, Q3.2 (E), R8.1, R18.1, R19.2, TP5.1, TP6.1, TP7.1, TP8.1, U3.5 (GND); also elsewhere on the board
unnamed: C25.2, R20.2
unnamed: C20.1, D3.2 (A), L4.2, Q2.5 (D)
unnamed: C19.1, C24.1, C28.1, C29.1, D3.1 (K), FB2.2, R17.2
unnamed: C25.1, D4.2 (A), R21.2, TP3.1, U3.1 (COMP)
unnamed: C5.1, C6.1, D4.1 (K), R8.2, R22.1, R27.1
unnamed: J5.26, R5.1
unnamed: J10.5, R7.2
unnamed: J19.23, R1.2
unnamed: J19.24, R2.2
unnamed: J20.23, R3.2
unnamed: J20.24, R4.2
unnamed: Q2.4 (G), R16.1
unnamed: Q3.1 (B), R24.1, R25.1
unnamed: Q3.3 (C), R27.2
unnamed: R6.1, R13.2
unnamed: C17.1, R14.1, R15.2, U3.3 (CS)
unnamed: C16.1, R13.1, U3.4 (RC)
unnamed: C27.1, R26.1, U3.7 (VCC)
VCC: C7.1, C8.1, C9.1, C10.1, C11.1, C12.1, C13.1, C14.1, C18.1, C30.1, FB1.1, L4.1, R22.2, R26.2
VIN: C21.1, C22.1, FB1.2, J8.2, J9.3, R5.2, R24.2; also elsewhere on the board
VREF: C15.1, R6.2, R14.2, U3.8 (REF)

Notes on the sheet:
4 tubes of 11 cathodes plus extras
8k6 78mW resistor from B+ to each anode (IN-12B)
Dot C
Dot A
I_{ref, max}=5mA
OUT has 0% duty if COMP is at GND
I_{VCC,max}=25mA
1V@I_{max}
10x
V_{out}=VCC=12V
MSB
20uF
167V
Dot D
f=1.5/RC= =1.5/(41.2k*330p)= =110.33kHz
3.8V
I/O + misc
Demux
CD4028B
V_{f} < 0.92V
Gate driver
I_{out, avg}=Q_{g}*f=11.4nC*110.33kHz=1.26mA
VCC UVLO thresholds 7.2V - 6.9V
V_{pp}=2.45V
The maximum duty cycle limit is set by the ratio of the external oscillator charging resistor RT and the internal oscillator discharge transistor on-resistance
Increase resistor if VCC>12V
SN75468
5V +-1.5%
Boost converter
Dot B
LSB
Open-collector outputs

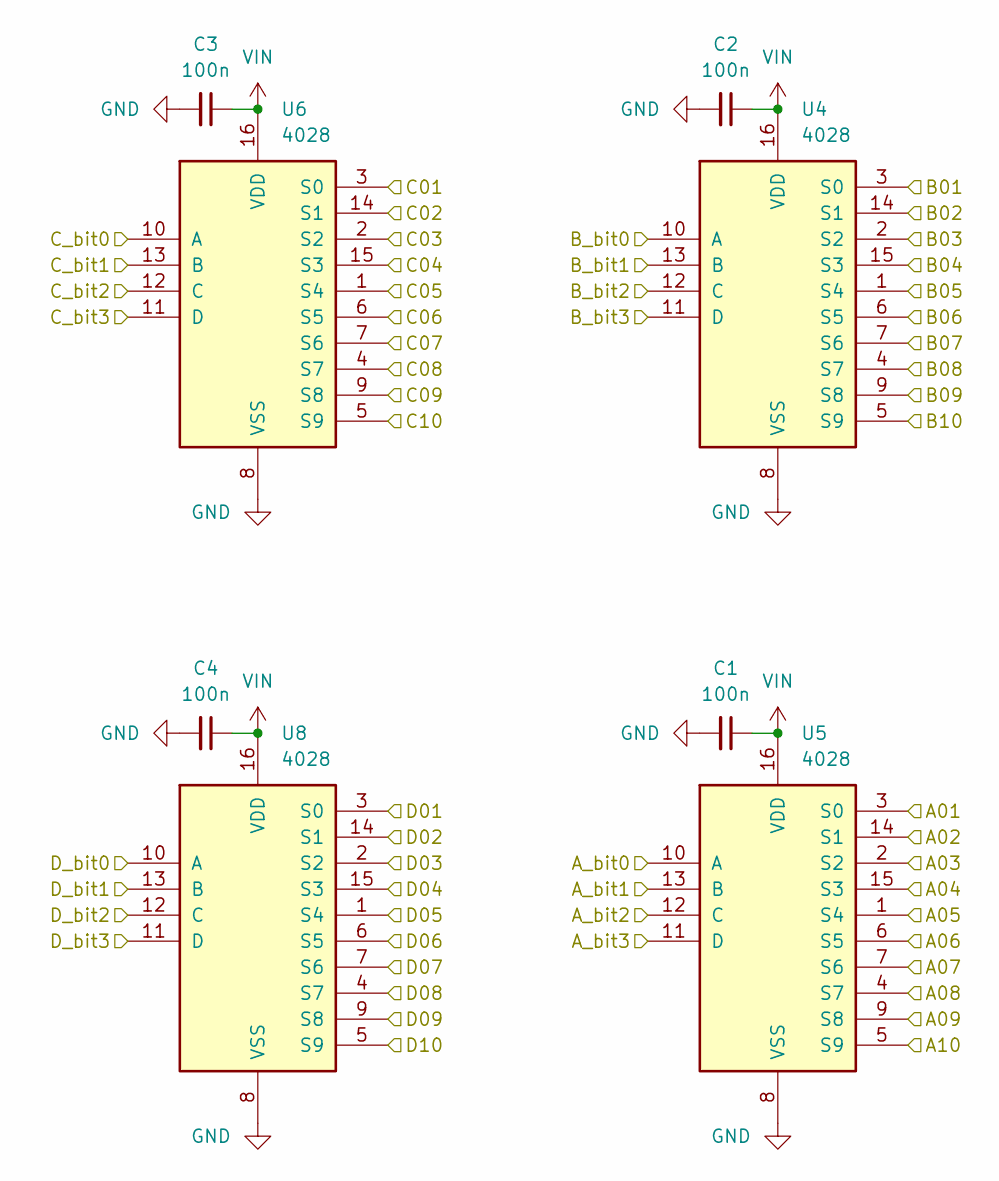
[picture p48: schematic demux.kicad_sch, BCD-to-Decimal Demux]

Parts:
C1, C2, C3, C4: 100n; C_0603_1608Metric
U4, U5, U6, U8: 4028; SOIC-16_3.9x9.9mm_P1.27mm

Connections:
/A_bit0: U5.10 (A); also elsewhere on the board
/A_bit1: U5.13 (B); also elsewhere on the board
/A_bit2: U5.12 (C); also elsewhere on the board
/A_bit3: U5.11 (D); also elsewhere on the board
/B_bit0: U4.10 (A); also elsewhere on the board
/B_bit1: U4.13 (B); also elsewhere on the board
/B_bit2: U4.12 (C); also elsewhere on the board
/B_bit3: U4.11 (D); also elsewhere on the board
/C_bit0: U6.10 (A); also elsewhere on the board
/C_bit1: U6.13 (B); also elsewhere on the board
/C_bit2: U6.12 (C); also elsewhere on the board
/C_bit3: U6.11 (D); also elsewhere on the board
/D_bit0: U8.10 (A); also elsewhere on the board
/D_bit1: U8.13 (B); also elsewhere on the board
/D_bit2: U8.12 (C); also elsewhere on the board
/D_bit3: U8.11 (D); also elsewhere on the board
/DemultiplexerArray/A01: U5.3 (S0); also elsewhere on the board
/DemultiplexerArray/A02: U5.14 (S1); also elsewhere on the board
/DemultiplexerArray/A03: U5.2 (S2); also elsewhere on the board
/DemultiplexerArray/A04: U5.15 (S3); also elsewhere on the board
/DemultiplexerArray/A05: U5.1 (S4); also elsewhere on the board
/DemultiplexerArray/A06: U5.6 (S5); also elsewhere on the board
/DemultiplexerArray/A07: U5.7 (S6); also elsewhere on the board
/DemultiplexerArray/A08: U5.4 (S7); also elsewhere on the board
/DemultiplexerArray/A09: U5.9 (S8); also elsewhere on the board
/DemultiplexerArray/A10: U5.5 (S9); also elsewhere on the board
/DemultiplexerArray/B01: U4.3 (S0); also elsewhere on the board
/DemultiplexerArray/B02: U4.14 (S1); also elsewhere on the board
/DemultiplexerArray/B03: U4.2 (S2); also elsewhere on the board
/DemultiplexerArray/B04: U4.15 (S3); also elsewhere on the board
/DemultiplexerArray/B05: U4.1 (S4); also elsewhere on the board
/DemultiplexerArray/B06: U4.6 (S5); also elsewhere on the board
/DemultiplexerArray/B07: U4.7 (S6); also elsewhere on the board
/DemultiplexerArray/B08: U4.4 (S7); also elsewhere on the board
/DemultiplexerArray/B09: U4.9 (S8); also elsewhere on the board
/DemultiplexerArray/B10: U4.5 (S9); also elsewhere on the board
/DemultiplexerArray/C01: U6.3 (S0); also elsewhere on the board
/DemultiplexerArray/C02: U6.14 (S1); also elsewhere on the board
/DemultiplexerArray/C03: U6.2 (S2); also elsewhere on the board
/DemultiplexerArray/C04: U6.15 (S3); also elsewhere on the board
/DemultiplexerArray/C05: U6.1 (S4); also elsewhere on the board
/DemultiplexerArray/C06: U6.6 (S5); also elsewhere on the board
/DemultiplexerArray/C07: U6.7 (S6); also elsewhere on the board
/DemultiplexerArray/C08: U6.4 (S7); also elsewhere on the board
/DemultiplexerArray/C09: U6.9 (S8); also elsewhere on the board
/DemultiplexerArray/C10: U6.5 (S9); also elsewhere on the board
/DemultiplexerArray/D01: U8.3 (S0); also elsewhere on the board
/DemultiplexerArray/D02: U8.14 (S1); also elsewhere on the board
/DemultiplexerArray/D03: U8.2 (S2); also elsewhere on the board
/DemultiplexerArray/D04: U8.15 (S3); also elsewhere on the board
/DemultiplexerArray/D05: U8.1 (S4); also elsewhere on the board
/DemultiplexerArray/D06: U8.6 (S5); also elsewhere on the board
/DemultiplexerArray/D07: U8.7 (S6); also elsewhere on the board
/DemultiplexerArray/D08: U8.4 (S7); also elsewhere on the board
/DemultiplexerArray/D09: U8.9 (S8); also elsewhere on the board
/DemultiplexerArray/D10: U8.5 (S9); also elsewhere on the board
GND: C1.2, C2.2, C3.2, C4.2, U4.8 (VSS), U5.8 (VSS), U6.8 (VSS), U8.8 (VSS); also elsewhere on the board
VIN: C1.1, C2.1, C3.1, C4.1, U4.16 (VDD), U5.16 (VDD), U6.16 (VDD), U8.16 (VDD); also elsewhere on the board

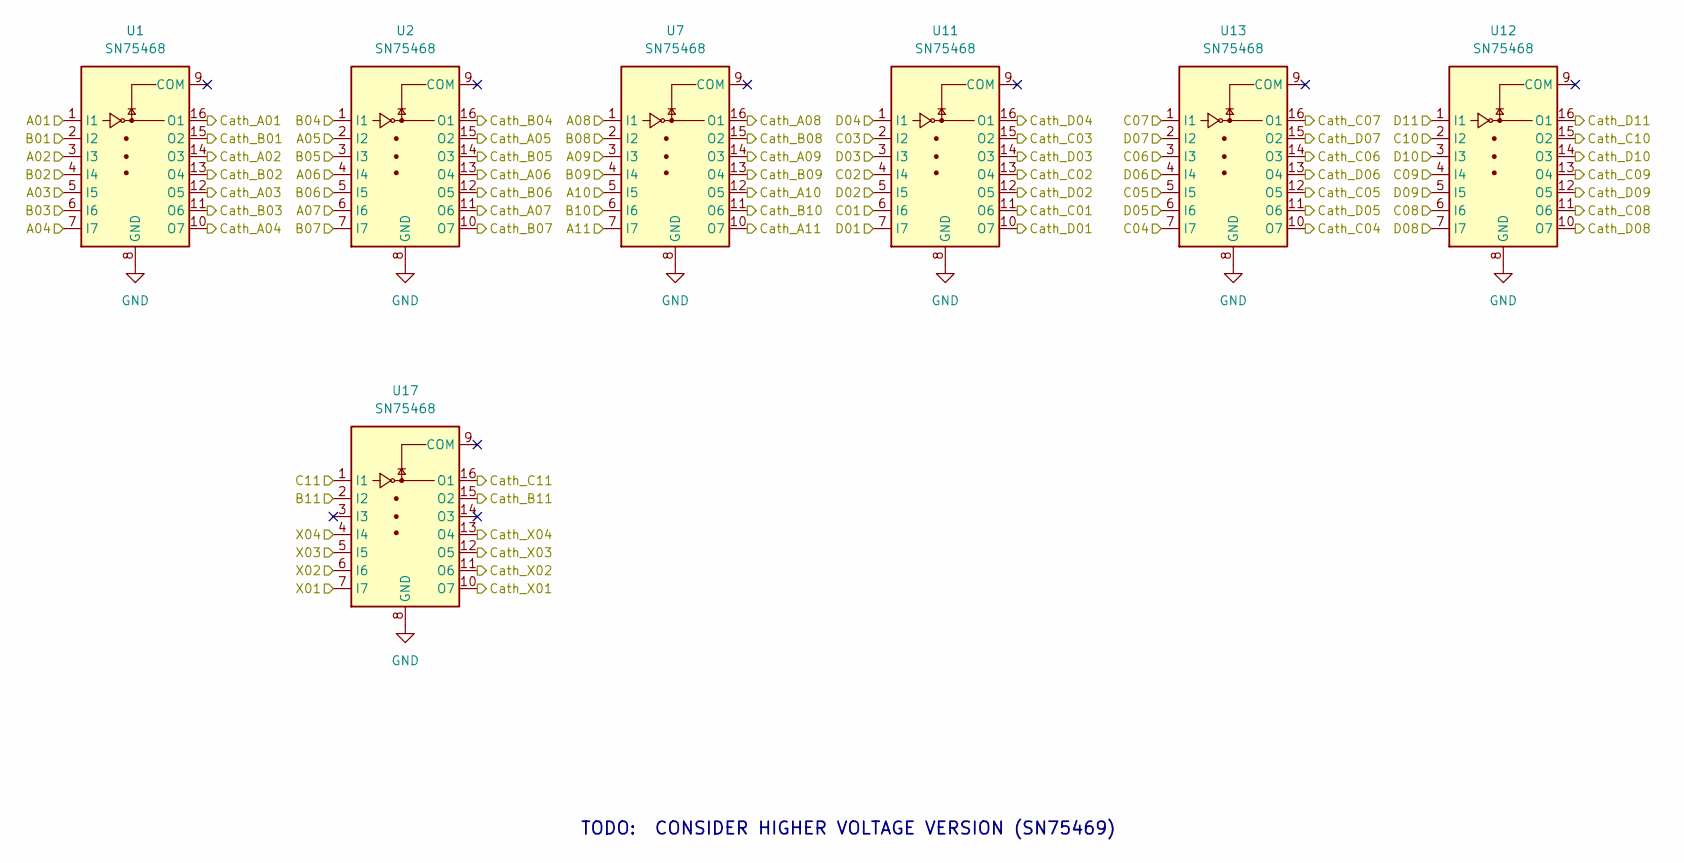
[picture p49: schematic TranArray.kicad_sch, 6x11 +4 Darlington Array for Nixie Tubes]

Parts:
U1, U2, U7, U11, U12, U13, U17: SN75468; SOIC-16_3.9x9.9mm_P1.27mm

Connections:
/A11: U7.7 (I7); also elsewhere on the board
/B11: U17.2 (I2); also elsewhere on the board
/C11: U17.1 (I1); also elsewhere on the board
/D11: U12.1 (I1); also elsewhere on the board
/DemultiplexerArray/A01: U1.1 (I1); also elsewhere on the board
/DemultiplexerArray/A02: U1.3 (I3); also elsewhere on the board
/DemultiplexerArray/A03: U1.5 (I5); also elsewhere on the board
/DemultiplexerArray/A04: U1.7 (I7); also elsewhere on the board
/DemultiplexerArray/A05: U2.2 (I2); also elsewhere on the board
/DemultiplexerArray/A06: U2.4 (I4); also elsewhere on the board
/DemultiplexerArray/A07: U2.6 (I6); also elsewhere on the board
/DemultiplexerArray/A08: U7.1 (I1); also elsewhere on the board
/DemultiplexerArray/A09: U7.3 (I3); also elsewhere on the board
/DemultiplexerArray/A10: U7.5 (I5); also elsewhere on the board
/DemultiplexerArray/B01: U1.2 (I2); also elsewhere on the board
/DemultiplexerArray/B02: U1.4 (I4); also elsewhere on the board
/DemultiplexerArray/B03: U1.6 (I6); also elsewhere on the board
/DemultiplexerArray/B04: U2.1 (I1); also elsewhere on the board
/DemultiplexerArray/B05: U2.3 (I3); also elsewhere on the board
/DemultiplexerArray/B06: U2.5 (I5); also elsewhere on the board
/DemultiplexerArray/B07: U2.7 (I7); also elsewhere on the board
/DemultiplexerArray/B08: U7.2 (I2); also elsewhere on the board
/DemultiplexerArray/B09: U7.4 (I4); also elsewhere on the board
/DemultiplexerArray/B10: U7.6 (I6); also elsewhere on the board
/DemultiplexerArray/C01: U11.6 (I6); also elsewhere on the board
/DemultiplexerArray/C02: U11.4 (I4); also elsewhere on the board
/DemultiplexerArray/C03: U11.2 (I2); also elsewhere on the board
/DemultiplexerArray/C04: U13.7 (I7); also elsewhere on the board
/DemultiplexerArray/C05: U13.5 (I5); also elsewhere on the board
/DemultiplexerArray/C06: U13.3 (I3); also elsewhere on the board
/DemultiplexerArray/C07: U13.1 (I1); also elsewhere on the board
/DemultiplexerArray/C08: U12.6 (I6); also elsewhere on the board
/DemultiplexerArray/C09: U12.4 (I4); also elsewhere on the board
/DemultiplexerArray/C10: U12.2 (I2); also elsewhere on the board
/DemultiplexerArray/D01: U11.7 (I7); also elsewhere on the board
/DemultiplexerArray/D02: U11.5 (I5); also elsewhere on the board
/DemultiplexerArray/D03: U11.3 (I3); also elsewhere on the board
/DemultiplexerArray/D04: U11.1 (I1); also elsewhere on the board
/DemultiplexerArray/D05: U13.6 (I6); also elsewhere on the board
/DemultiplexerArray/D06: U13.4 (I4); also elsewhere on the board
/DemultiplexerArray/D07: U13.2 (I2); also elsewhere on the board
/DemultiplexerArray/D08: U12.7 (I7); also elsewhere on the board
/DemultiplexerArray/D09: U12.5 (I5); also elsewhere on the board
/DemultiplexerArray/D10: U12.3 (I3); also elsewhere on the board
/OutTransistorArray/Cath_A01: U1.16 (O1); also elsewhere on the board
/OutTransistorArray/Cath_A02: U1.14 (O3); also elsewhere on the board
/OutTransistorArray/Cath_A03: U1.12 (O5); also elsewhere on the board
/OutTransistorArray/Cath_A04: U1.10 (O7); also elsewhere on the board
/OutTransistorArray/Cath_A05: U2.15 (O2); also elsewhere on the board
/OutTransistorArray/Cath_A06: U2.13 (O4); also elsewhere on the board
/OutTransistorArray/Cath_A07: U2.11 (O6); also elsewhere on the board
/OutTransistorArray/Cath_A08: U7.16 (O1); also elsewhere on the board
/OutTransistorArray/Cath_A09: U7.14 (O3); also elsewhere on the board
/OutTransistorArray/Cath_A10: U7.12 (O5); also elsewhere on the board
/OutTransistorArray/Cath_A11: U7.10 (O7); also elsewhere on the board
/OutTransistorArray/Cath_B01: U1.15 (O2); also elsewhere on the board
/OutTransistorArray/Cath_B02: U1.13 (O4); also elsewhere on the board
/OutTransistorArray/Cath_B03: U1.11 (O6); also elsewhere on the board
/OutTransistorArray/Cath_B04: U2.16 (O1); also elsewhere on the board
/OutTransistorArray/Cath_B05: U2.14 (O3); also elsewhere on the board
/OutTransistorArray/Cath_B06: U2.12 (O5); also elsewhere on the board
/OutTransistorArray/Cath_B07: U2.10 (O7); also elsewhere on the board
/OutTransistorArray/Cath_B08: U7.15 (O2); also elsewhere on the board
/OutTransistorArray/Cath_B09: U7.13 (O4); also elsewhere on the board
/OutTransistorArray/Cath_B10: U7.11 (O6); also elsewhere on the board
/OutTransistorArray/Cath_B11: U17.15 (O2); also elsewhere on the board
/OutTransistorArray/Cath_C01: U11.11 (O6); also elsewhere on the board
/OutTransistorArray/Cath_C02: U11.13 (O4); also elsewhere on the board
/OutTransistorArray/Cath_C03: U11.15 (O2); also elsewhere on the board
/OutTransistorArray/Cath_C04: U13.10 (O7); also elsewhere on the board
/OutTransistorArray/Cath_C05: U13.12 (O5); also elsewhere on the board
/OutTransistorArray/Cath_C06: U13.14 (O3); also elsewhere on the board
/OutTransistorArray/Cath_C07: U13.16 (O1); also elsewhere on the board
/OutTransistorArray/Cath_C08: U12.11 (O6); also elsewhere on the board
/OutTransistorArray/Cath_C09: U12.13 (O4); also elsewhere on the board
/OutTransistorArray/Cath_C10: U12.15 (O2); also elsewhere on the board
/OutTransistorArray/Cath_C11: U17.16 (O1); also elsewhere on the board
/OutTransistorArray/Cath_D01: U11.10 (O7); also elsewhere on the board
/OutTransistorArray/Cath_D02: U11.12 (O5); also elsewhere on the board
/OutTransistorArray/Cath_D03: U11.14 (O3); also elsewhere on the board
/OutTransistorArray/Cath_D04: U11.16 (O1); also elsewhere on the board
/OutTransistorArray/Cath_D05: U13.11 (O6); also elsewhere on the board
/OutTransistorArray/Cath_D06: U13.13 (O4); also elsewhere on the board
/OutTransistorArray/Cath_D07: U13.15 (O2); also elsewhere on the board
/OutTransistorArray/Cath_D08: U12.10 (O7); also elsewhere on the board
/OutTransistorArray/Cath_D09: U12.12 (O5); also elsewhere on the board
/OutTransistorArray/Cath_D10: U12.14 (O3); also elsewhere on the board
/OutTransistorArray/Cath_D11: U12.16 (O1); also elsewhere on the board
/OutTransistorArray/Cath_X01: U17.10 (O7); also elsewhere on the board
/OutTransistorArray/Cath_X02: U17.11 (O6); also elsewhere on the board
/OutTransistorArray/Cath_X03: U17.12 (O5); also elsewhere on the board
/OutTransistorArray/Cath_X04: U17.13 (O4); also elsewhere on the board
/X01: U17.7 (I7); also elsewhere on the board
/X02: U17.6 (I6); also elsewhere on the board
/X03: U17.5 (I5); also elsewhere on the board
/X04: U17.4 (I4); also elsewhere on the board
GND: U1.8 (GND), U2.8 (GND), U7.8 (GND), U11.8 (GND), U12.8 (GND), U13.8 (GND), U17.8 (GND); also elsewhere on the board

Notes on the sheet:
TODO: CONSIDER HIGHER VOLTAGE VERSION (SN75469)

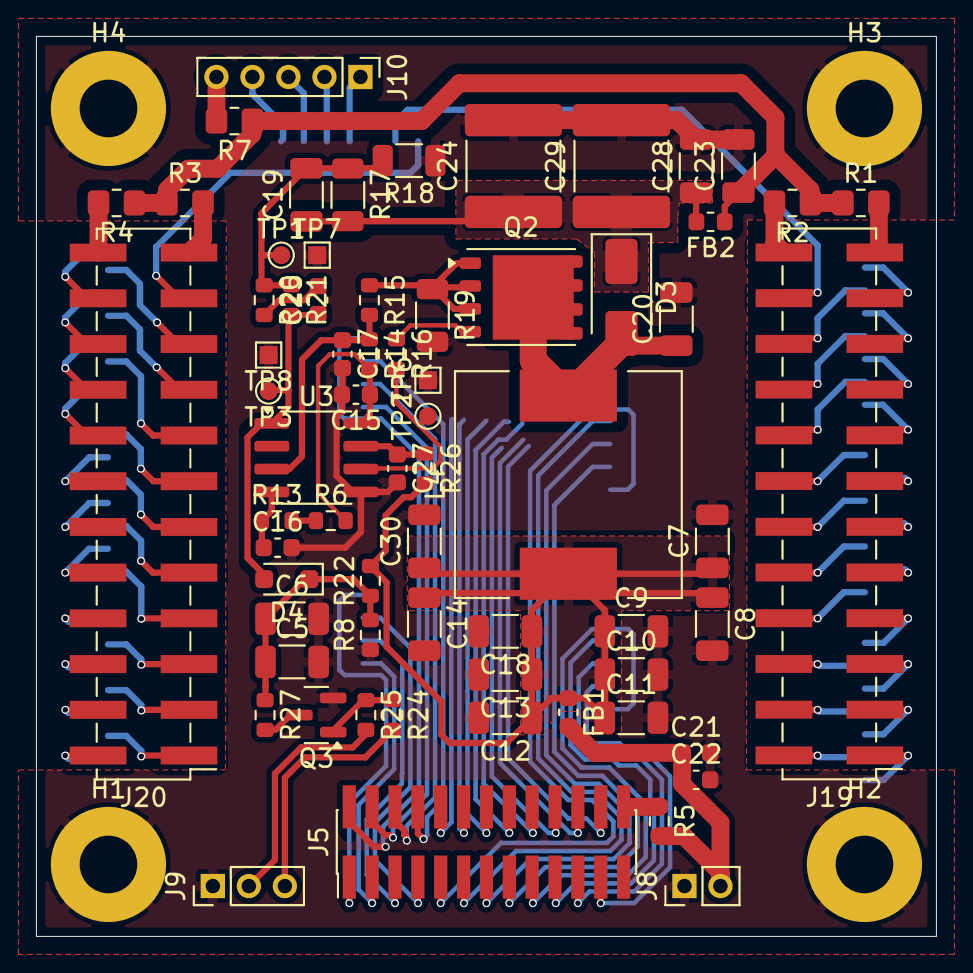
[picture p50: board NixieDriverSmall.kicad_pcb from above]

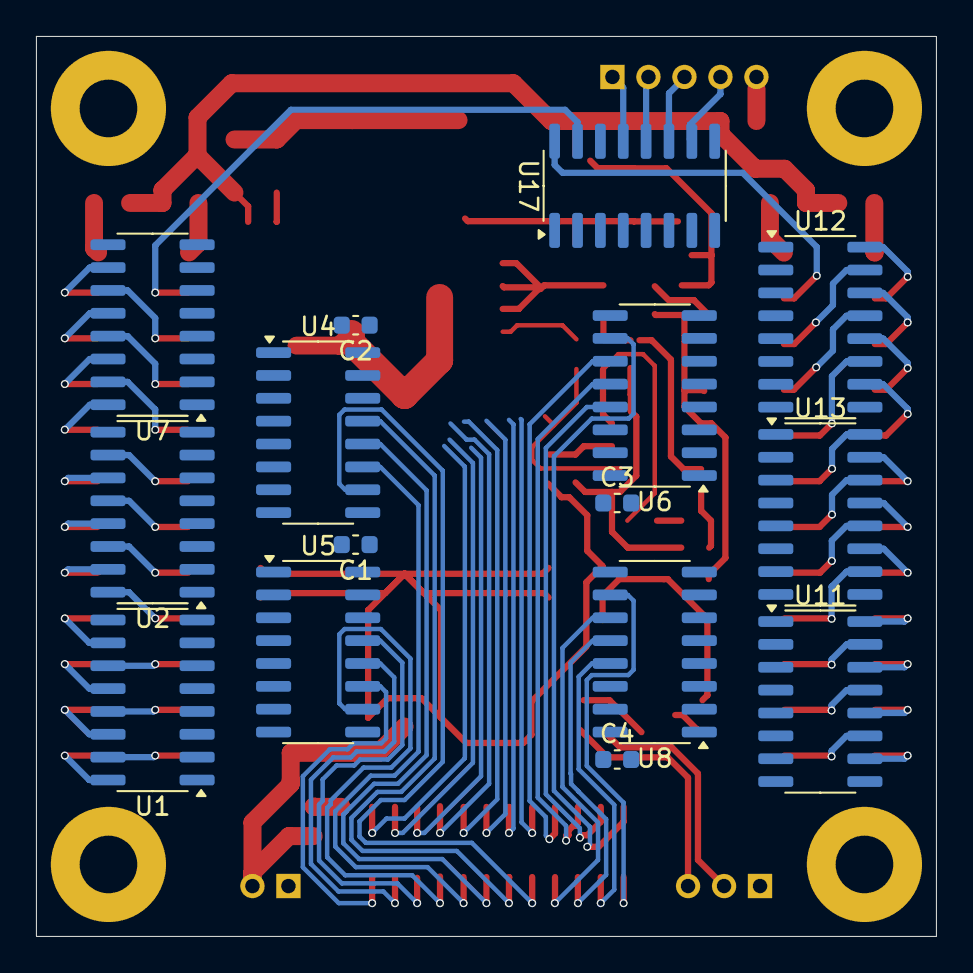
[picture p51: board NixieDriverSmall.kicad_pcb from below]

Board: 8 copper layers, 50.0 x 50.0 mm, 86 parts (15 on the bottom side), 139 nets.

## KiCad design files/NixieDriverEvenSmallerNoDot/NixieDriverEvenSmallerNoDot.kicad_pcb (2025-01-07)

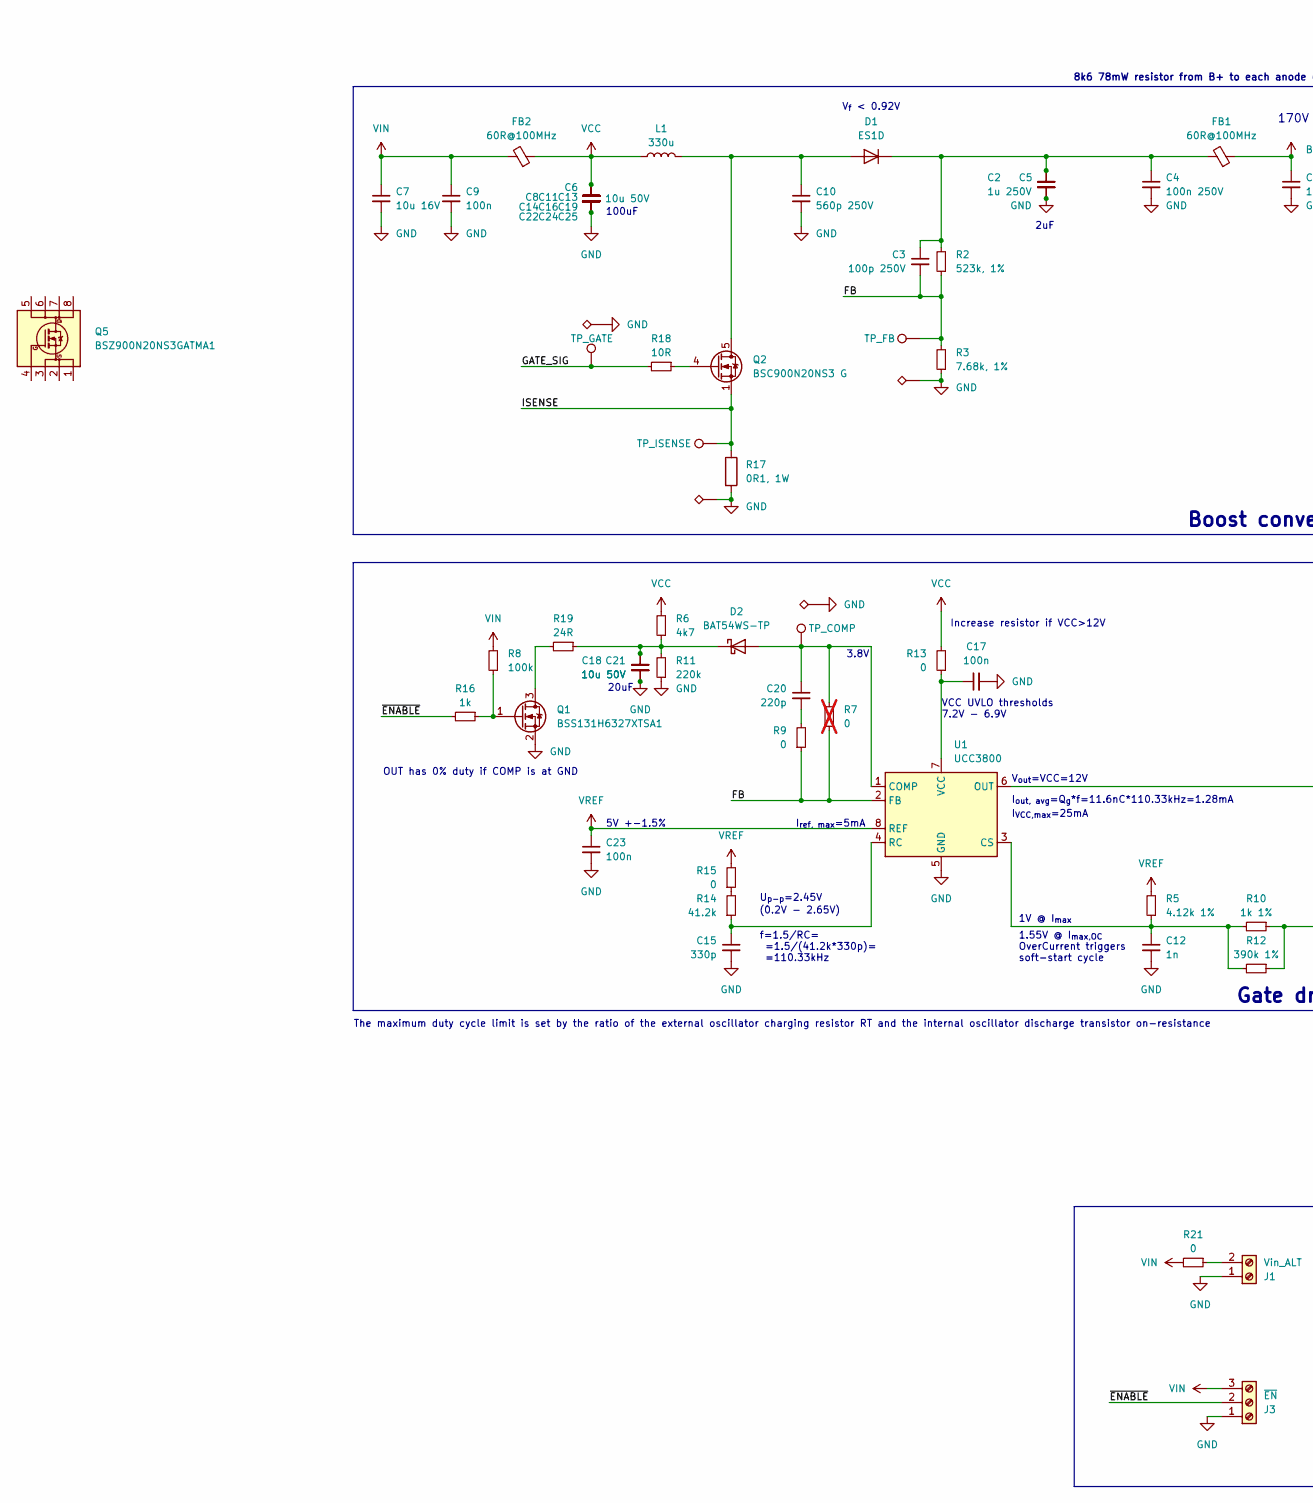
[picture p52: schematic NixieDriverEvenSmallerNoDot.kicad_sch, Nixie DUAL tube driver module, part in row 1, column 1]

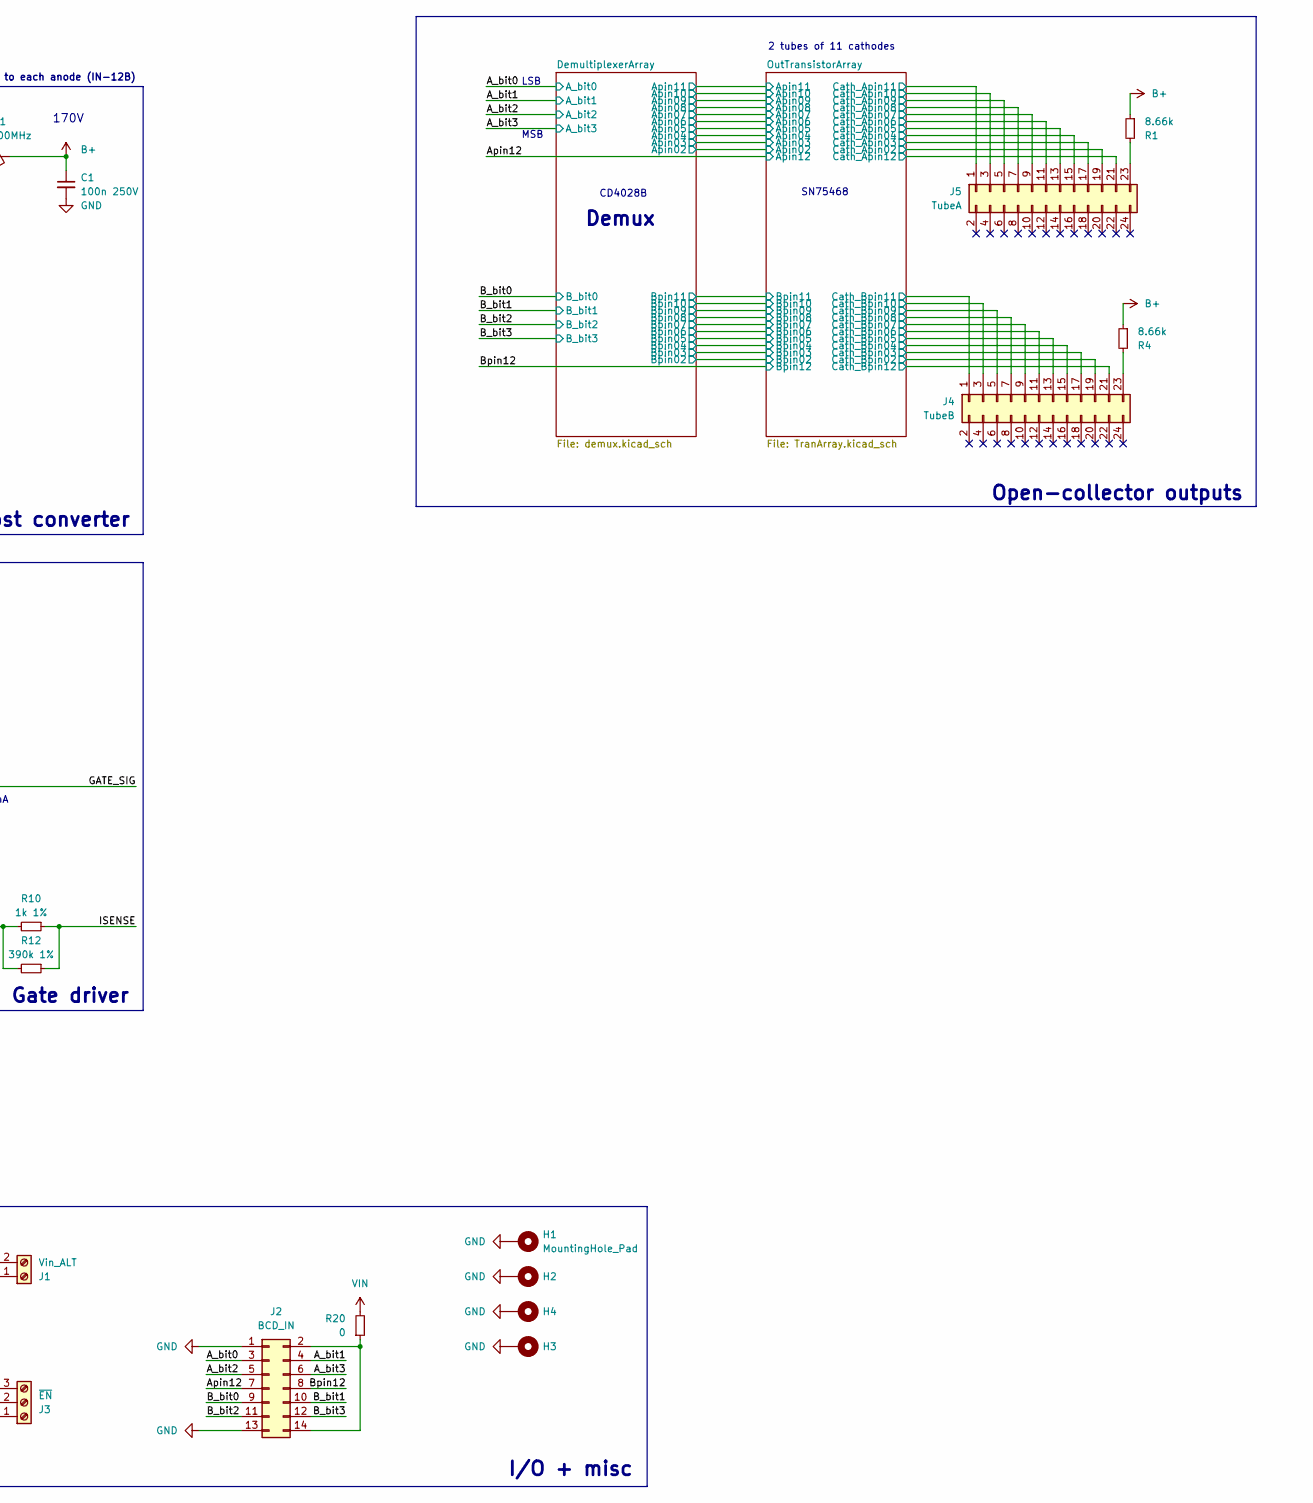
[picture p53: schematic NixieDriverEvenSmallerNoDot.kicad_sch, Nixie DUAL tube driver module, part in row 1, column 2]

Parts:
C1, C4: 100n 250V; C_1206_3216Metric
C2, C5: 1u 250V; C_2220_5750Metric
C3: 100p 250V; C_1206_3216Metric
C6, C8, C11, C13, C14, C16, C18, C19, C21, C22, C24, C25: 10u 50V; C_1206_3216Metric
C7: 10u 16V; C_0603_1608Metric
C9, C17, C23: 100n; C_0603_1608Metric
C10: 560p 250V; C_1206_3216Metric
C12: 1n; C_0603_1608Metric
C15: 330p; C_0603_1608Metric
C20: 220p; C_0603_1608Metric
D1: ES1D; D_SMA
D2: BAT54WS-TP; D_SOD-323_HandSoldering; MPN BAT54WS-7-F
FB1, FB2: 60R@100MHz; L_0603_1608Metric
H1, H2, H3, H4: MountingHole_Pad; MountingHole_3.2mm_M3_Pad
J1: Vin_ALT; PinHeader_1x02_P2.54mm_Vertical
J2: BCD_IN; IDC-Header_2x07_P2.54mm_Vertical
J3: ~{EN}; PinHeader_1x03_P2.54mm_Vertical
J4: TubeB; PinSocket_2x12_P2.54mm_Vertical
J5: TubeA; PinSocket_2x12_P2.54mm_Vertical
L1: 330u; L_12x12mm_H8mm
Q1: BSS131H6327XTSA1; SOT-23
Q2: BSC900N20NS3 G; Infineon_PG-TDSON-8_6.15x5.15mm
Q5: BSZ900N20NS3GATMA1; MPN FDS2672CT-ND
R1, R4: 8.66k; R_1206_3216Metric
R2: 523k, 1%; R_1206_3216Metric
R3: 7.68k, 1%; R_1206_3216Metric
R5: 4.12k 1%; R_0603_1608Metric
R6: 4k7; R_0603_1608Metric
R7: 0; R_0603_1608Metric; not fitted
R8: 100k; R_0603_1608Metric
R9, R13, R15, R20, R21: 0; R_0603_1608Metric
R10: 1k 1%; R_0603_1608Metric
R11: 220k; R_0603_1608Metric
R12: 390k 1%; R_0603_1608Metric
R14: 41.2k; R_0603_1608Metric
R16: 1k; R_0603_1608Metric
R17: 0R1, 1W; R_1206_3216Metric
R18: 10R; R_0603_1608Metric
R19: 24R; R_0603_1608Metric
TP1: TP_FB; TestPoint_Pad_D1.0mm
TP2, TP5, TP7, TP8: TP_GND; TestPoint_Pad_1.0x1.0mm
TP3: TP_GATE; TestPoint_Pad_D1.0mm
TP4: TP_ISENSE; TestPoint_Pad_D1.0mm
TP6: TP_COMP; TestPoint_Pad_D1.0mm
U1: UCC3800; SOIC-8_3.9x4.9mm_P1.27mm

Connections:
/A_bit0: J2.3; also elsewhere on the board
/A_bit1: J2.4; also elsewhere on the board
/A_bit2: J2.5; also elsewhere on the board
/A_bit3: J2.6; also elsewhere on the board
/Apin12: J2.7; also elsewhere on the board
/B_bit0: J2.9; also elsewhere on the board
/B_bit1: J2.10; also elsewhere on the board
/B_bit2: J2.11; also elsewhere on the board
/B_bit3: J2.12; also elsewhere on the board
/Bpin12: J2.8; also elsewhere on the board
/FB: C3.2, R2.1, R3.2, R7.1, R9.1, TP1.1, U1.2 (FB)
/GATE_SIG: R18.2, TP3.1, U1.6 (OUT)
/ISENSE: Q2.1 (S), Q2.2 (S), Q2.3 (S), R10.1, R12.1, R17.1, TP4.1
/OutTransistorArray/Cath_Apin02: J5.19; also elsewhere on the board
/OutTransistorArray/Cath_Apin03: J5.17; also elsewhere on the board
/OutTransistorArray/Cath_Apin04: J5.15; also elsewhere on the board
/OutTransistorArray/Cath_Apin05: J5.13; also elsewhere on the board
/OutTransistorArray/Cath_Apin06: J5.11; also elsewhere on the board
/OutTransistorArray/Cath_Apin07: J5.9; also elsewhere on the board
/OutTransistorArray/Cath_Apin08: J5.7; also elsewhere on the board
/OutTransistorArray/Cath_Apin09: J5.5; also elsewhere on the board
/OutTransistorArray/Cath_Apin10: J5.3; also elsewhere on the board
/OutTransistorArray/Cath_Apin11: J5.1; also elsewhere on the board
/OutTransistorArray/Cath_Apin12: J5.21; also elsewhere on the board
/OutTransistorArray/Cath_Bpin02: J4.19; also elsewhere on the board
/OutTransistorArray/Cath_Bpin03: J4.17; also elsewhere on the board
/OutTransistorArray/Cath_Bpin04: J4.15; also elsewhere on the board
/OutTransistorArray/Cath_Bpin05: J4.13; also elsewhere on the board
/OutTransistorArray/Cath_Bpin06: J4.11; also elsewhere on the board
/OutTransistorArray/Cath_Bpin07: J4.9; also elsewhere on the board
/OutTransistorArray/Cath_Bpin08: J4.7; also elsewhere on the board
/OutTransistorArray/Cath_Bpin09: J4.5; also elsewhere on the board
/OutTransistorArray/Cath_Bpin10: J4.3; also elsewhere on the board
/OutTransistorArray/Cath_Bpin11: J4.1; also elsewhere on the board
/OutTransistorArray/Cath_Bpin12: J4.21; also elsewhere on the board
/~ENABLE: J3.2, R16.2
B+: C1.1, FB1.1, R1.1, R4.1
GND: C1.2, C2.2, C4.2, C5.2, C6.2, C7.2, C8.2, C9.2, C10.2, C11.2, C12.2, C13.2, C14.2, C15.2, C16.2, C17.2, C18.2, C19.2, C21.2, C22.2, C23.2, C24.2, C25.2, H1.1, H2.1, H3.1, H4.1, J1.1, J2.1, J2.13, J3.1, Q1.2 (S), R3.1, R11.1, R17.2, TP2.1, TP5.1, TP7.1, TP8.1, U1.5 (GND); also elsewhere on the board
unnamed: C20.2, R9.2
unnamed: C10.1, D1.2 (A), L1.2, Q2.5 (D)
unnamed: C2.1, C3.1, C4.1, C5.1, D1.1 (K), FB1.2, R2.2
unnamed: C20.1, D2.2 (A), R7.2, TP6.1, U1.1 (COMP)
unnamed: C18.1, C21.1, D2.1 (K), R6.1, R11.2, R19.1
unnamed: J1.2, R21.1
unnamed: J2.2, J2.14, R20.1
unnamed: J4.23, R4.2
unnamed: J5.23, R1.2
unnamed: Q1.3 (D), R19.2
unnamed: Q1.1 (G), R8.1, R16.1
unnamed: Q2.4 (G), R18.1
unnamed: R14.2, R15.1
unnamed: C12.1, R5.1, R10.2, R12.2, U1.3 (CS)
unnamed: C15.1, R14.1, U1.4 (RC)
unnamed: C17.1, R13.1, U1.7 (VCC)
VCC: C6.1, C8.1, C11.1, C13.1, C14.1, C16.1, C19.1, C22.1, C24.1, C25.1, FB2.1, L1.1, R6.2, R13.2
VIN: C7.1, C9.1, FB2.2, J3.3, R8.2, R20.2, R21.2; also elsewhere on the board
VREF: C23.1, R5.2, R15.2, U1.8 (REF)

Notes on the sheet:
2 tubes of 11 cathodes
8k6 78mW resistor from B+ to each anode (IN-12B)
I_{ref, max}=5mA
OUT has 0% duty if COMP is at GND
I_{VCC,max}=25mA
1V @ I_{max}
100uF
V_{out}=VCC=12V
MSB
20uF
170V
1.55V @ I_{max,OC} OverCurrent triggers soft-start cycle
f=1.5/RC= =1.5/(41.2k*330p)= =110.33kHz
3.8V
I/O + misc
Demux
CD4028B
V_{f} < 0.92V
Gate driver
I_{out, avg}=Q_{g}*f=11.6nC*110.33kHz=1.28mA
VCC UVLO thresholds 7.2V - 6.9V
U_{p-p}=2.45V
The maximum duty cycle limit is set by the ratio of the external oscillator charging resistor RT and the internal oscillator discharge transistor on-resistance
Increase resistor if VCC>12V
SN75468
5V +-1.5%
Boost converter
2uF
LSB
(0.2V - 2.65V)
Open-collector outputs

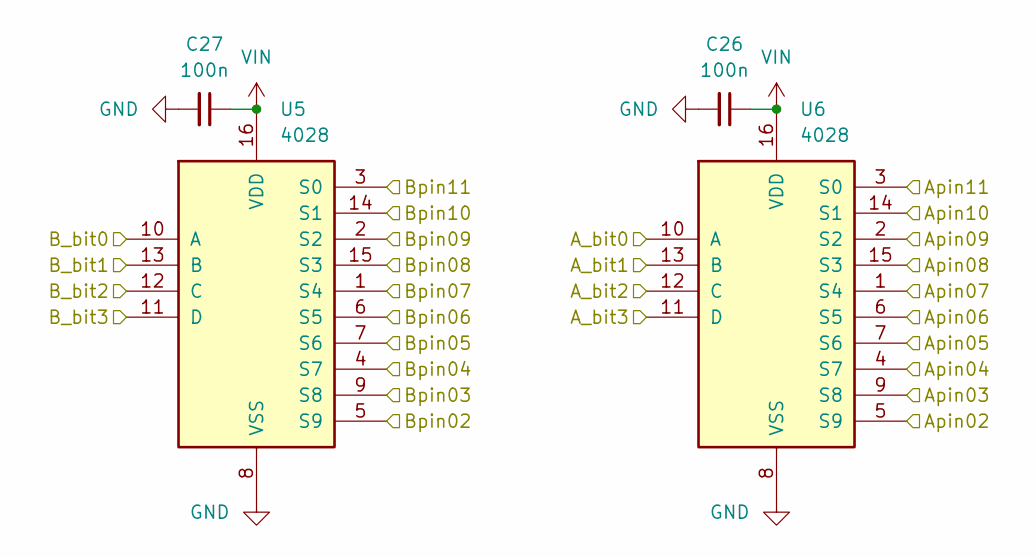
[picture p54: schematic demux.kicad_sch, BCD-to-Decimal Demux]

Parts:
C26, C27: 100n; C_0603_1608Metric
U5, U6: 4028; SOIC-16_3.9x9.9mm_P1.27mm

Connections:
/A_bit0: U6.10 (A); also elsewhere on the board
/A_bit1: U6.13 (B); also elsewhere on the board
/A_bit2: U6.12 (C); also elsewhere on the board
/A_bit3: U6.11 (D); also elsewhere on the board
/B_bit0: U5.10 (A); also elsewhere on the board
/B_bit1: U5.13 (B); also elsewhere on the board
/B_bit2: U5.12 (C); also elsewhere on the board
/B_bit3: U5.11 (D); also elsewhere on the board
/DemultiplexerArray/Apin02: U6.5 (S9); also elsewhere on the board
/DemultiplexerArray/Apin03: U6.9 (S8); also elsewhere on the board
/DemultiplexerArray/Apin04: U6.4 (S7); also elsewhere on the board
/DemultiplexerArray/Apin05: U6.7 (S6); also elsewhere on the board
/DemultiplexerArray/Apin06: U6.6 (S5); also elsewhere on the board
/DemultiplexerArray/Apin07: U6.1 (S4); also elsewhere on the board
/DemultiplexerArray/Apin08: U6.15 (S3); also elsewhere on the board
/DemultiplexerArray/Apin09: U6.2 (S2); also elsewhere on the board
/DemultiplexerArray/Apin10: U6.14 (S1); also elsewhere on the board
/DemultiplexerArray/Apin11: U6.3 (S0); also elsewhere on the board
/DemultiplexerArray/Bpin02: U5.5 (S9); also elsewhere on the board
/DemultiplexerArray/Bpin03: U5.9 (S8); also elsewhere on the board
/DemultiplexerArray/Bpin04: U5.4 (S7); also elsewhere on the board
/DemultiplexerArray/Bpin05: U5.7 (S6); also elsewhere on the board
/DemultiplexerArray/Bpin06: U5.6 (S5); also elsewhere on the board
/DemultiplexerArray/Bpin07: U5.1 (S4); also elsewhere on the board
/DemultiplexerArray/Bpin08: U5.15 (S3); also elsewhere on the board
/DemultiplexerArray/Bpin09: U5.2 (S2); also elsewhere on the board
/DemultiplexerArray/Bpin10: U5.14 (S1); also elsewhere on the board
/DemultiplexerArray/Bpin11: U5.3 (S0); also elsewhere on the board
GND: C26.2, C27.2, U5.8 (VSS), U6.8 (VSS); also elsewhere on the board
VIN: C26.1, C27.1, U5.16 (VDD), U6.16 (VDD); also elsewhere on the board

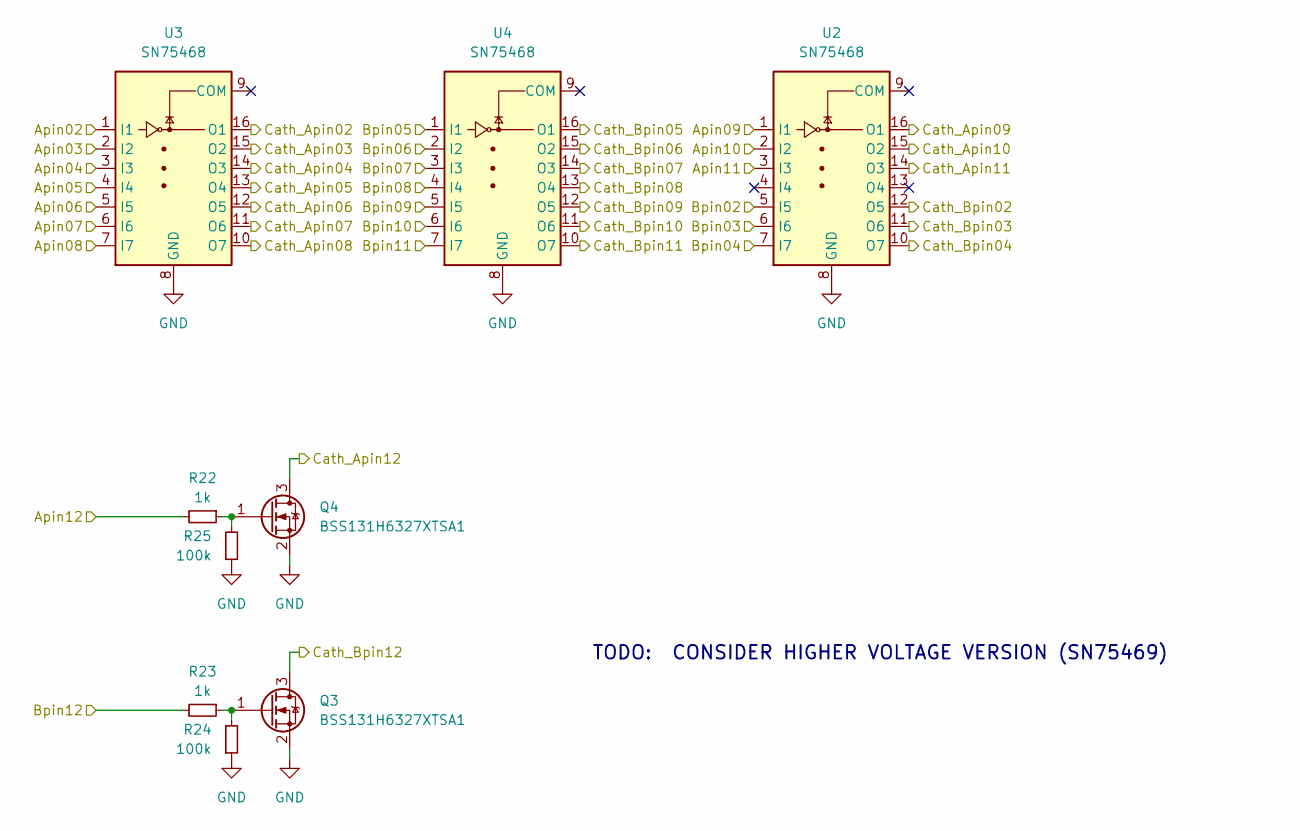
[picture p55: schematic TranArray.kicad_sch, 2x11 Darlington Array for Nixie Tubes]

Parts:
Q3, Q4: BSS131H6327XTSA1; SOT-23
R22, R23: 1k; R_0603_1608Metric
R24, R25: 100k; R_0603_1608Metric
U2, U3, U4: SN75468; SOIC-16_3.9x9.9mm_P1.27mm

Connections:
/Apin12: R22.2; also elsewhere on the board
/Bpin12: R23.2; also elsewhere on the board
/DemultiplexerArray/Apin02: U3.1 (I1); also elsewhere on the board
/DemultiplexerArray/Apin03: U3.2 (I2); also elsewhere on the board
/DemultiplexerArray/Apin04: U3.3 (I3); also elsewhere on the board
/DemultiplexerArray/Apin05: U3.4 (I4); also elsewhere on the board
/DemultiplexerArray/Apin06: U3.5 (I5); also elsewhere on the board
/DemultiplexerArray/Apin07: U3.6 (I6); also elsewhere on the board
/DemultiplexerArray/Apin08: U3.7 (I7); also elsewhere on the board
/DemultiplexerArray/Apin09: U2.1 (I1); also elsewhere on the board
/DemultiplexerArray/Apin10: U2.2 (I2); also elsewhere on the board
/DemultiplexerArray/Apin11: U2.3 (I3); also elsewhere on the board
/DemultiplexerArray/Bpin02: U2.5 (I5); also elsewhere on the board
/DemultiplexerArray/Bpin03: U2.6 (I6); also elsewhere on the board
/DemultiplexerArray/Bpin04: U2.7 (I7); also elsewhere on the board
/DemultiplexerArray/Bpin05: U4.1 (I1); also elsewhere on the board
/DemultiplexerArray/Bpin06: U4.2 (I2); also elsewhere on the board
/DemultiplexerArray/Bpin07: U4.3 (I3); also elsewhere on the board
/DemultiplexerArray/Bpin08: U4.4 (I4); also elsewhere on the board
/DemultiplexerArray/Bpin09: U4.5 (I5); also elsewhere on the board
/DemultiplexerArray/Bpin10: U4.6 (I6); also elsewhere on the board
/DemultiplexerArray/Bpin11: U4.7 (I7); also elsewhere on the board
/OutTransistorArray/Cath_Apin02: U3.16 (O1); also elsewhere on the board
/OutTransistorArray/Cath_Apin03: U3.15 (O2); also elsewhere on the board
/OutTransistorArray/Cath_Apin04: U3.14 (O3); also elsewhere on the board
/OutTransistorArray/Cath_Apin05: U3.13 (O4); also elsewhere on the board
/OutTransistorArray/Cath_Apin06: U3.12 (O5); also elsewhere on the board
/OutTransistorArray/Cath_Apin07: U3.11 (O6); also elsewhere on the board
/OutTransistorArray/Cath_Apin08: U3.10 (O7); also elsewhere on the board
/OutTransistorArray/Cath_Apin09: U2.16 (O1); also elsewhere on the board
/OutTransistorArray/Cath_Apin10: U2.15 (O2); also elsewhere on the board
/OutTransistorArray/Cath_Apin11: U2.14 (O3); also elsewhere on the board
/OutTransistorArray/Cath_Apin12: Q4.3 (D); also elsewhere on the board
/OutTransistorArray/Cath_Bpin02: U2.12 (O5); also elsewhere on the board
/OutTransistorArray/Cath_Bpin03: U2.11 (O6); also elsewhere on the board
/OutTransistorArray/Cath_Bpin04: U2.10 (O7); also elsewhere on the board
/OutTransistorArray/Cath_Bpin05: U4.16 (O1); also elsewhere on the board
/OutTransistorArray/Cath_Bpin06: U4.15 (O2); also elsewhere on the board
/OutTransistorArray/Cath_Bpin07: U4.14 (O3); also elsewhere on the board
/OutTransistorArray/Cath_Bpin08: U4.13 (O4); also elsewhere on the board
/OutTransistorArray/Cath_Bpin09: U4.12 (O5); also elsewhere on the board
/OutTransistorArray/Cath_Bpin10: U4.11 (O6); also elsewhere on the board
/OutTransistorArray/Cath_Bpin11: U4.10 (O7); also elsewhere on the board
/OutTransistorArray/Cath_Bpin12: Q3.3 (D); also elsewhere on the board
GND: Q3.2 (S), Q4.2 (S), R24.1, R25.1, U2.8 (GND), U3.8 (GND), U4.8 (GND); also elsewhere on the board
unnamed: Q3.1 (G), R23.1, R24.2
unnamed: Q4.1 (G), R22.1, R25.2

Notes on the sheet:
TODO: CONSIDER HIGHER VOLTAGE VERSION (SN75469)

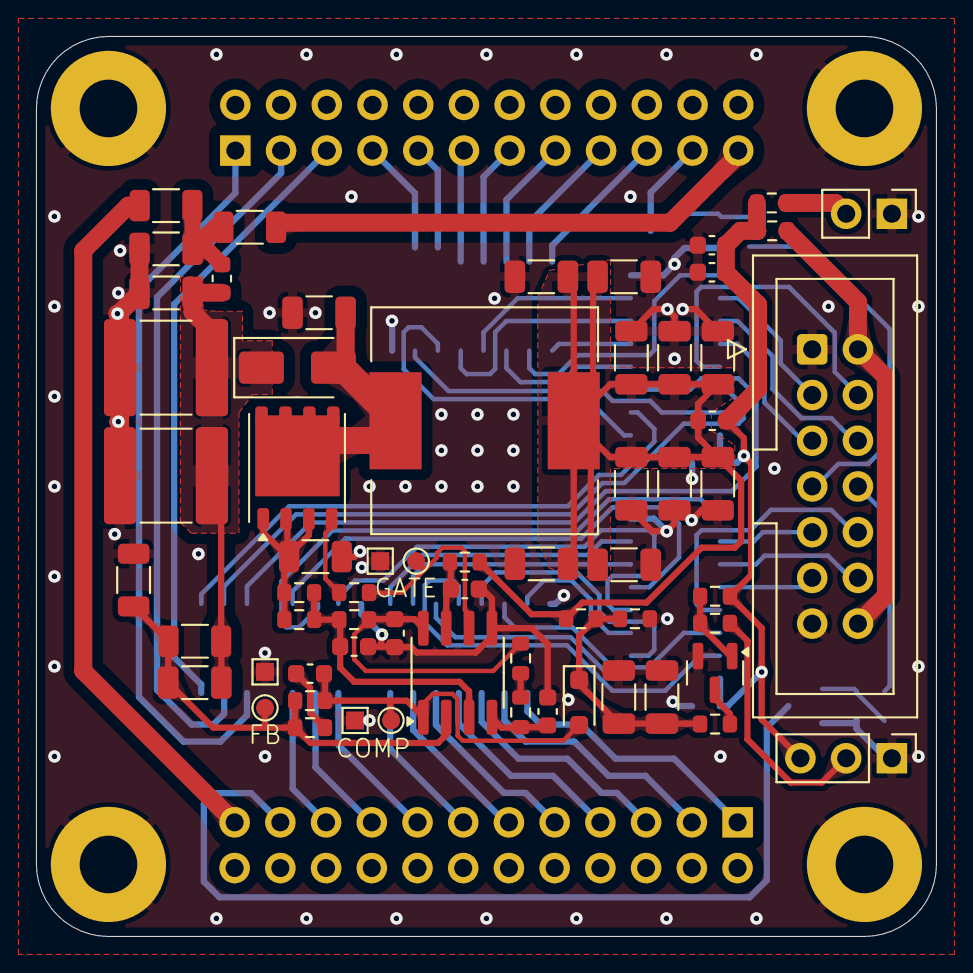
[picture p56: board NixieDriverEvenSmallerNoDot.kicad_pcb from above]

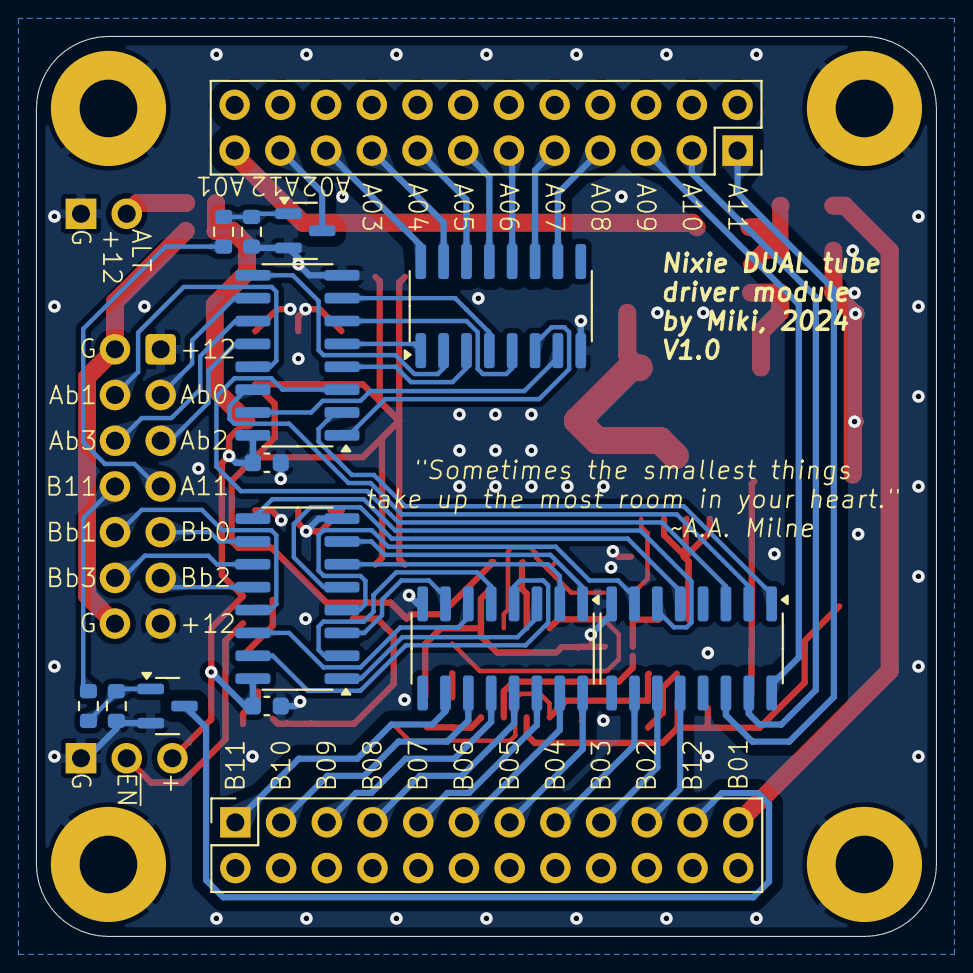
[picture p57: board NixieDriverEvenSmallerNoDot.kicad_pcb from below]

Board: 6 copper layers, 50.0 x 50.0 mm, 82 parts (15 on the bottom side), 79 nets.

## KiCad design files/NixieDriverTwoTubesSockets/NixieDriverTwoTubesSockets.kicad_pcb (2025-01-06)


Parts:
H1, H2, H3, H4: MountingHole_Pad; MountingHole_3.2mm_M3_Pad
J1: TubeA; PinHeader_2x12_P2.54mm_Vertical
J2: TubeB; PinHeader_2x12_P2.54mm_Vertical
NX1, NX2: IN-12BIN-12-DSUB; IN_12B_Socket

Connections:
GND: H1.1, H2.1, H3.1, H4.1
unnamed: J1.2, NX1.2 (0)
unnamed: J1.4, NX1.11 (1)
unnamed: J1.6, NX1.10 (2)
unnamed: J1.8, NX1.9 (3)
unnamed: J1.10, NX1.8 (4)
unnamed: J1.12, NX1.7 (5)
unnamed: J1.14, NX1.6
unnamed: J1.16, NX1.5 (7)
unnamed: J1.18, NX1.4 (8)
unnamed: J1.20, NX1.3 (9)
unnamed: J1.22, NX1.12 (DP)
unnamed: J1.24, NX1.1 (A)
unnamed: J2.2, NX2.2 (0)
unnamed: J2.4, NX2.11 (1)
unnamed: J2.6, NX2.10 (2)
unnamed: J2.8, NX2.9 (3)
unnamed: J2.10, NX2.8 (4)
unnamed: J2.12, NX2.7 (5)
unnamed: J2.14, NX2.6
unnamed: J2.16, NX2.5 (7)
unnamed: J2.18, NX2.4 (8)
unnamed: J2.20, NX2.3 (9)
unnamed: J2.22, NX2.12 (DP)
unnamed: J2.24, NX2.1 (A)



Board: 6 copper layers, 50.0 x 50.0 mm, 8 parts (2 on the bottom side), 25 nets.

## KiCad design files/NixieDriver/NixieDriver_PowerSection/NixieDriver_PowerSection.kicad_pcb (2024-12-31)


Board: 8 copper layers, 50.0 x 50.0 mm, 94 parts (0 on the bottom side), 192 nets, no tracks yet.

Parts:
C1, C2, C3, C4, C5, C6, C15, C22, C27: 100n; C_0603_1608Metric
C7, C8, C9, C10, C11, C12, C13, C14, C18, C30: 10u 50V; C_1206_3216Metric
C16: 330p; C_0603_1608Metric
C17: 1n; C_0603_1608Metric
C19: 100p 250V; C_1206_3216Metric
C20: 560p 250V; C_0805_2012Metric
C21: 100u; C_0603_1608Metric
C23, C28: 100n 250V; C_1206_3216Metric
C24, C29: 1u 250V; C_2220_5750Metric
C25: 220p; C_0603_1608Metric
C26: 47u; C_0603_1608Metric
D3: ES1D; D_SMA
D4: BAT54WS-TP; D_SOD-323_HandSoldering
FB1, FB2: 60R@100MHz; L_0603_1608Metric
H1, H2, H3, H4: MountingHole_Pad; MountingHole_3.2mm_M3_Pad
J7: B+_OUT; PinHeader_1x02_P2.54mm_Vertical
J8: V_IN; PinHeader_1x02_P2.54mm_Vertical
J9: ~{EN}; PinHeader_1x04_P2.00mm_Vertical
J10: Extras; PinHeader_1x05_P2.00mm_Vertical
J19: TubesAB; PinHeader_2x13_P2.00mm_Vertical_SMD
J20: TubesCD; PinHeader_2x13_P2.00mm_Vertical_SMD
J21: TubesEF; PinHeader_2x13_P2.00mm_Vertical_SMD
J22: BCD_IN; PinHeader_2x18_P1.27mm_Vertical_SMD
L4: 330u; L_12x12mm_H8mm
Q2: BSC900N20NS3 G; Infineon_PG-TDSON-8_6.15x5.15mm
Q3: MMBTA42; SOT-23
R1, R2, R3, R4, R5, R6, R7: 8.66k; R_0805_2012Metric_Pad1.20x1.40mm_HandSolder
R8, R20, R21, R26: 0; R_0603_1608Metric
R13: 41.2k; R_0603_1608Metric
R14: 4.12k; R_0603_1608Metric
R15, R25: 1k; R_0603_1608Metric
R16: 10R; R_0603_1608Metric
R17: 634k, 1%; R_1206_3216Metric
R18: 7.68k, 1%; R_1206_3216Metric
R19: 0R1, 1/2W; R_1206_3216Metric
R22: 2k; R_0603_1608Metric
R23, R24: 100k; R_0603_1608Metric
R27: 24R; R_0603_1608Metric
TP1: TP_FB; TestPoint_Pad_D2.0mm
TP2: TP_GATE; TestPoint_Pad_D2.0mm
TP3: TP_COMP; TestPoint_Pad_D2.0mm
TP4: TP_ISENSE; TestPoint_Pad_D2.0mm
TP5: TP_GND; TestPoint_Pad_D2.0mm
U1, U2, U7, U11, U12, U13, U17, U18, U19, U21: SN75468; SOIC-16_3.9x9.9mm_P1.27mm
U3: UCC3800; SOIC-8_3.9x4.9mm_P1.27mm
U4, U5, U6, U8, U9, U10: 4028; SOIC-16_3.9x9.9mm_P1.27mm

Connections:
/A11: J22.26, U2.4 (I4)
/A_bit0: J22.1, U5.10 (A)
/A_bit1: J22.3, U5.13 (B)
/A_bit2: J22.5, U5.12 (C)
/A_bit3: J22.7, U5.11 (D)
/B11: J22.28, U11.1 (I1)
/B_bit0: J22.9, U4.10 (A)
/B_bit1: J22.11, U4.13 (B)
/B_bit2: J22.13, U4.12 (C)
/B_bit3: J22.15, U4.11 (D)
/C11: J22.30, U12.5 (I5)
/C_bit0: J22.17, U6.10 (A)
/C_bit1: J22.19, U6.13 (B)
/C_bit2: J22.21, U6.12 (C)
/C_bit3: J22.23, U6.11 (D)
/D11: J22.32, U17.2 (I2)
/D_bit0: J22.25, U8.10 (A)
/D_bit1: J22.27, U8.13 (B)
/D_bit2: J22.29, U8.12 (C)
/D_bit3: J22.31, U8.11 (D)
/DemultiplexerArray/A01: U1.1 (I1), U5.3 (S0)
/DemultiplexerArray/A02: U1.2 (I2), U5.14 (S1)
/DemultiplexerArray/A03: U1.3 (I3), U5.2 (S2)
/DemultiplexerArray/A04: U1.4 (I4), U5.15 (S3)
/DemultiplexerArray/A05: U1.5 (I5), U5.1 (S4)
/DemultiplexerArray/A06: U1.6 (I6), U5.6 (S5)
/DemultiplexerArray/A07: U1.7 (I7), U5.7 (S6)
/DemultiplexerArray/A08: U2.1 (I1), U5.4 (S7)
/DemultiplexerArray/A09: U2.2 (I2), U5.9 (S8)
/DemultiplexerArray/A10: U2.3 (I3), U5.5 (S9)
/DemultiplexerArray/B01: U2.5 (I5), U4.3 (S0)
/DemultiplexerArray/B02: U2.6 (I6), U4.14 (S1)
/DemultiplexerArray/B03: U2.7 (I7), U4.2 (S2)
/DemultiplexerArray/B04: U4.15 (S3), U7.1 (I1)
/DemultiplexerArray/B05: U4.1 (S4), U7.2 (I2)
/DemultiplexerArray/B06: U4.6 (S5), U7.3 (I3)
/DemultiplexerArray/B07: U4.7 (S6), U7.4 (I4)
/DemultiplexerArray/B08: U4.4 (S7), U7.5 (I5)
/DemultiplexerArray/B09: U4.9 (S8), U7.6 (I6)
/DemultiplexerArray/B10: U4.5 (S9), U7.7 (I7)
/DemultiplexerArray/C01: U6.3 (S0), U11.2 (I2)
/DemultiplexerArray/C02: U6.14 (S1), U11.3 (I3)
/DemultiplexerArray/C03: U6.2 (S2), U11.4 (I4)
/DemultiplexerArray/C04: U6.15 (S3), U11.5 (I5)
/DemultiplexerArray/C05: U6.1 (S4), U11.6 (I6)
/DemultiplexerArray/C06: U6.6 (S5), U11.7 (I7)
/DemultiplexerArray/C07: U6.7 (S6), U12.1 (I1)
/DemultiplexerArray/C08: U6.4 (S7), U12.2 (I2)
/DemultiplexerArray/C09: U6.9 (S8), U12.3 (I3)
/DemultiplexerArray/C10: U6.5 (S9), U12.4 (I4)
/DemultiplexerArray/D01: U8.3 (S0), U12.6 (I6)
/DemultiplexerArray/D02: U8.14 (S1), U12.7 (I7)
/DemultiplexerArray/D03: U8.2 (S2), U13.1 (I1)
/DemultiplexerArray/D04: U8.15 (S3), U13.2 (I2)
/DemultiplexerArray/D05: U8.1 (S4), U13.3 (I3)
/DemultiplexerArray/D06: U8.6 (S5), U13.4 (I4)
/DemultiplexerArray/D07: U8.7 (S6), U13.5 (I5)
/DemultiplexerArray/D08: U8.4 (S7), U13.6 (I6)
/DemultiplexerArray/D09: U8.9 (S8), U13.7 (I7)
/DemultiplexerArray/D10: U8.5 (S9), U17.1 (I1)
/DemultiplexerArray/E01: U9.3 (S0), U17.3 (I3)
/DemultiplexerArray/E02: U9.14 (S1), U17.4 (I4)
/DemultiplexerArray/E03: U9.2 (S2), U17.5 (I5)
/DemultiplexerArray/E04: U9.15 (S3), U17.6 (I6)
/DemultiplexerArray/E05: U9.1 (S4), U17.7 (I7)
/DemultiplexerArray/E06: U9.6 (S5), U18.1 (I1)
/DemultiplexerArray/E07: U9.7 (S6), U18.2 (I2)
/DemultiplexerArray/E08: U9.4 (S7), U18.3 (I3)
/DemultiplexerArray/E09: U9.9 (S8), U18.4 (I4)
/DemultiplexerArray/E10: U9.5 (S9), U18.5 (I5)
/DemultiplexerArray/F01: U10.3 (S0), U18.7 (I7)
/DemultiplexerArray/F02: U10.14 (S1), U19.1 (I1)
/DemultiplexerArray/F03: U10.2 (S2), U19.2 (I2)
/DemultiplexerArray/F04: U10.15 (S3), U19.3 (I3)
/DemultiplexerArray/F05: U10.1 (S4), U19.4 (I4)
/DemultiplexerArray/F06: U10.6 (S5), U19.5 (I5)
/DemultiplexerArray/F07: U10.7 (S6), U19.6 (I6)
/DemultiplexerArray/F08: U10.4 (S7), U19.7 (I7)
/DemultiplexerArray/F09: U10.9 (S8), U21.1 (I1)
/DemultiplexerArray/F10: U10.5 (S9), U21.2 (I2)
/E11: J22.34, U18.6 (I6)
/E_bit0: J22.10, U9.10 (A)
/E_bit1: J22.12, U9.13 (B)
/E_bit2: J22.14, U9.12 (C)
/E_bit3: J22.16, U9.11 (D)
/F11: J22.36, U21.3 (I3)
/FB: C19.2, R17.1, R18.2, R20.1, R21.1, TP1.1, U3.2 (FB)
/F_bit0: J22.2, U10.10 (A)
/F_bit1: J22.4, U10.13 (B)
/F_bit2: J22.6, U10.12 (C)
/F_bit3: J22.8, U10.11 (D)
/GATE_SIG: R16.2, TP2.1, U3.6 (OUT)
/ISENSE: Q2.1 (S), Q2.2 (S), Q2.3 (S), R15.1, R19.1, TP4.1
/OutTransistorArray/Cath_A01: J19.1, U1.16 (O1)
/OutTransistorArray/Cath_A02: J19.3, U1.15 (O2)
/OutTransistorArray/Cath_A03: J19.5, U1.14 (O3)
/OutTransistorArray/Cath_A04: J19.7, U1.13 (O4)
/OutTransistorArray/Cath_A05: J19.9, U1.12 (O5)
/OutTransistorArray/Cath_A06: J19.11, U1.11 (O6)
/OutTransistorArray/Cath_A07: J19.13, U1.10 (O7)
/OutTransistorArray/Cath_A08: J19.15, U2.16 (O1)
/OutTransistorArray/Cath_A09: J19.17, U2.15 (O2)
/OutTransistorArray/Cath_A10: J19.19, U2.14 (O3)
/OutTransistorArray/Cath_A11: J19.21, U2.13 (O4)
/OutTransistorArray/Cath_B01: J19.2, U2.12 (O5)
/OutTransistorArray/Cath_B02: J19.4, U2.11 (O6)
/OutTransistorArray/Cath_B03: J19.6, U2.10 (O7)
/OutTransistorArray/Cath_B04: J19.8, U7.16 (O1)
/OutTransistorArray/Cath_B05: J19.10, U7.15 (O2)
/OutTransistorArray/Cath_B06: J19.12, U7.14 (O3)
/OutTransistorArray/Cath_B07: J19.14, U7.13 (O4)
/OutTransistorArray/Cath_B08: J19.16, U7.12 (O5)
/OutTransistorArray/Cath_B09: J19.18, U7.11 (O6)
/OutTransistorArray/Cath_B10: J19.20, U7.10 (O7)
/OutTransistorArray/Cath_B11: J19.22, U11.16 (O1)
/OutTransistorArray/Cath_C01: J20.1, U11.15 (O2)
/OutTransistorArray/Cath_C02: J20.3, U11.14 (O3)
/OutTransistorArray/Cath_C03: J20.5, U11.13 (O4)
/OutTransistorArray/Cath_C04: J20.7, U11.12 (O5)
/OutTransistorArray/Cath_C05: J20.9, U11.11 (O6)
/OutTransistorArray/Cath_C06: J20.11, U11.10 (O7)
/OutTransistorArray/Cath_C07: J20.13, U12.16 (O1)
/OutTransistorArray/Cath_C08: J20.15, U12.15 (O2)
/OutTransistorArray/Cath_C09: J20.17, U12.14 (O3)
/OutTransistorArray/Cath_C10: J20.19, U12.13 (O4)
/OutTransistorArray/Cath_C11: J20.21, U12.12 (O5)
/OutTransistorArray/Cath_D01: J20.2, U12.11 (O6)
/OutTransistorArray/Cath_D02: J20.4, U12.10 (O7)
/OutTransistorArray/Cath_D03: J20.6, U13.16 (O1)
/OutTransistorArray/Cath_D04: J20.8, U13.15 (O2)
/OutTransistorArray/Cath_D05: J20.10, U13.14 (O3)
/OutTransistorArray/Cath_D06: J20.12, U13.13 (O4)
/OutTransistorArray/Cath_D07: J20.14, U13.12 (O5)
/OutTransistorArray/Cath_D08: J20.16, U13.11 (O6)
/OutTransistorArray/Cath_D09: J20.18, U13.10 (O7)
/OutTransistorArray/Cath_D10: J20.20, U17.16 (O1)
/OutTransistorArray/Cath_D11: J20.22, U17.15 (O2)
/OutTransistorArray/Cath_E01: J21.1, U17.14 (O3)
/OutTransistorArray/Cath_E02: J21.3, U17.13 (O4)
/OutTransistorArray/Cath_E03: J21.5, U17.12 (O5)
/OutTransistorArray/Cath_E04: J21.7, U17.11 (O6)
/OutTransistorArray/Cath_E05: J21.9, U17.10 (O7)
/OutTransistorArray/Cath_E06: J21.11, U18.16 (O1)
/OutTransistorArray/Cath_E07: J21.13, U18.15 (O2)
/OutTransistorArray/Cath_E08: J21.15, U18.14 (O3)
/OutTransistorArray/Cath_E09: J21.17, U18.13 (O4)
/OutTransistorArray/Cath_E10: J21.19, U18.12 (O5)
/OutTransistorArray/Cath_E11: J21.21, U18.11 (O6)
/OutTransistorArray/Cath_F01: J21.2, U18.10 (O7)
/OutTransistorArray/Cath_F02: J21.4, U19.16 (O1)
/OutTransistorArray/Cath_F03: J21.6, U19.15 (O2)
/OutTransistorArray/Cath_F04: J21.8, U19.14 (O3)
/OutTransistorArray/Cath_F05: J21.10, U19.13 (O4)
/OutTransistorArray/Cath_F06: J21.12, U19.12 (O5)
/OutTransistorArray/Cath_F07: J21.14, U19.11 (O6)
/OutTransistorArray/Cath_F08: J21.16, U19.10 (O7)
/OutTransistorArray/Cath_F09: J21.18, U21.16 (O1)
/OutTransistorArray/Cath_F10: J21.20, U21.15 (O2)
/OutTransistorArray/Cath_F11: J21.22, U21.14 (O3)
/OutTransistorArray/Cath_X01: J10.1, U21.13 (O4)
/OutTransistorArray/Cath_X02: J10.2, U21.12 (O5)
/OutTransistorArray/Cath_X03: J10.3, U21.11 (O6)
/OutTransistorArray/Cath_X04: J10.4, U21.10 (O7)
/X01: J22.18, U21.4 (I4)
/X02: J22.20, U21.5 (I5)
/X03: J22.22, U21.6 (I6)
/X04: J22.24, U21.7 (I7)
/~ENABLE: J9.2, R25.2
B+: C23.1, FB2.1, J7.2, R1.1, R2.1, R3.1, R4.1, R5.1, R6.1, R7.1
GND: C1.2, C2.2, C3.2, C4.2, C5.2, C6.2, C7.2, C8.2, C9.2, C10.2, C11.2, C12.2, C13.2, C14.2, C15.2, C16.2, C17.2, C18.2, C20.2, C21.2, C22.2, C23.2, C24.2, C26.2, C27.2, C28.2, C29.2, C30.2, H1.1, H2.1, H3.1, H4.1, J7.1, J8.1, J9.1, J22.35, Q3.2 (E), R18.1, R19.2, R23.1, TP5.1, U1.8 (GND), U2.8 (GND), U3.5 (GND), U4.8 (VSS), U5.8 (VSS), U6.8 (VSS), U7.8 (GND), U8.8 (VSS), U9.8 (VSS), U10.8 (VSS), U11.8 (GND), U12.8 (GND), U13.8 (GND), U17.8 (GND), U18.8 (GND), U19.8 (GND), U21.8 (GND)
unnamed: C25.2, R20.2
unnamed: C20.1, D3.2 (A), L4.2, Q2.5 (D)
unnamed: C19.1, C24.1, C28.1, C29.1, D3.1 (K), FB2.2, R17.2
unnamed: C25.1, D4.2 (A), R21.2, TP3.1, U3.1 (COMP)
unnamed: C26.1, D4.1 (K), R22.1, R23.2, R27.1
unnamed: J10.5, R7.2
unnamed: J19.25, R1.2
unnamed: J19.26, R2.2
unnamed: J20.25, R3.2
unnamed: J20.26, R4.2
unnamed: J21.25, R5.2
unnamed: J21.26, R6.2
unnamed: J22.33, R8.1
unnamed: Q2.4 (G), R16.1
unnamed: Q3.1 (B), R24.1, R25.1
unnamed: Q3.3 (C), R27.2
unnamed: C17.1, R14.1, R15.2, U3.3 (CS)
unnamed: C16.1, R13.1, U3.4 (RC)
unnamed: C27.1, R26.1, U3.7 (VCC)
VCC: C7.1, C8.1, C9.1, C10.1, C11.1, C12.1, C13.1, C14.1, C18.1, C30.1, FB1.1, L4.1, R26.2
VIN: C1.1, C2.1, C3.1, C4.1, C5.1, C6.1, C21.1, C22.1, FB1.2, J8.2, J9.3, R8.2, R22.2, R24.2, U4.16 (VDD), U5.16 (VDD), U6.16 (VDD), U8.16 (VDD), U9.16 (VDD), U10.16 (VDD)
VREF: C15.1, R13.2, R14.2, U3.8 (REF)

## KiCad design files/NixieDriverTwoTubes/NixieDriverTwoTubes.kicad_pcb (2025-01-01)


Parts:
H1, H2, H3, H4: MountingHole_Pad; MountingHole_3.2mm_M3_Pad
J1: TubeA; PinHeader_2x12_P2.54mm_Vertical
J2: TubeB; PinHeader_2x12_P2.54mm_Vertical
NX1, NX2: IN-12BIN-12-DSUB; nixies-us-IN-12-DSUB

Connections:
GND: H1.1, H2.1, H3.1, H4.1
unnamed: J1.1, J1.2, NX1.0
unnamed: J1.3, J1.4, NX1.1
unnamed: J1.5, J1.6, NX1.2
unnamed: J1.7, J1.8, NX1.3
unnamed: J1.9, J1.10, NX1.4
unnamed: J1.11, J1.12, NX1.5
unnamed: J1.13, J1.14, NX1.6
unnamed: J1.15, J1.16, NX1.7
unnamed: J1.17, J1.18, NX1.8
unnamed: J1.19, J1.20, NX1.9
unnamed: J1.21, J1.22, NX1.LHDP
unnamed: J1.23, J1.24, NX1.A
unnamed: J2.1, J2.2, NX2.0
unnamed: J2.3, J2.4, NX2.1
unnamed: J2.5, J2.6, NX2.2
unnamed: J2.7, J2.8, NX2.3
unnamed: J2.9, J2.10, NX2.4
unnamed: J2.11, J2.12, NX2.5
unnamed: J2.13, J2.14, NX2.6
unnamed: J2.15, J2.16, NX2.7
unnamed: J2.17, J2.18, NX2.8
unnamed: J2.19, J2.20, NX2.9
unnamed: J2.21, J2.22, NX2.LHDP
unnamed: J2.23, J2.24, NX2.A



Board: 2 copper layers, 50.0 x 50.0 mm, 8 parts (2 on the bottom side), 25 nets.

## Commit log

2024-12-31 Include KiCad directories
    [NixieDriverEvenSmaller.kicad_pcb, NixieDriverEvenSmaller.kicad_sch, NixieDriverEvenSmallerNoDot.kicad_pcb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]
2025-01-01 Add NixieDriverTwoTubesSockets
    [NixieDriverTwoTubes.kicad_pcb, NixieDriverTwoTubesSockets.kicad_pcb, NixieDriverTwoTubesSockets.kicad_sch]
2025-01-01 Img update
    [NixieDriverTwoTubes.kicad_pcb]
2025-01-06 Update feedback
    [NixieDriverEvenSmallerNoDot.kicad_pcb, NixieDriverEvenSmallerNoDot.kicad_sch, NixieDriverTwoTubesSockets.kicad_pcb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]
2025-01-07 Reset and reannotate
    [NixieDriverEvenSmaller.kicad_pcb, NixieDriverEvenSmaller.kicad_sch, NixieDriverEvenSmallerNoDot.kicad_pcb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]
